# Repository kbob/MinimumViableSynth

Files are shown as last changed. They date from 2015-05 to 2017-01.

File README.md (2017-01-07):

# MinimumViableSynth

A virtual analog synthesizer with lots of knobs and buttons.

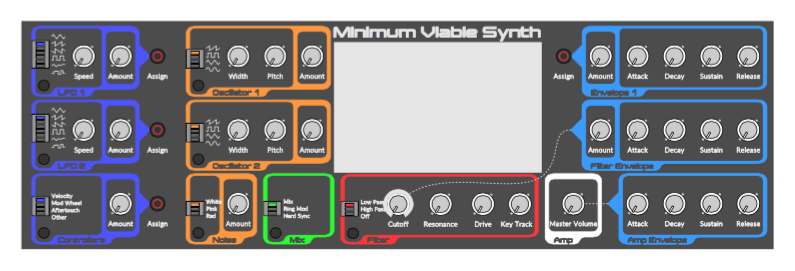
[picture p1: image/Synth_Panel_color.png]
front panel image


This is a polyphonic, monotimbral, virtual analog synth.  The audio
engine runs as an Apple Audio Unit on a Macintosh.  The control panel,
shown here, will provide dedicated controls for most of the synth's
functions.

assembly animation

The end goal is a self contained keyboard synth with knobs and buttons
with the classic connections: audio out, MIDI in/out, USB MIDI in/out.
I am getting there in three phases.

  * **Phase 1** (complete 2015-01-01): Softsynth.  The audio engine
    runs as an Audio Unit on a Mac.  It accepts MIDI messages and
    produces beautiful polyphonic analog sounds.  Or gritty,
    disturbing analog sounds.  It plugs in to DAW software (I use
    Logic Pro X).
    
  * **Phase 2** (in progress): Knobs and buttons.  I am designing and
    building a front panel (see above) with knobs, buttons, and an LCD
    touchscreen.  The goal is to make it as easy as possible to
    understand what the synth is doing at any time.

  * **Phase 3** (future): Stand-alone.  Build an enclosure that houses
    a keyboard, the knob and button panel, I/O jacks, and a processor
    (TBD) that can run the audio engine.  I'm looking at FPGAs...

## Why?

Learn stuff.  Music theory, DSP, PCB layout, CAD and machining, more.

## Status

Check out synth-notes.txt for my thoughts as I worked things out.

#### January 7, 2017:

I built 8 slave modules: the LFOs, the Controllers module, the
oscillators, the noise source, mixer, and filter.  I've since killed
the filter module, and one of the oscillators' LED has burnt out its
red component.  I have parts and tools to repair those; just haven't
done it yet.

I have working UI for the knobs and buttons.  Specifically, routing
between modulators and targets works, complete with lighting effects.

I made an enclosure from aluminum sheet and melamine end blocks, as
illustrated above.  It is flimsy, though, so that needs to be re-done.

I had the master, slaves, and LCD panel connected via a breadboard.
The breadboard wiring got flaky, so I stopped to design a PCB.  The
PCB snaps onto the back of the Discovery board, It routes video to the
LCD touch screen, SPI to the slaves, and serial MIDI to a future MIDI
I/O board.

I am currently designing the graphics for the LCD panel.

(Over a year since the last update.  Oops.)

#### December 17, 2015:

Three slave modules have been built.  (LFO1, LFO2, Controllers.)  All
the slave module PCBs are fabricated.

The master-slave communications are working over SPI.  The master
generates MIDI events.
[I can push a button on a slave and hear its effect on the audio
engine.](https://www.youtube.com/watch?v=dZsXk2Zf6Bg)

I blew up one of the LFO modules, probably with static discharge.  I
repaired it (swapped in a new Teensy LC), and it works now.  It was an
ugly repair.

Current tasks:

  + generating more MIDI events
  + experimenting with the LED animation
  + soldering up the rest of the slave modules
  + designing backing plates for the new slave modules

#### August 14, 2015:

The audio engine has been stable since January, though it does not
exactly match the front panel's feature set.

The front panel was fabricated in July.  I used a sheet of acrylic,
painted the underside black, then engraved the artwork through the
paint with a laser cutter.  Then the same laser cutter cut all the
holes for the controls.  It looks sharp, but not mass produced.
I got the work done at [InHaus Fabrication](http://inhausfabrication.com/).

There is a master microcontroller, an STM32F429, and each module has a
slave controller, a Teensy-LC.  Each slave directly drives a few
knobs, buttons, and LEDs.  The master will coordinate all the slaves
and provide the MIDI over USB interface.  I am currently writing SPI
drivers for master-slave communication.

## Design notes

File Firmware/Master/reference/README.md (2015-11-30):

This is a spreadsheet in Apple Numbers format.  (Proprietary, but I
like it.)

Each SPI bus's signals can be mapped to several pins.  Those are
recorded.

The 144 pin chip does not bring out pins PH2 and above.  Those are
shaded red.

Most of the pins are connected to a peripheral on the STM32F429IDISCOVERY
board.  The pins that are not used are shaded blue in the spreadsheet.
Some, but not all, of the used pins are labeled in the Discovery column.

The notes column shows how I plan to use the pins, especially the
SPI slave select pins.

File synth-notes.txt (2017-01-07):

2017-01-06
Bode Plots

Notes on generating Bode plots.
http://www.onmyphd.com/?p=bode.plot

----------------------------------
2017-01-05
Color spaces

http://www.poynton.com/PDFs/ColorFAQ.pdf

https://blog.noctua-software.com/procedural-colors-for-game.html

http://devmag.org.za/2012/07/29/how-to-choose-colours-procedurally-algorithms/

http://www.tigercolor.com/color-lab/color-theory/color-theory-intro.htm

http://www.brucelindbloom.com/

R'G'B' is a standardized RGB based on D50 white.
CIE X'Y'Z' is the perceptual color space.
CIE L*u*v* maps it onto a cube.
CIE L*C*h° maps it onto a cylinder.  Like perceptual HSV.

    Xn, Yn, Zn = (1, 1, 1)

    def RGB_to_XYZ(r, g, b):
        def linearize_rgb(r, g, b):
            ɣ = 2.2
            κ = 903.3
            def compand(v):
                if V <= 0.08:
                    return 100 * V / κ
                else:
                    return ((v + 0.055) / 1.055)**2.4
            r, g, b = r**ɣ, g**ɣ, b**ɣ
            r, g, b = [compand(v) for v in (r, g, b)]
            return (r, g, b)

        r, g, b = linearize_rgb(r, g, b)
        M = [[0.412453, 0.357580, 0.180423],
             [0.212671, 0.715160, 0.072169],
             [0.019334, 0.119193, 0.939555]]
        X, Y, Z = [sum(M[i][j] * R[j] for j in range(3)) for i in range(3)]
        return (X, Y, Z)

    def XYZ_to_Luv(X, Y, Z):
        def L_star(Y):
            if 0.008856 < Y / Yn:
                return 116 * (Y / Yn)**(1/3) - 16
            else:
                return 903.3 * (Y / Yn)
        def u_prime(X, Y, Z):
            return 4 * X / (X + 15 * Y + 3 * Z)
        def v_prime(X, Y, Z):
            return 9 * Y / (X + 15 * Y + 3 * Z)
        upn, vpn = u_prime(Xn, Yn, Zn), v_prime(Xn, Yn, Zn)
        up,  vp  = u_prime(X,  Y,  Z ), v_prime(X,  Y,  Z )
        L = L_star(Y)
        u = 13 * L * (up - upn)
        v = 13 * L * (vp - vpn)

    def XYZ_to_Lab(X, Y, Z):
        L, u, v = XYZ_to_Luv(X, Y, Z)
        a = 500 * ((X / Xn)**(1/3) - (Y / Yn)**(1/3))
        b = 200 * ((Y / Yn)**(1/3) - (Z / Zn)**(1/3))
        return (L, a, b)

    def Lab_to_LCh(L, a, b):
        C = sqrt(a**2 + b**2)
        h = atan(b / a)
        return (L, C, h)

----------------------------------
2016-12-16
Hand-editing KiCad PCBs

This command will remove all traces and vias.

   sed -i.bak -e '/(segment /d' -e '/(via /d' [^_]*.kicad_pcb

----------------------------------
2016-12-16
I/O Daughter Board revisions

The IODB v1.0 does not work.  Time to make v1.1.

Desired changes:

  - change solder mask clearance to keep from exposing ground plane.
  - change ground plane clearances to match 1bitsy or bmp.
    1Bitsy clearances:
      Solder mask clearance: 0.05mm
      Solder paste clearance: 0
      Zones (all):
        Clearance: 0.15mm
        Minimum width: 0.15mm
        Antipad clearance: 0.15mm
        Spoke width: 0.16mm
        Segments: 16
    BMPMv2.1b clearances:
      Solder mask clearance: ?
      Solder paste clearance: ?
      GND zone F.cu:
        Clearance: 0.2
        Minimum width: 0.2
        Antipad clearance: 0.2
        Spoke width: 0.21
      GND zone B.cu:
        Clearance: 0.2
        Minimum width: 0.2
        Antipad clearance: 0.2
        Spoke width: 0.25
  - move J1 beside J2.
  - relabel J1 and J2.
  - J1 pad has no solder paste cutout.
  - use a different connector for J2.
      Hirose FH12A-40S-0.5SH(55)
      HFK140CT-ND
  - use bigger chips for U11 and U12.
      SN74LV1T34DBVR
      296-37176-1-ND
  - increment the version number.
  - order board
  - order more parts...
      J2       HFK140CT-ND
      U3-U9    568-8285-5-ND
      U6       497-8387-1-ND
      U11 U12  296-37176-1-ND
      buttons  732-7004-1-ND
      10K 0603 311-10KGRTR-ND
  - order stencil

----------------------------------
2016-11-28
I/O Daughter Board silkscreen

72 dpi mockup:
   mockup is too big!  board is 472 px high, should be 66 mm.
   scale = 2.522.
   "Minimum Viable Synth" - Jupiter 90 pix, each line indented 5 spaces
   "V1.0", URL - Jupiter 15 pix.
   "Viable" - border, 1 pix.
   Align baseline of "V1.0" with descender of Synth
   Align left edge of "V1.0" with left edge of "Minimum"

3600 DPI actual artwork:
    90 * 50 / scale = 1783
    15 * 50 / scale = 297
    border width 16.

----------------------------------
2016-11-14
I/O Daughter Board Errata

As of commit e53f5b, I see eleven errors in the schematic.

 * LED_K is also called BKLT_K.
 * LED_A is also called BKLT_A.
 * CTOUCH_INT is not connected to the master.
 * CTOUCH_WAKE is not connected to the master.
 * SLV5A_MISO is also called SLV5A_MISO_Fred.
 * PWR_SENS is not connected to the master.
 * There are no power flags.
 * Vdd on Master port P1 should probably not be a power rail.
 * There are no bypass capacitors on the SPI crossbar chips.
 * There are no bypass capacitors on the STMPE811.
 * There are no bypass capacitors on the MIDI level converters.

----------------------------------
2016-11-13
MIDI board

Preliminary notes on the MIDI board.

The MIDI board will be all 5V.  Level converters are on the I/O Daughterboard.

MIDI in/out/through.  Nobody implements through!  Nobody spells it "through"!

(CA-033) MIDI 1.0 Electrical Specification Update [2014]

Olivier Pichenettes says "Prefer 6N137 Opto."
http://mutable-instruments.net/forum/discussion/5276/midi-input-with-optocouplers/p1

Octopart shows a zillion variations on "ferrite bead 1K@100MHz", even
from the same manufacturer.  Need to understand why.  The MMA spec
says the beads are optional, so the part selection is probably not
critical.

The MIDI spec mentions MMZ1608Y102BT for the beads.

----------------------------------
2016-11-10
I/O Daughter Board - Sections

Power
Video
Slaves
MIDI
Touch

----------------------------------
2016-11-09

Parts

  Barrel Jack
  Adafruit #373
  CUI PJ-102AH
  5 on hand

  64 pin headers
  Digi-Key SAM1212-32-ND
  Samtec SSW-132-01-T-D
  4 on hand; need 6

  LCD FPC Connector
  Digi-Key A100229CT-ND
  TE Connectivity AMP 4-1734839-0
  4 on hand

#  Slave SPI Headers
#  Digi-Key 455-1738-1-ND
#  JST B6B-PH-SM4-TB
#  need 48

  Slave SPI Headers
  Digi-Key WM1735-ND
  Molex PicoBlade 0530470610
  need 48

#  Serial Midi Header
#  Digi-Key 455-1736-1-ND
#  JST B4B-PH-SM4-TB
#  Need 6

  Serial Midi Header
  Digi-Key WM1733-ND
  Molex PicoBlade 0530470410
  Need 6

  Capacitive Touch Header
  Digi-Key OR748CT-ND
  Omron XF2L-0625-1A
  need 3

    Capacitive Touch Alt. Header 1
    BuyDesign.com CON06HT-1
    ordered 1

  3v3 Regulator
  Digi-Key 1016-1873-1-ND
  Exar SPX3819M5-L-3-3/TR

  LCD Backlight Driver
  Digi-Key FAN5333BSXCT-ND
  Fairchild FAN5333BSX
  need 3

  LCD Backlight Inductor
  Digi-Key 587-2028-1-ND
  Taiyo Yuden NR6012T100ME
  need 3

  LCD Backlight Diode
  Digi-Key MBR0540CT-ND
  Fairchild MBR0540
  need 3

  LCD Backlight Zener
  Digi-Key MM3Z24VT1GOSCT-ND
  ON Semi MM3Z24VT1G
  need 3

  Resistive Touch Controller
  Digi-Key 497-8387-1-ND
  ST STMPE811QTR
  need 3   

  SPI Buffers
  Digi-Key 568-8285-5-ND
  NXP 74HC244PW,112
  20 on hand

  MIDI level shifters
  Digi-Key 296-37177-1-ND
  TI SN74LV1T34DCKR
  need 9 (6 on this board, 3 on MIDI board)

  Filter capacitors for 24V section
  Digi-Key 1276-3010-1-ND
  Samsung CL21F105ZBFNNNE
  need 6

  Pushbuttons
  Digi-Key 732-7004-1-ND
  Würth 430182043816
  need 2

More parts

#  Slave SPI Connectors
#  JST PHR-6
#  9 on hand; need 16

  Slave SPI Connectors
  Digi-Key WM1724-ND
  Molex PicoBlade 0510210600
  need 16

  Slave Connectors, Slave End
  Digi-Key A33380-ND
  TE 5-102393-1

#  MIDI connectors
#  Digi-Key 455-1164-ND
#  JST PHR-4
#  10 on hand

  MIDI connectors
  Digi-Key WM1722-ND
  Molex PicoBlade 0510210400
  need 2

#  Slave SPI, MIDI Contacts
#  Digi-Key 455-2148-1-ND
#  JST SPH-002T-P0.5L
#  85 on hand; need 96 + 24

  Cables
  need 11 red, 11 black, 44 colored
  Red
    Digi-Key 0500588000-12-R1-ND
  Black
    Digi-Key 0500588000-12-B1-ND
  Brown
    Digi-Key 0500588000-12-N1-ND
  Blue
    Digi-Key 0500588000-12-L1-ND
  Orange
    Digi-Key 0500588000-12-A1-ND
  Yellow
    Digi-Key 0500588000-12-Y1-ND
  need 66

  Slave connectors
  Digi-Key A33380-ND
  TE 102393-1
  need 11
w idc ca

ChuckM recommends these.  952-1900-ND
             32 position: 952-2521-ND

----------------------------------
2016-11-08
Election Day

Components on the I/O Daughter Card
   barrel jack for power
   64 pin headers for master
   FPC 40 pin for LCD
   16 JST-PH connectors for slaves
   header for serial MIDI
   header for capacitive touch
     FPC ZIF 6 position, 0.5mm pitch
     Omron XF2L-0625-1A

   3v3 regulator: SPX3819M5-L-3-3
   22V Boost for backlight: FAN5333BSX

   STMPE811 for resistive touch
   6 74HC244PW octal buffers
   misc. passives

Which 3v3 regulator?
   Adafruit uses an MIC5225-3.3v on the TFT Friend.  150 mA.
   Teensy 3.2-3.6 use LP38691SDX-3.3/NOPB.  500 mA.
   Piotr uses SPX3819M5-L-3-3/TR.

Which backlight driver?
   Adafruit uses FAN5333BSX on the TFT Friend
   Piotr recommended the TPS61042.

Level Translator?
   Piotr is using 568-9224-1-ND on BMPMv2.1.

Optocoupler
   Olivier Pichenettes argues for the 6N137.
   http://mutable-instruments.net/forum/discussion/5276/midi-input-with-optocouplers/p1

----------------------------------
2016-11-07

Master Daughter card
Functional Spec

Barrel connector for +5V.
16 connectors for slaves with buffers
LCD connector
  40 pin FPC
  36 pins for LCD
  4 pins for touch
STMPE811 for resistive touch
external I2C header and 5V, 3.3V for capacitive touch
header for serial MIDI.  5V, serial in/out, ground.
header for 4 touch pins on FPC
Duplicate user and reset buttons.

----------------------------------
2016-11-07

Cross-checking STM32F429I-Discovery pinout.

Touch sensor (STMP#811) is missing.  Needs I2C bus.
    don't forget to connect the interrupt pin.
N.B., MB1075 schematic says "USB_OTF_FS" but actually uses _HS pins.
SWD pins are not in spreadsheet.
USB_OTG_HS pins are not in spreadsheet.
RCC_OSC pins are not in spreadsheet.

... and I ordered a panel with a capacitive touch sensor.  It is
completely incompatible with the resistive sensor on the Adafruit
panels.

I think I will draw room on the board for the STMP3811 chip, but will
also have an external header for connecting the capacitive sensor.

I used PG2 for the STMPE811 touch interrupt.

----------------------------------
2016-11-04

Looking for switched line buffers.

74LVC4066 - actually an analog switch.  Used in SiLabs dev board.
TS3A4751  - ditto
MC74VHC125 - quad bus buffer with 3 state control inputs
SN74AHC125 - quadruple 2-input positive-nand gates
SN74LVC1G125 - Single Bus Buffer Gate With 3-State Output
The last one is interesting.  It's a single gate on a 5-pin chip.

Update 11/7: I already bought some NXP 74HC244PW chips.  Octal buffer,
             one enable line for every four lines.  20 pin TSSOP package.
             Perfect.

----------------------------------
2016-09-17

If I'm tweaking a knob on a modulator, I want to see the modulator
parameters, but I also want to see how it affects the target module.
Do they both need to be visible side by side?

----------------------------------
2016-08-17

(Long time no update)

Let's list all the controls and think about what display we'd like to
see when each is changed.

Control: LFO1.waveform
Display: "LFO 1", "waveform", Scope of waveform.
         Graph shows blue highlights (how?) if LFO1.speed or
         LFO1.amount is being modified.

Control: LFO1.Speed
Display: "LFO 1", "Speed: 3.0 Hz", knob outline, graph of waveform.

Control: LFO1.Amount
Display: "LFO 1", "Amount: 0.5", knob outline, graph of waveform.

Control: LFO2.waveform, .speed, .amount
Display: as above.

Control: Osc1.waveform
Display: "Osc 1", "Pitch: +2 octaves, -2 semitones, +23 cents." or
         "Pitch: 2 8va  2♭  +23¢", knob outline, graph of waveform.

Control: Osc1.waveform
Display: "Osc 1", "Width: 5%", knob outline, graph of waveform.

... seems to be a pattern..

----------------------------------
2016-03-05

Here's a silly macro to wrap critical sections.

#define WITH_INTERRUPTS_MASKED                                          \
     for (bool wim_interrupts_are_masked = cm_is_masked_interrupts(),   \
               wim_first_time = (cm_disable_interrupts(), true);        \
          wim_first_time;                                               \
          wim_interrupts_are_masked ? (void)0 : cm_enable_interrupts(), \
          wim_first_time = false)

Use it like this.

    WITH_INTERRUPTS_MASKED {
        mutate_shared_state;
    }

----------------------------------
2016-02-19

FPGA Fun

    http://www.fpga4fun.com/

Algorithms

Sin and cos.

    This calculates sin (or cos) theta using two lookup tables, one
    for the high-order bits and another for the low-order bits.  That
    uses a smaller table than LERP, and has better resolution, at the
    cost of two load and two MAC operations per sample.  Probably
    works well on an FPGA.

    It uses these trig identities to decompose the angle.

        sin (a + b) = sin a cos b + cos a sin b
        cos (a + b) = cos a cos b - sin a sin b

    http://www.embedded.com/design/configurable-systems/4007682/5/What-s-your-sine-Finding-the-right-algorithm-for-digital-frequency-synthesis-on-a-DSP

    Here is the original paper.
    Sunderland, D.A., et al., CMOS/SOS Frequency Synthesizer LSI Circuit
    for Spread Spectrum Communications, IEEE Journal of Solid-State
    Circuits Vol. SC-19, No. 4, pp 497-506, August 1984.

    A similar trick would work for tanh, but would still require a
    divide.

        tanh (x + y) = (tanh x + tanh y) / (1 + tanh x tanh y)

Pink Noise Generator

    http://stenzel.waldorfmusic.de/post/pink/
    https://github.com/Stenzel/newshadeofpink

    This is a new pink noise generator.  It is fairly
    incomprehensible, but it looks well-suited to an FPGA.  The
    claimed spectrum is awesomely flat.  Paul Stoffregen uses it
    in the Teensy Audio Library.

----------------------------------
2016-02-06
Bugs

Here are the outstanding bugs, so I can stop thinking about them.

FIXED   The CTLRs module needs to be flashed.

FIXED   Animations for assignment destinations are bad.

FIXED   Knobs are too sensitive to noise.

FIXED   The display needs to follow the power-on protocol.

        USB writes hang when nothing is listening for them.

FIXED   Need to move SPI Group B Slave Select to a higher-current pin.

FIXED   gpio module doesn't support OSPEED, open collector, etc.

FIXED   slave self-test mode leaves choice LEDs on.

        libopencm3 should be a submodule.

FIXED   Remove "#if 0" dead code.

FIXED   CTLRs module needs to have missing pot wiper tied to ground.

----------------------------------
2016-01-18
The enclosure

The enclosure is supposed to be 3u rack mountable.  But I don't
actually plan to put it into a rack.  Instead, I'll put wooden end
pieces on it to prop it up at an angle.  I made an animated GIF.

Tomorrow I'm meeting a friend to fabricate two pieces of aluminum.
I'm calling them the inner and outer covers.  The inner cover is a
thin aluminum sheet, 0.019" (0.48 mm).  It wraps around the ends of
the electronics.  The front panel will rest on it at the ends.  It
will have holes on the ends and M5 nuts epoxied on so that end caps
(or rack ears) can be screwed on.

The outer cover is a very nice copper colored brushed aluminum that I
found at Home Depot.[1]  It wraps around the top and bottom of the
electronics and around the panel.

Since I like the copper color so much, I'm thinking about decorative
end caps.  I considered Plasti-Dip, tile, cut glass, stone, faux stone
finishes, bamboo, hardwood (cherry, mahogany or walnut).  I think I've
decided I want to paint MDF with a high gloss finish.  I'm looking
into candy paint now.

Ure-Kem has good information here.[2]

[1] http://www.homedepot.com/p/MD-Building-Products-12-in-x-24-in-Copper-Aluminum-Sheet-57525/205518999

[2] http://www.urekem-paints.com/candy-paint-colors

----------------------------------
2015-12-09

Going back to 2015-08-16 Color Indications, I had some big ideas about
animation.  To achieve that, I'm going to need at least one state
machine.

enum AssignmentState {
  AS_INACTIVE,
  AS_ACTIVE,
  AS_CONFIRMING,               // when the confirming animation runs.
};

Also need some other state.

size_t current_assignment_source; // module index or source index
uint32_t assignment_start_time;   // milliseconds
uint32_t assignment_confirm_time; // milliseconds

I'm also going to need some predicates.

   bool module_is_current(size_t module_index);
   bool module_is_active(size_t module_index);
   bool knob_is_working(size_t module_index, size_t knob_index);

It would be good to make these fast...

module_is_current() is easy -- always record the last modified module and
compare.

knob_is_working() is easy: kn_exported_value == ks_actual_value.

module_is_active() is hard.  Each module depends on a different set of
knobs.  Ideally, I'll have a list: Osc 1 depends on Osc1.Amount,
Filter.Cutoff, Env3.MasterVolume, Env3.Attack, Env3.Decay, and
Env3.Sustain.  (And maybe I missed a couple.)  Create an inverse map
that maps every control onto the set of modules it can affect, and
whenever that control is changed, reevaluate whether the module is
active.

----------------------------------
2015-12-09
MIDI-USB driver

I've read a little about how MIDI is encapsulated in USB, and I've
read a little of libopencm3's MIDI code.

USB-MIDI chops a MIDI data stream into 4 byte packets.  Each packet
has one byte of header and up to 3 bytes of MIDI.  The header has
a four bit Cable Number (up to 16 MIDI cables on a single USB
endpoint) and a four bit Code Index Number (CIN).  The CIN partially
duplicates the MIDI status byte.  E.g., CIN 9 means the packet
is a Note On message, which must start with a 0x9# byte.

So my plan to assemble packets in the MIDI layer and just pass them
through in the USB-MIDI layer is not so good.

EDIT: Oops, disregard.  It worked out fine.

----------------------------------
2015-12-05

There is another piece needed.

There is a module that handles HID events from the SPI-proto driver.
Call it Giraffe for now.

    Giraffe_SPI_handler(slave_status const *ss)
    {
        if choice button,
            increment choice according to rules;
            send MIDI CC message;
        if assign button,
            decide what it means;
            ...
        for each knob button,
            decide what it means;
            ...
        for each knob,
            ...
    }

This is where double clicks and more complex sequences are processed.

Either Giraffe or another module, Gazelle, handles incoming USB
requests.

    Gazelle_MIDI_SYSEX_handler(...)
    {
        if message is set_preset,
            ...;
        if message is get_preset,
            ...;
        // or something.  I don't really understand what SYSEX
        // messages are needed yet.
    
        // We probably want to handle Program Change messages too.
    }

Names for Giraffe?  Maybe it's the HID module or Gestures module?
In a traditional widget framework, it would be buried inside some
widget's implementation.  What does IOS call the thing that turns
raw touchscreen data into gestures?  (answer: Gesture Recognizers)

Gazelle is the high level MIDI responder.  MIDI foo.  MIDI manager.
MIDI executive (-:.  Or something.

When the touchscreen is implemented, I'll need a real gesture
recognizer.

----------------------------------
2015-12-04
Event-driven SPI driver

Let's think of an API.

    typedef void SPI_slave_state_handler(const slave_state *, void *user_data);

    void SPI_events_setup(void);
    void SPI_register_slave_state_handler(SPI_slave_state_handler);
    void SPI_handle_systick(void);
    void SPI_report_and_clear_stats(void);

Let's think of an implementation.

    typedef enum SPI_state {
        SS_IDLE,
        SS_START,
        SS_GROUP_DONE,
    } SPI_state;

    typedef struct SPI_stats {
        uint32_t ok_count[MOD_COUNT];
        uint32_t fail_count[MOD_COUNT];
    } SPI_stats;

    static volatile SPI_state state;
    static volatile int current_grp_idx;
    static spi_buf outgoing_packets[MOD_COUNT];
    static spi_buf incoming_packets[MOD_COUNT];
    static slave_state slave_states[MOD_COUNT];

  The systick handler would look like this.

    void SPI_handle_systick(void)
    {
        if (state == IDLE) {
            state = START;
            nvic_generate_software_interrupt(NVIC_EXTI0_IRQ);
        }
    }

  The DMA ISRs would look like this.

    void dmaX_streamY_isr(void)
    {
        state.active_bus_mask &= ~(1 << something);
        if (state.active_bus_mask == 0) {
            state = GROUP_DONE;
            nvic_generate_software_interrupt(NVIC_EXTI0_IRQ);
        }            
    }

  The soft interrupt does all the work.

    void exti0_isr(void)
    {
        switch (state) {

        case START:
            current_grp_idx = -1;
            /* FALLTHRU */

        case GROUP_DONE:
            int prev_grp_idx = current_grp_idx;
            current_grp_idx++;
            int current_grp = active_spi_groups(current_grp_idx);
            if (current_grp == NO_GROUP) {
                state = POSTPROCESSING;
                postprocess_SPI();
                state = IDLE;
            } else {
                state = ACTIVE;
                start_SPI_group(current_grp);
            }
            if (prev_grp_idx != -1) {
                int prev_grp = active_spi-groups(prev_grp_idx);
                process_SPI_group(prev_grp);
            }
            break;

        case ACTIVE:
        case IDLE:
        case POSTPROCESSING:
            assert(!"Unexpected SPI state");
            break;
        }
    }

    static void start_SPI_group(int grp)
    {
        int bus;
        for (int i = 0; (bus = active_spi_buses(grp, i)) != NO_BUS; i++) {
            size_t mod_idx = spi_to_module(grp, bus);
            const module_config *mod = &sc.sc_modules[mod_index];
            uint32_t msec = system_millis;
            size_t bytes_out =
                assemble_outgoing_packet(outgoing_packets[mod_idx],
                                         msec, mod);
            spi_start_transfer(bus,
                               outgoing_packets[mod],
                               incoming_packets[mod],
                               bytes_out);
        }
    }

    static void process_SPI_group(int grp)
    {
        int bus;
        for (int i = 0; (bus = active_spi_buses(grp, i)) != NO_BUS; i++) {
            size_t mod_idx = spi_to_module(grp, bus);
            const module_config *mod = &sc.sc_modules[mod_index];
            bool ok = parse_incoming_packet(incoming_packets[mod_index],
                                            sizeof incoming_packets[mod_index],
                                            mod_index,
                                            &slave_state[mod_index]);
 
            if (ok)
                SPI_stats.ok_count[mod_idx]++;
            else
                SPI_stats.fail_count[mod_idx]++;
        }
    }

    static void postprocess_SPI(void)
    {
        for all modules,
            (*slave_state_handler)(&slave_states[i]);
    }

----------------------------------
2015-12-04
USB-MIDI driver

Let's think of an API.

  void USB_MIDI_setup(void);

  // return 0 on success or an error code
  int USB_MIDI_enqueue(uint8_t *msg, size_t size);
  
  // This may receive more than one packet at a time.
  typedef void USB_MIDI_handler(uint8_t *pkt, size_t size, void *user_data);

  // returns the previous handler or NULL if none.
  USB_MIDI_HANDLER *USB_MIDI_register_handler(USB_MIDI_HANDLER *cb);

And then there could be some "porcelain" layers above that.  First,
drop the USB_ prefix.  At some point in the future, this could route
to USB or serial MIDI or both.

  void MIDI_setup(void);

  // return 0 on success or an error code
  int MIDI_enqueue(uint8_t *pkt, size_t size);
  
  typedef void MIDI_handler(uint8_t *pkt, size_t size, void *user_data);

  // returns the previous handler or NULL if none.
  MIDI_HANDLER *MIDI_register_handler(MIDI_HANDLER *cb);

Then specialize the send function on the various messages types.

  MIDI_send_note_off         (uint8_t channel, uint8_t note, uint8_t velocity);
  MIDI_send_note_on          (uint8_t channel, uint8_t note, uint8_t velocity);
  MIDI_send_poly_pressure    (uint8_t channel, uint8_t note, uint8_t pressure);
  MIDI_send_control_change   (uint8_t channel, uint8_t control, uint8_t value);
  MIDI_send_program_change   (uint8_t channel, uint8_t patch);
  MIDI_send_channel_pressure (uint8_t channel, uint8_t value);
  MIDI_send_pitch_bend       (uint8_t channel, uint16_t value);

  // Message must include leading 0xF0 byte
  MIDI_send_raw_SYSEX        (uint8_t const *message, size_t size);
  MIDI_send_MTC_quarter      (uint8_t type, uint8_t values);
  MIDI_send_song_position    (uint16_t beat);
  MIDI_send_song_select      (uint8_t song);
  MIDI_send_tune_request     (void);
  MIDI_send_timing_clock     (void);
  MIDI_send_start            (void);
  MIDI_send_continue         (void);
  MIDI_send_stop             (void);
  MIDI_send_active_sensing   (void);
  MIDI_send_reset            (void);
    
And similarly for receive.

  typedef void MIDI_note_off_handler         (uint8_t channel,
                                              uint8_t note,
                                              uint8_t velocity);

  typedef void MIDI_note_on_handler          (uint8_t channel,
                                              uint8_t note,
                                              uint8_t velocity);

  typedef void MIDI_poly_pressure_handler    (uint8_t channel,
                                              uint8_t note,
                                              uint8_t pressure);

  typedef void MIDI_control_change_handler   (uint8_t channel,
                                              uint8_t control,
                                              uint8_t value);

  typedef void MIDI_program_change_handler   (uint8_t channel,
                                              uint8_t patch);

  typedef void MIDI_channel_pressure_handler (uint8_t channel,
                                              uint8_t value);

  typedef void MIDI_pitch_bend_handler       (uint8_t channel,
                                              uint16_t value);

  typedef void MIDI_SYSEX_handler            (uint8_t const *message,
                                              size_t size);

  typedef void MIDI_MTC_quarter_handler      (uint8_t type, uint8_t values);

  typedef void MIDI_song_position_handler    (uint16_t beat);

  typedef void MIDI_song_select_handler      (uint8_t song);

  typedef void MIDI_tune_request_handler     (void);

  typedef void MIDI_timing_clock_handler     (void);

  typedef void MIDI_start_handler            (void);

  typedef void MIDI_continue_handler         (void);

  typedef void MIDI_stop_handler             (void);

  typedef void MIDI_active_sensing_handler   (void);

  typedef void MIDI_reset_handler            (void);

  #define REGISTER_HANDLER(type) \
    MIDI_##type##_handler MIDI_register_##type##_handler(MIDI_##type##_handler);
  REGISTER_HANDLER(note_off);
  REGISTER_HANDLER(note_on);
  REGISTER_HANDLER(poly_pressure);
  REGISTER_HANDLER(control_change);
  REGISTER_HANDLER(program_change);
  REGISTER_HANDLER(channel_pressure);
  REGISTER_HANDLER(pitch_bend);
  REGISTER_HANDLER(SYSEX);
  REGISTER_HANDLER(MTC_quarter);
  REGISTER_HANDLER(song_position);
  REGISTER_HANDLER(song_select);
  REGISTER_HANDLER(tune_request);
  REGISTER_HANDLER(timing_clock);
  REGISTER_HANDLER(start);
  REGISTER_HANDLER(continue);
  REGISTER_HANDLER(stop);
  REGISTER_HANDLER(active_sensing);
  REGISTER_HANDLER(reset);

And then specialize on all the channel control messages and RPNs and
NRPNs.  Also specialize on all the Universal SYSEX messages.  But I'm
going to stop typing here.

----------------------------------
2015-12-04
Master Firmware

The firmware on the master MCU (STM32) needs to have some tasks and
some interrupts.

There are lots of things happening.

    Based on a timer, the master polls the slaves through SPI.
    Some SPI responses cause MIDI-USB packets to be sent.
    MIDI-USB packets are received asynchronously.
    Some MIDI-USB packets causes MIDI-USB replies to be sent.
    The screen is updated often.
    The Chrom-Art accelerator has a queue of bit blts to do.

I see a bunch of interrupts and service routines, and three main
tasks.  From highest to lowest priority,

    Service USB queues
    Service SPI
    Draw screen

So the first two can be written as event handlers, and the screen I/O
will be the background tasks.  Screen I/O will be a mix of CPU drawing
and DMA2D drawing and compositing.  I don't want to work on the
graphics until the SPI and USB-MIDI are working well.

Lots of devices interrupt.  These are the ones I can think of.

    systick                NVIC_SYSTICK_IRQ
    SPI1 TX DMA complete   NVIC_DMA?_STREAM?_IRQ
    SPI3 TX DMA complete   NVIC_DMA?_STREAM?_IRQ
    SPI4 TX DMA complete   NVIC_DMA?_STREAM?_IRQ
    SPI5 TX DMA complete   NVIC_DMA?_STREAM?_IRQ
    serial                 NVIC_USART1_IRQ
    USB                    NVIC_OTG_FS_IRQ
    DMA2D                  NVIC_DMA2D_IRQ
    LCD refresh            NVIC_LCD_TFT_IRQ
                           NVIC_LCD_TFT_ERR_IRQ
    software interrupt     NVIC_EXTI0_IRQ
    software interrupt     NVIC_EXTI1_IRQ

Software interrupts are easy.  There are 23 of them, and for any one,
you just create an ISR function like this,

    void exti0_isr(void) { ... }

Initialize it like this.

        nvic_set_priority(NVIC_EXTI0_IRQ, 0xFF);
        nvic_enable_irq(NVIC_EXTI0_IRQ);

Trigger it like this.

        nvic_generate_software_interrupt(NVIC_EXTI0_IRQ);

Mutual exclusion is easy using mutices.

    typedef uint32_t mutex_t;

    void mutex_lock(mutex_t *m);
    uint32_t mutex_trylock(mutex_t *m);
    void mutex_unlock(mutex_t *m);

So, step one.  Write a USB driver that enqueues outgoing packets,
dispatches on incoming packets.  I think the queue entries can be
statically allocated.  We can have one for each possible message source?

This means we're going to start decoding MIDI.

----------------------------------
2015-08-26
Wiring

I'm going to create a daughterboard that plugs in to the back side of
the STM32F429IDISCOVERY.  It will have 12 or 16 connectors for slave
modules, and it will have a 44 pin connector for the video screen.

For the slave modules, I'm thinking about either Molex SL connectors
or RJ45.

RJ45 connectors are bigger, but Ethernet cables are cheap, plentiful,
and shielded with twisted pairs.  I only have to crimp-connect one end.

Molex SL connectors are small.  They have positive locking.  They work
very well in my printer.  Crimping 11 * 6 * 2 = 132 connectors will
make me an experienced crimper. (-:

It would be nice to use Molex SL on the slave boards, but...
  (a) They don't appear to be available in 3x2, and the boards are
      are already fabbed with 3x2 holes.
  (b) There is no room.
So I will stick with 6 pin headers there.

I should probably put some capacitance on the slave boards.

----------------------------------
2015-08-19
The Controllers Module

The idea is that any MIDI controller can be mapped to a synth knob.
There are many MIDI controllers.

  * CCs go from 0 to 119.

  * RPNs and NRPNs.

  * General MIDI has some SYSEX messages, e.g., Master Volume GM.
    I know of 8 GM SYSEX messages.

  * Where is Pitch Bend?

Maybe I should declare that no more than N controllers can be active
at once.  Then the synth state only has to process N things.  4 would
be the obvious number...

----------------------------------
2015-08-16
Color indications

Define an "active" module as one that affects the sound output.  E.g.,
an oscillator is active iff its amount is nonzero, the filter cutoff
is not subsonic (or supersonic if high-pass), and the amplitude
envelope has nonzero master volume and either attack, decay, or
sustain is nonzero.

Define a "working" knob as one whose value changes are generating MIDI
messages.  The opposite of "working" is "idle".  When a preset is
changed, all knobs whose current values don't match the preset's value
become idle.  When a knob is rotated to the preset value, it becomes
working.

Define the "current" module as the most recently touched module.
Similarly, the "current" knob is the most recently touched control,
unless a non-knob control has been touched last.  (XXX figure out what
to do when two knobs are being touched at the same time.)

A "modifier" is a module with an assign button.  A modifier has
a current destination and a set of valid destinations.  To assign
a modifier to a destination, click the assign button, then click
the new destination.

Clicking Assign activates assignment.  When assignment is active,

  - clicking Assign again leaves assignment.

  - clicking a different Assign button immediately deactivates
    assignment (bypassing animation) and activates assignment on the
    other module.

  - clicking the current destination deassigns the modifier and leaves
    assignment mode.

  - clicking a valid, noncurrent destination assigns the modifier to
    the new destination and leaves assignment mode.

  - clicking an invalid destination has no effect.

  - turning a knob has no effect.  (The knob may become idle.)

  - clicking a choice button deactivates assignment (bypassing
    animation) and selects the new choice.

  - doing nothing for 2 seconds leaves assignment mode.

When assignment mode is left, there is a brief animation.  The
unselected destinations go black immediately.  All knobs return to
their non-assignment-mode colors. The Assign button and the current
destination throb red once, then the Assign button goes black and
the current destination returns to its non-assignment-mode color.

The light for a module should be:

  - module color with throbbing if the module is active and current.

  - module color, solid (maybe dimmed) if the module is active
    but not current.

  - module color, dimmed and throbbing, if the module is current
    but not active.

  - off, if the module is neither active nor current.

The light for a knob should be:

  - blinking red with high duty cycle if a modifier assignment is
    active and the knob is the modifier's current destination

  - blinking red with low duty cycle if a modifier assignment is
    active, the knob is a valid destination, and it is not the
    modifier's current destination.

  - throbbing red once during post-assignment animation.

  - off if a modifier assignment is active and the knob is not a
    valid destination.

  - off if the module is currently inactive

  - dimmed module color if the knob is idle and not current.

  - dimmed complement of module color if the knob is working and not current.

  - throbbing module color if the knob is idle and current.

  - throbbing complement of module color if the knob is working and current.

But for now, I can just set all modules to module color and all knobs
to complement of module color.

----------------------------------
2015-08-14
MIDI CC Mappings

We will shortly have raw data from a bunch of controls.  We need to
turn that data into MIDI messages.

The config has:
    controller's SYSEX address
    several module configs.

A module_config has:
    SPI address
    MIDI SYSEX address
    color
    optional choice control
    0-5 knob controls
    optional assign control
    predicate that determines whether it's active

A choice control config has:
    a MIDI CC number
    number of options

A knob control config has:
    a MIDI CC number
    optional LSB CC number
    RGB status LED number
    flag indicating button presence
    optional button press handler
    function that maps MIDI CC values to user values

An assign control config has:
    a MIDI CC number
    a list of destinations and a MIDI CC value for each
    
That should be enough to describe the modules' static configuration.

The controller's state has:
    current preset name, number
    several modules' states

A module's state has:
    reference to a module_config
    flag indicating module is active
    current status LED color/pattern

A choice control's state has:
    reference to choice_config
    current value

A knob control's state has:
    reference to knob_config
    exported value
    actual value
    flag indicating that actual value should be exported

An assign control's state has:
    reference to assign_config
    current value

That seems like enough to start implementing. 

----------------------------------
2015-06-05
Master-Slave protocol

The master (STM32F429i-Discovery) and the slaves (Teensy-LC)
communicate over the SPI bus.  The master sends a MOSI message, and
the slave simultaneously sends a MISO message.  The messages are
exchanged at frequent intervals.  (I intended it to be once a
millisecond but the SPI buses are getting noise about 250 KHz, so it's
more like once every 3 msec.)

Each slave runs the exact same firmware image, so it does not know
what type of module it is until the master tells it.

MOSI message format

  STX : 1 byte
  config 0 : 1 byte
    bit 0:      c1 = nonzero if choice one lit
    bit 1:      c2 = nonzero if choice two lit
    bit 2:      c3 = nonzero if choice three lit
    bit 3:      c4 = nonzero if choice four lit
    bit 4:      c5 = nonzero if choice five lit
    bit 5:      c6 = nonzero if choice six lit
    bit 6:       (not used)
    bit 7:      ap = nonzero if assign LED lit
  config 1: 1 byte
    bits 0-2:   np = number of pixels
    bits 3-5:   na = number of analog inputs
    bits 6-7:   unused
  choice LED pwm: 1 byte per lit choice
  assign LED pwm: 1 byte
  pixels: 3 * np bytes
    1st: title
    2nd - np'th: knobs
    red, green, blue order
  checksum : 2 bytes
  ETX : 1 byte

MISO message format

  STX : 1 byte
  switches: 1 byte
    bit 0: c0 clicked
    bit 1: assign clicked
    bit 2: destination button 1 clicked
    bit 3: destination button 2 clicked
    bit 4: destination button 3 clicked
    bit 5: destination button 4 clicked
  analog: 1 byte
    bit 0: analog 1 changed
    bit 1: analog 2 changed
    bit 2: analog 3 changed
    bit 3: analog 4 changed
    bit 4: analog 5 changed
  analog values:  1 byte per changed value
  checksum : 2 bytes
  ETX : 1 byte

The checksums are Fletcher16 and are calculated over the 2nd through
n-4th bytes.  (i.e., starting after the initial STX, up through the
byte before the checksum.)  The checksum is MSByte first.

----------------------------------
2015-06-01

Board Prices

I designed six boards and had each fabricated by OSHPark.  OSHPark
gives you three copies for $5/square inch.  I designed the controls so
that I can use more than one of some of the boards.  That helped reduce
the fabrication cost, though it raised the system complexity.

    Board              Number           Price
                        Used
    LFO Small 1.0         3             27.55
    Filter 1.0            1             39.45
    Oscillator 1.0        2             29.00
    Duo 1.0               2             14.50
    Envelope 1.0          3             37.00
    Master Volume 1.0     1              9.65
                                      -------
    TOTAL                              159.15

The synth uses twelve boards, six designs.

The easier approach would have been to fabricate one board at 17.25 x
5.25.  OSHPark would have charged $453.  I probably could have gotten
it somewhat cheaper elsewhere, but OSHPark's 3fer pricing worked out.

The other way to look at it is that one big board is 90.5 square
inches, and the smaller boards (ignoring duplicates) total 32 square
inches.

Anyway, now I have to attach all those boards to a chassis and make a
whole lot of cables.

----------------------------------
2015-05-30
Module Dimensions

Each control is 21.5 mm wide.  (Too narrow, I know.)
The module PCB is up to 43.5 mm high.
The bottom left corner of the PCB is at the corner of the module.
The top right corner is wherever it needs to be.
The top of the paddles is at y = 38.25 mm

    Teensy:
        x = 9.08 mm   (approx)
        y = 19.05 mm  (approx)

    SPI header:
        x = 7.79 mm   (approx)
        y = 39.73 mm  (approx)

    Title WS2812 LED:
      x = 20.65 mm
      y = 5.55833125 mm

    Choice LED:
        x = 7.08 mm
        y = 25.471 mm

    Choice button:
        x = 9.035 mm
        y = 7.451040625 mm

    Potentiometer, WS2812, assign button position:
        x = (N + 1/2) * 21.5 mm
        y = 24.451 mm

    Destination switch position:
        x = (N + 1/2) * 21.5 mm
        y = 7

    Screw holes by assign button
        x = (N + 1/2) * 21.5 mm
        y = 10, 37

    Spine:
        y = 38.25 mm

    Paddles:
        left       = (N * 21.5 + 2) mm
        right      = (N * 21.5 + 2) mm
        top        = 30 mm
        bottom     = 3.5 mm
        radius     = 2.54 mm
        stem width = 6 mm

The filter module is different.  The positions of the filter controls
are not calculated yet.

----------------------------------
2015-05-30

Pin assignments on the modules' Teensy-LC boards.

Each module has a Teensy-LC microcontroller board.  I want to run the
same firmware image on each board, so the pin assignments need to be
the union of all the uses on all the modules.

The required functions are:
    4 SPI pins (SCK0, MOSI0, MISO0, CS0)
    1 WS2812 strand (5V)
    1 choice button
    6 choice LEDs (PWM, not 20mA)
    5 knob wipers (ADC)
    4 destination buttons
    1 assign button
    1 assign LED (PWM)

Here are the assignments.

    Teensy     Attributes        Use
     Pin        (subset)
      0                          choice button
      1                          destination button 3
      2                          destination button 4
      3        PWM               choice LED 1
      4        PWM               choice LED 2
      5        20mA              destination button 1
      6        PWM               choice LED 3
      7        MOSI0             destination button 2
      8        MISO0             assign button
      9        PWM               choice LED 4
     10        PWM,CS0           SPI
     11        MOSI0             SPI
     12        MISO0             SPI
     13        SCK0,LED          SPI
     14/A0     ADC,SCK0          knob wiper 1
     15/A1     ADC               knob wiper 2
     16/A2     ADC,PWM,20mA      knob wiper 3
     17/A3     ADC,PWM,5V,20mA   WS2812 strand
     18/A4     ADC               knob wiper 4
     19/A5     ADC               knob wiper 5
     20/A6     ADC,PWM           choice LED 5
     21/A7     ADC,20mA           -
     22/A8     ADC,PWM           choice LED 6
     23/A9     ADC,PWM           assign LED
     24/A10    ADC                -
     25/A11    ADC                -
     26/A12    ADC                -

----------------------------------
2015-05-28
Color scheme

Since I have four colors of LED DIPs, I'll differentiate the modules
by color.

   BLUE:  LFOs and Controllers
   AMBER: Oscillators and Noise
   GREEN: Mixer
   RED:   Filter

2015-05-01

Gauss Boys has this diametrically oriented ring magnet.
http://www.gaussboys.com/store/index.php/magnet-shapes/rings/rd0906.html

AMS has magnetic multipole rings.  Most interesting is the MR20-44.
It has 44 poles.  Combined with the AS5311, that would give 2048 x 44
points of rotational resolution.
http://ams.com/eng/Products/Position-Sensors/Magnets/AS5000-MR20-44
http://ams.com/eng/Products/Position-Sensors/Linear-Incremental-Magnetic-Position-Sensors/AS5311

Even better, the AS5510 Linear Sensor can measure a single magnet
(such as the Gauss Boys RD0906 above) with 10 bits' precision.  It has an
i2c interface.

----------------------------------
2015-04-26

At DorkBotPDX last Monday, I met Jeff Miller.  He showed me his servo
that he modified to do continuous rotation under Bluetooth control.

The project code and schematics are here.
https://github.com/portlandrobotics/btServo

The magnetic rotary encoder chip is an ams AS5050.
ams has many encoders.  http://ams.com/eng/Products/Position-Sensors

----------------------------------
2015-03-22

SPI communications

The Teensy-LC has a system clock of 48 MHz.  Its SPI 1 can run at
system clock / 4, or 12 MHz.  Its SPI 0 can run at bus clock / 4.
The bus clock is the system clock divided by 1-8.

The Beaglebone Black has 2 McSPI sections, each capable of ?? MHz.

The STM32F429 has six SPI interfaces at up to 45 Mbit/sec and an
additional four SPI-like UARTS at 5.62 Mbit/sec.

----------------------------------
2015-03-20

interprocessor communication

There will be a bunch of small uCs, probably Teensies, connected to a
central CPU, probably a BeagleBone.  Each will have a SPI connection.
The SPI connection will carry data bidirectionally.

   inbound
     button changes
     pot readings
     keyboard timing
   outbound
     knob LED colors/patterns
     module LED colors/patterns

What LED patterns should there be?

   assignable
   assigned
   active
   inactive
   locked in

----------------------------------
2015-03-20

Ordered TE Micro-MaTch and E-Switch from Mouser.

----------------------------------
2015-03-16
Shopping List

Ordered 100 WS812B RGB LEDs.
Need Micro-MaTch connectors.
Need more TL-1220 halo buttons and more Alpha pots.
Will need to order boards from OSHPark.
May need a bunch of Teensy LC boards.

 6  TE MicroMaTch 1-215079-6    0.92  Mouser
10  TE MicroMaTch 8-215083-6    0.84  Mouser

15  E-Switch TL1220R1BBBRHALO   3.26  Mouser

50  Alpha 1400F                1.20  Small Bear

----------------------------------
2015-03-13

http://tangentsoft.net/elec/movies/

Need some op amps.
Need some voltage regulators, both 3.3v and 5v.
Need capacitors.  220uF.

----------------------------------
2015-03-08

Keyboard uses TE Micro-MaTch connectors.

Female on board: 215079-16
Male on wire: 215083-16
Ribbon cable: 167019

Get 10 of each.

N.B., Piher PT-15 is a shaftless 360 degree potentiometer.

Piher MTS-360 is a shaftless magnetic rotary encoder with 14 bits
resolution.  $70 each, though.

----------------------------------
2015-03-04

Analogue Haven order number 2375-7979-9624

----------------------------------
2015-03-01

The 40 greatest synth sounds of all time… ever!
http://www.musicradar.com/us/news/tech/the-40-greatest-synth-sounds-of-all-time-ever-306114

----------------------------------
2015-02-28
Letter to Piotr

I have been looking at all kinds of options, including FPGA, Zynq,
GPU, polynomial sigmoid functions, reading the glibc math intrinsics,
and probably some other things.  Here is what I know.

The centerpiece of the synth is the Moog ladder filter.  The ladder
filter is unreasonably expensive to simulate.  It needs five (5) tanh
calculations per sample.  Monophonic is fine -- the BeagleBone could
do that, just barely.  But for polyphony, around 20 notes is the
minimum, and if I go multitimbral, there should be another factor of
several.  I've set 64 notes as my multitimbral target.  (Presently I
can run 24 notes on one core of the MacBook.  That should scale nearly
linearly to four cores, and if I rearrange the code to take advantage
of the SSE instructions, there should be another factor of less than
four available.  Intel's CPU designers and Apple's compiler team are
hard to compute^Wcompete with.

The cheapest way to calculate tanh on an FPGA is with CORDIC.  The
claim is, "CORDIC needs about as many gates as multiply."  That means
a CORDIC transcendental function is cheaper than a polynomial
approximation or Taylor series. (But most FPGAs have
multiply-accumulate blocks, which CORDIC wouldn't use.)

There is no CORDIC function for tanh directly, but it can
simultaneously calculate sinh and cosh, and tanh x = sinh x / cosh x.
Division can be implemented as a second CORDIC block.  However, CORDIC
hyperbolics only converge if the argument is less than 1.12.  I don't
know what to do about that.

A Taylor series needs about 20 terms to give 24 bit precision on tanh.

There don't appear to be any insoluble problems implementing the
ladder filter in an FPGA, though I don't know how many gates it would
need.  I think the envelope generators, mixer, ring modulator, voltage
controlled amplifiers (actually Numerically Controlled Amps, but VCA
is the acronym I know), and noise sources also appear feasible.
Loading MIDI events (or equivalent) into the FPGA is something I don't
know how to do yet, but it shouldn't be too bad.

The hard part is the oscillators.  The oscillators are band limited,
and they potentially change frequency and/or waveform every sample.  I
wrote a lot (a *lot*) of conditional code to handle all the edge
cases.  A single sample could, in worst case, be the sum of five
antialiasing polynomials, in addition to its base value.  I think I
need a completely different oscillator algorithm.  I've started
researching it, but don't have any conclusions yet.  (In software, the
oscillators are cheap, as 99% of the samples don't require any
antialiasing work.)

I'm assuming that an FPGA solution would have a very fast, very
pipelined "engine", and it would multiplex a bunch of different
voices.  E.g., if it ran at 20 MHz, and sample rate is 0.2 MHz, then
it could alternate between 100 different voices each sample period.
That way, the whole FPGA could be dedicated to one instance of the
engine.

So that's FPGAs.

I've been thinking about a hybrid where the oscillators and mixer run
on the CPU and the filter and final amplifier run on an FPGA..  (See
attached diagram.)  Each voice has four sample streams entering the
FPGA.  At 192 KHz * 3 bytes/sample, that's 2.3 MB/sec per voice.  One
of the sample streams is the actual audio from the mixer; the other
three are control voltages (magenta in the diagram).  It would be
possible to implement the LFOs and envelope generators in parallel
both on the CPU and the FPGA (they're cheap, at least in software),
and then it would only be necessary to pass a single sample stream and
the much lower bandwidth MIDI event stream.  0.6 MB/sec/voice, 38
MB/sec for 64 voices.  That's still a lot of data and a lot of
synchronization to be done, but not impossible.

Notes about the diagram and the synth architecture.  Yellow functional
units and data flows are the audio path.  Yellow units are polyphonic
-- one instance per note.  Blue units are monophonic.  Green are
polyphonic.  "Control Voltages" (continuously varying signals) are
magenta.  Each control voltage except Env 1 can be assigned to any of
about 25 inputs to other units.  The LFOs also have CV inputs.
"Wheel" is a stand-in for any of about 10 MIDI channel control
messages -- my keyboard has a mod wheel, so that's the one I
implemented first.  At present, each CV can drive a single input, but
that is only a UI limitation.

The LOGi-Bone (not sure about the capitalization) has a DMA interface
to the BBB.  A friend who has one has pushed 40 MB/sec through it.

So that's hybrids.

As best I can tell, the BeagleBone Black's FPU just isn't very fast.
But I've also been looking at whether glibc's math intrinsics are
unoptimized.  I don't have any conclusions yet.  FYI, here are my
benchmark results on the BBB.  This runs just the ladder filter and
counts how many simultaneous notes it can process.

Notes   Implementation
-----   --------------

 1      #define TANHF(x) (tanhf((x)))
 1      #define TANHF(x) (my::tanhf((x)))
 3      #define TANHF(x) (lerp::tanhf((x)))
 4      #define TANHF(x) (lerp::tanhf2((x)))
10      #define TANHF(x) (mclamp::clamp((x)))
 5      #define TANHF(x) (pade::tanh_approx((x)))
 5      #define TANHF(x) (isqrt::sigmoid((x)))
 7      #define TANHF(x) (isqrt::naive_sigmoid((x)))
 3      #define TANHF(x) (raphx::tanhf((x)))
18      #define TANHF(x) (x)

In each case, the data is 32 bit float.

  tanhf is the libm intrinsic.
  my::tanhf is (expf(2 * x) - 1) / (expf(2 * x) + 1)
  lerp::tanhf uses linear interpolation tables, with frexpf() to unpack floats
  lerp::tanhf2 is same, using union and bitfields to unpack floats.
  mclamp is max(-1, min(x, +1))
  pade is (x**3 + a) / (b x**2 + c)
  sigmoid is x / sqrt(x * x + 1) using the SGI inverse sqrt trick.*
  naive_sigmoid is same, using the sqrtf intrinsic.
  raphx is { t = x + a x**3 + b x**5; return t / sqrt(1 + t**2); }
using the fast sqrt trick*
  (x) is just skipping the tanh calculation completely.

  * https://en.wikipedia.org/wiki/Fast_inverse_square_root
  I suspect that the ARM inverse sqrt instruction implements this.

mclamp, sigmoid, and (x) are not acceptable substitutes.  tanhf,
my::tanhf, lerp, and raphx are acceptable.  I don't know about pade;
I'd need to do some spectral tests.  naive_raphx might be a little
faster, since ARM has an inverse sqrt instruction.  it doesn't matter,
though, because 1, 1, 3, 4, 5, and 3 are all far less than the minimal
20.  I can't see how that gap will be closed.

It's possible that gcc is emitting really bad code for ARM or that
libm is really bad.  I looked at gcc's assembler for some simpler
samples and verified that it's actually generating FP and NEON
instructions, but didn't look at any of the benchmark code.  A few of
the benchmarks skip libm completely, and none of them are fast.

So I dunno.  I looked a little at the UDOO and ODroid offerings today.
They are faster chips, and I found a benchmark somewhere that showed
the ODroid about 3-4x faster than the BBB.  There's probably room to
tune my code a little, once I know what target I'm tuning for.  I
should talk to Brad Stewart (do you know him?) since he's a Freescale
guy and he was recently making his own synth too.

So that's ARM.

I really don't know about Zynq or the Parallella.  In theory, 16
FP-centric CPUs should be ideal for this problem.  It will cost me
$200 to find out (and they're out of stock now anyway).

The ARM core in a Zynq is a dual-core Cortex-A9 with NEON.  The
version in the Parallella runs at 800 MHz.  A little better than the
BBB.

How are the tools for Parallella?  Does the Epiphany have a C
compiler?  Is there documentation on running the ARM core sans OS?

And I don't know much about DSPs.  As I understand it, they're general
purpose CPUs optimized for integer vector and matrix multiplication.
Not much of my code fits that criterion.

I downloaded the documentation for the Raspberry Pi's GPU.  I didn't
get a good sense of the GPU's capabilities, though.  I'm guessing that
what I'm doing is far enough from what 3D renderers do that it's
unlikely to go well.

There are only 4 billion different floating point numbers.  tanh(x) ==
x for small x, and tanh(x) == 1 for large x, and tanh(-x) == -tanh(x),
so there are less than 128M cases where tanh needs to be looked up.
How much is 512Mbytes of EPROM?

So that's "other".

The thing is, any of these is a major engineering effort.

----------------------------------
2015-01-19

Annotated example code to configure LCD output.
http://en.radzio.dxp.pl/stm32f429idiscovery/tft-lcd-controller.html

----------------------------------

Sparkfun has an interesting 7 inch, TFT display w/ touchscreen
packaged as a BeagleBone cape.  $99.
    https://www.sparkfun.com/products/12086

It is available direct from the manufacturer for $10 less.
    http://www.4dsystems.com.au/product/4DCAPE_70T

And it is based on the CircuitCo LCD7, which is ~$150.

Adafruit has:
    1932     9.95   40-pin TFT Friend - FPC Breakout with LED Backlight Driver
    1596    39.95   5.0" 40-pin TFT Display - 800x480 with Touchscreen
    2098     4.50   40-pin FPC Extension Board + 200mm Cable

----------------------------------
2015-01-08

Solder paste
Kester R276 lead-free
available at GoKimCo and at All-Spec.

----------------------------------
2015-01-06
more knobs...

http://www.okw.co.uk/en/Tuning-knobs-E-Mech-components/Tuning-knobs-with-LED-illumination.htm
http://mutable-instruments.net/forum/discussion/1107/the-good-knob-and-pots-encoders-thread/p1

----------------------------------
2015-01-05

Adafruit has TFT displays.

1596 - 40 pin TFT display 800x480 with Touchscreen
1571 - Resistive Touch Screen Controller - STMPE610
1590 - RA8875 Driver Board for 40-pin TFT Touch Displays - 800x480 Max
1932 - 40-pin TFT Friend - FPC Breakout with LED Backlight Driver

----------------------------------
2015-01-04
Control Specifics

Small knob, single turn smooth

  3 Env.attack
  3 Env.decay
  3 Env.release
  3 Env.keytrack
  1 Flt.keytrack
  1 MW.amount

Small knob, single turn smooth, pushbutton, indicator

  2 LFO.speed
  3 Env.sustain
  2 Osc.width
  1 Flt.drive

Small knob, single turn center detent, pushbutton, indicator

  2 LFO.amount
  3 Env.amount

Big knob, single turn smooth, pushbutton, indicator

  1 Flt.cutoff
  1 Flt.resonance

Switch/pushbutton

  1 MW.destination
  2 LFO.destination
  3 Env.destination
  2 LFO.waveform
  2 Osc.waveform
  1 Noise.spectrum
  1 Mix.operator
  1 Flt.type

Small ptr knob, single turn 8 clicks

  2 Osc.octave

Big ptr knob, infinite turn 12 clicks, pushbutton, indicator

  2 Osc.semi

Big knob, single turn center detent

  2 Osc.fine

Big ptr knob, lots of clicks

  2 Osc.detune

Slider

  3 Mix.level
  1 master volume

----

  Which controllers should be assignable?  I can see aftertouch,
  mod wheel, breath, and expression (if that's the pedal).

----------------------------------
2015-01-04

Shopping!

        Mouser

          STM32F4 Discovery boards
          switches, potentiometers, encoders, misc.

ORDERED Small Bear Electronics
          knobs
          rotary switches
          clear shaft pots

NOSTOCK Stencils Unlimited
          solder paste (Kester R276 lead-free)

ORDERED Zephyrtronics
          plunger
          tips

ORDERED Digilent
          DAC
          ADC

NOSTOCK TME
          SR knobs
          SR chickenhead knobs

        Adafruit
          pyralux
          toy motors

        Sparkfun
          soft potentiometers
          clear shaft rotary encoder
          clear knob

----------------------------------
2015-01-04
Solder Pastes

Discussion pages:
https://learn.adafruit.com/smt-manufacturing/solder-paste-syringes
https://forum.sparkfun.com/viewtopic.php?f=14&t=24745
https://www.sparkfun.com/tutorials/58

Recommended:
Kester 256 (Sparkfun, Sparkfun commenter)

Not recommended:
Chipquik

----------------------------------
2014-12-31

Bourns PRM16 series
motorized potentiometers

Bourns ES series
shaftless rotary encoders

I also might be able to use either a servo or a motor from a servo.

Bajillions of 12 position rotary switches are available.

Sparkfun has D-shafts and others.
https://www.sparkfun.com/categories/250

Google for "toy motor".  Adafruit has one.

Sparkfun "soft potentiomeer"
https://www.sparkfun.com/products/8678

Digilent PMODI2S - i2s stereo output breakout

Digilent PMODAD5 - 4 channel 24 bit A/D breakout

I think I need to think about the exact requirements for each knob.

----------------------------------
2014-12-30

Greg Norman says check out Parts Express for knobs and hardware.

Taper found Piher potentiometers.
http://piher.net/sensors/index.php?product_id=41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

----------------------------------
2014-12-29

Piotr pointed me at these rotary encoders.

http://www.megatron.de/en/products/hall-effect-singleturn-rotary-encoder/hall-effect-absolute-encoder-series-mab12ah.html

He also recommended looking into brushless gimbal motors from the R/C
world.

And piezoelectric haptic actuators.

----------------------------------
2014-12-25

On Christmas morning, instead of opening presents, I am unpacking
the Oxygen's memory dump format.

We get 100 SysEx messages in the dump.  Certain patterns can be
observed.

                   /---- checksummed: sum % 128 == 0 ----\
f0  0  1  5 10 7f  2  1  13  0  0  0  0  0  0  0  ... 0 6a f7
 ^  ^  ^  ^  ^  ^  ^  ^                                  ^  ^
 |  |  |  |  |  |  |  |                                  |  |
 |  |  |  |  |  |  |  |     checksum             --------+  |
 |  |  |  |  |  |  |  |     f7: end SysEx        -----------+
 |  |  |  |  |  |  |  +---  program number, 1-10
 |  |  |  |  |  |  +------  counts from 2-b (10 messages per pgm)
 |  |  |  |  |  +---------  device ID
 |  |  |  |  +------------  always 10.  Oxygen?
 |  +--+--+--+------------  always 0 1 5.  allegedly M-Audio's Mfr ID.
 +------------------------  f0: begin SysEx

Msg 7 byte 10: 0a for ctl 154, 09 for ctl 155
Msg 8 byte  9: C18 CC number
Msg 8 byte  3: ???

P01 C1    14
    C2    15
    C3    16
    C4    17
    ---
    C5    18
    C6    19
    C7    20
    C8    21
    ---
    C9    22

    C10   23   55  (23 drawbar)
    C11   24   56  (24 drawbar)
    C12   25   57
    C13   26   58
    ---
    C14   27   59
    C15   28   60
    C16   29   61
    C17   30   62

    C18  102        0-12
    C19  103        0-5
    C20  104        0-12
    C21  105  111   0-5, 0-4
    ---
    C22  106  112   0-14, 0-12
    C23  107        0-2
    C24  108        0-3
    C25  109        0-3
    ---
    C26  110        0-2

----------------------------------
2014-12-24

Knobs, buttons, and sliders again.

The synth engine has 26 analog parameters and 12 multiple-choice
parameters.  The keyboard has 9 sliders, 8 dials, and 9 buttons.

Here's my proposed mapping, split across keyboard progrms 1 and 2.

                 PGM 1                PGM 2

   Slider C1     LFO 1 Amount         same
   Slider C2     LFO 2 Amount         "
   Slider C3     Env 2 Amount         "
   Slider C4     Filter Fc            "
   ---
   Slider C5     Filter Q             "
   Slider C6     Filter Drive         "
   Slider C7     Mix Osc 1            "
   Slider C8     Mix Osc 2            "
   ---
   Slider C9     Mix Noise            "

   Knob C10      Osc 1 Width          LFO 1 Speed
   Knob C11      Osc 2 Width          LFO 2 Speed
   Knob C12      Osc 2 Coarse         Env 2 Keytrack
   Knob C13      Osc 2 Fine           Filter Keytrack    x
   ---
   Knob C14      Env 1 A              Env 2 A
   Knob C15      Env 1 D              Env 2 D
   Knob C16      Env 1 S              Env 2 S
   Knob C17      Env 1 R              Env 2 R

   Button C18    Mod Wheel Assign     "
   Button C19    LFO 1 Waveform       "
   Button C20    LFO 1 Dest           "
   Button C21    LFO 2 Waveform       Filter Type
   ---
   Button C22    LFO 2 Dest           Env 2 Dest
   Button C23    Mix Operator         "
   Button C24    Osc 1 Waveform       "
   Button C25    Osc 2 Waveform       "
   ---
   Button C26    Noise Spectrum       "

Here are the default MIDI controller numbers.

                 PGM 1                PGM 2
   Slider  C1    74 Cutoff Freq       73 Attack Time
   Slider  C2    71 Resonance         75 -
   Slider  C3    91 Reverb Depth      72 Release Time
   Slider  C4    93 Chorus Depth      74 Cutoff Freq
   Slider  C5    73 Attack Time       79 -
   Slider  C6    72 Release Time      84 Porta Ctrl
   Slider  C7     5 Porta Time        91 Reverb Depth
   Slider  C8    84 Porta Ctrl        93 Chorus Depth
   Slider  C9     7 Channel Vol        7 Channel Vol

   Knob   C10    75 -                 16 GP 1
   Knob   C11    76 -                 17 GP 2
   Knob   C12    92 Tremolo Depth     18 GP 3
   Knob   C13    95 Phaser Depth      10 Pan
   Knob   C14    10 Pan               19 GP 4
   Knob   C15    77 -                 80 GP 5
   Knob   C16    78 -                 81 GP 6
   Knob   C17    79 -                 20 -

   Button C18    0/32/0 Pgm Change    24/127 -
   Button C19    0/32/1 Pgm Change    25/127 -
   Button C20    0/32/2 Pgm Change    26/127 -
   Button C21    0/32/3 Pgm Change    27/0   -
   Button C22    0/32/4 Pgm Change    44/0   -
   Button C23    0/32/5 Pgm Change    45/0   -
   Button C24    0/32/6 Pgm Change    46/0   -
   Button C25    0/32/7 Pgm Change    47/0   -
   Button C26    0/32/8 Pgm Change   (dead)

----------------------------------
2014-12-24

MVSNote::Render()
{
    const MVSParamSet *params = mParams;

    // Copy the monophonic modbox.
    MVSModBox     modbox      = **mModBoxPtrPtr;
    size_t        nsamp       = modbox.sampleCount();
    typedef float buf[nsamp];

    // Initialize the polyphonic modbox by adding a buffer for env2.
    buf           env2_values;
    modbox.set_values(Mod::Env2, env2_values);

    // Get the (oversampled) output buffer.
    float        *render_out  = *mOversampleBufPtr;

    float         sample_rate = SampleRate();
    float         frequency   = Frequency();
    float         norm_freq   = Frequency() / SampleRate();

    // - - - - - - -        Envelope 2               - - - - - - - - - -

    {
        buf attack, decay, sustain, release, amount;

        modbox.modulate(params->env2_attack,  Mod::Env2Attack,  attack);
        modbox.modulate(params->env2_decay,   Mod::Env2Decay,   decay);
        modbox.modulate(params->env2_sustain, Mod::Env2Sustain, sustain);
        modbox.modulate(params->env2_release, Mod::Env2Release, release);
        modbox.modulate(params->env2_amount,  Mod::Env2Amount,  amount);
        mEnv2.generate(attack, decay, sustain, release, amount, env2_values);
    }

    // - - - - - - -        Oscillator 2             - - - - - - - - - -

    buf osc2_out;
    buf osc_sync;
    {
        buf freq, width;
        float coarse_detune = params->osc2_coarse_detune;
        float fine_detune   = params->osc2_fine_detune;
        float detune        = coarse_detune + fine_detune / 100;
        float base_freq     = norm_freq * powf(2.0, detune);
        float base_width    = params->osc2_width / 100;

        modbox.modulate(base_freq, Mod::Osc2Freq, freq);
        modbox.modulate(base_width, Mod::Osc2Width, freq);
        if (params->mix_operator == Mix::HardSync) {
            buf sync_in;
            sync_in[0] = nsamp + 1; // no sync events
            mOsc2.generate_with_sync(params->osc2_waveform,
                                     freq,
                                     width,
                                     osc2_out,
                                     sync_in,
                                     osc_sync,
                                     nsamp);
        } else {
            mOsc2.generate_modulated(params->osc2_waveform,
                                     freq,
                                     width,
                                     osc2_out,
                                     nsamp);
        }
    }

    // - - - - - - -        Oscillator 1             - - - - - - - - - -

    buf osc1_out;
    {
        buf freq, width;
        float base_freq = norm_freq;
        float base_width = params->osc1_width / 100;

        modbox.modulate(base_freq, Mod::Osc1Freq, freq);
        modbox.modulate(base_width, Mod::Osc1Width, freq);
        if (params->mix_operator == Mix::HardSync) {
            buf sync_out_unused;
            mOsc1.generate_with_sync(params->osc1_waveform,
                                     freq,
                                     width,
                                     osc1_out,
                                     osc_sync,
                                     sync_out_unused,
                                     nsamp);
        } else {
            mOsc1.generate_modulated(params->osc1_waveform,
                                     freq,
                                     width,
                                     osc1_out,
                                     nsamp);
        }
    }

    // - - - - - - -        Noise Source             - - - - - - - - - -

    buf noise_out;
    mNoise.generate(params->noise_spectrum, noise_out, nsamp);

    // - - - - - - -        Mixer                    - - - - - - - - - -

    buf mixer_out;
    {
        float osc1_level  = scale_dB40(params->mix_osc1_level);
        float osc2_level  = scale_dB40(params->mix_osc2_level);
        float noise_level = scale_dB40(params->mix_noise_level);

        mMixer.generate(params->mix_operator,
                        osc1_out,
                        osc1_level,
                        osc2_out,
                        osc2_level,
                        noise_out,
                        noise_level,
                        mixer_out,
                        nsamp);
    }

    // - - - - - - -        Filter                   - - - - - - - - - -

    buf filter_out;
    {
        buf cutoff, resonance, drive;

        modbox.modulate(params->flt_cutoff,    Mod:FltCutoff, cutoff);
        modbox.modulate(params->flt_resonance, Mod:Resonance, cutoff);
        modbox.modulate(params->flt_drive,     Mod:Drive,     cutoff);
        mFilter.generate(params->flt_type,
                         cutoff,
                         resonance,
                         drive,
                         filter_out,
                         nsamp);
    }

    // - - - - - - -        Envelope 1               - - - - - - - - - -

    buf env1_values;
    {
        buf attack, decay, sustain, release, amount;

        modbox.modulate(params->amp_attack,  Mod::AmpAttack,  attack);
        modbox.modulate(params->amp_decay,   Mod::AmpDecay,   decay);
        modbox.modulate(params->amp_sustain, Mod::AmpSustain, sustain);
        modbox.modulate(params->amp_release, Mod::AmpRelease, release);
        modbox.modulate(params->amp_level,   Mod::AmpLevel,   amount);
        mEnv1.generate(attack, decay, sustain, release, amount, env1_values);
    }

    // - - - - - - -        Amplifier                - - - - - - - - - -

    mAmplifier.generate_sum(filter_out, env1_values, render_out);

    return noErr;
}

----------------------------------
2014-12-22

Categories for synth.

    Synth Engine

        signal
           time-series data stream

        monophonic signal
        polyphonic signal
           poly signals have one instance per active note.

        operator
           combines signals to create new signal

        modulator
           signal that affects another signal

        monophonic modulator
        polyphonic modulator

        graph
           network of signals and operators

    External

        parameter
           user-visible setting

        signal parameter
           parameter whose value is a signal

        routing parameter(?)
           parameter

        event
           external stimulus that affects engine state.

        controller
           event source
           (i.e., MIDI message type)

    I have no idea where I'm going with this...

----------------------------------
2014-12-21

Connecting to an STM32F4.

    I see nine peripherals.  Did I miss any?
        Audio Out
        Keyboard in
        Knobs in
        Buttons in
        Velocity in
        Aftertouch in
        MIDI in/out
        USB in/out
        LEDs out

    How do aftertouch and velocity work?
    I think the aftertouch is just another potentiometer.
    I think the velocity is derived from timing of the key switches.
    They appears to have separate make/break contacts.

    Assume several AD7193s for the knobs in.  I don't know what does the
    buttons.

    Interfaces
        Audio Out: i2s
        Keyboard in: GPIOs?
        Knobs In:  SPI
        Buttons in: ????
        Velocity in: ????
        Aftertouch in: SPI (via AD7193)
        MIDI in/out: USART
        USB in/out: HS USB OTA
        LEDs out: GPIO

    Several of these could/should use DMA:
        Audio out
        Knobs in (including aftertouch)
        MIDI in/out (optional)
        USB in/out
        LEDS out
    But the STM32F4 only has 3 DMA channels, plus a dedicated channel
    for USB.

    The key switches need 24 pins.  8 outputs and 16 inputs.  Maybe
    I need a Teensy for the keyboard. (-:

----------------------------------
2014-12-21

Today's fun fact: Monophony and Polyphony are examples of musical "Textures".

    enum Texture {
        Monophony,
        Polyphony,
        Biphony,
        Homophony,
        Heterophony,
        // etc.
    };

----------------------------------
2014-12.20

How about this?

    class Modulator {
    public:
        modulate_freq(freq_buf, nsamp);
        modulate_linear(scale, buf, nsamp);
        modulate_dB(scale, buf, nsamp);
    };

    class LFO : public modulator {
        // ...
    };

A modulator can either be a vector of values or it can be a
vector of values with a vector of scale factors.

No, we just need to know whether we need a bipolar or unipolar output.

Let's have the modulation source map.

srcmap[NDEST][NMOD];
mapcount[NDEST];
memset(srcmap, 0, sizeof srcmap);
memset(mapcount, 0, sizeof mapcount);
for (i = 0; i < Mod::Destination::Count; i++)
    srcmap[mod_dest][mapcount[mod_dest]++] = mod;

How to add a frequency?
    freq[i] *= powf(2.0, mod[i]);

The caller wants to say something like

    fill_param(params->osc1freq, modifiers[Mod::Osc1Freq], buf, nsamp);

(probably with one more parameter to establish whether param is
linear, exponential, etc.)

Then MVSNote::Render has this structure.

{
    float env2_values[nsamp];
    if (env2_mods_itself)
       fill(0,env2_values, nsamp);
    else {
        // Do env2;

        float attack[nsamp];
        float decay[nsamp];
        float sustain[nsamp];
        float release[nsamp];
        float amount[nsamp];
        fill_param(params->env2_attack, Mod::env2_attack, attack, nsamp);
        fill_param(params->env2_decay, Mod::env2_decay, decay, nsamp);
        fill_param(params->env2_sustain, Mod::env2_sustain, sustain, nsamp);
        fill_param(params->env2_release, Mod::env2_release, release, nsamp);
        mEnv2.generate(... ??? ...);
    }

    if (params->mix_operator != Mix::HardSync) {
        float osc1_values[nsamp];
        {
            float freq[nsamp], width[nsamp];
            fill_param(params->osc1_freq, Mod::Osc1Freq, freq, nsamp);
            if (waveform_has_width(params->osc1_waveform)) {
               fill_param(params->osc1_width, Mod::Osc1Width, width, nsamp);
            mOsc1.generate(...);
        }

        float osc2_values[nsamp];
        {
            float freq[nsamp];
            float width[nsamp];
            fill_param(params->osc2_freq, Mod::Osc2Freq, freq, nsamp);
            if (waveform_has_width(params->osc2_waveform)) {
               fill_param(params->osc2_width, Mod::Osc2Width, width, nsamp);
            mOsc2.generate(...);
        }
        float o1level[nsamp], o2level[nsamp];
        fill_param(params->mix_osc1_level, Mod::Osc1Level, o1level, nsamp);
        fill_param(params->mix_osc2_level, Mod::Osc2Level, o2level, nsamp);
        if (params->operator == Mix::RingModulate)
            for (size_t i = 0; i < nsamp; i++)
                mix_values[i] = (o1level[i] * o2level[i] *
                                 osc1_values[i] * osc2_values[i]);
        else
            for (size_t i = 0; i < nsamp; i++)
                mix_values[i] = (o1level[i] * osc1_values[i] +
                                 o2level[i] * osc2_values[i]);
    } else {
        // get parameters...
        mOsc2.gen_with_sync(...);
        mOsc1.gen_with_sync(...);

    }

    // Generate the noise source.
    float noise_values[nsamp];
    mNoise.generate(params->noise_spectrum, noise_values, nsamp);

    // add in the noise source.
    float nlevel[nsamp];
    fill_param(params->mix_noise_level, Mod::Noiselevel, nlevel, nsamp);
    for (size_t i = 0; i < nsamp; i++)
        mix_values[i] += nlevel[i] * noise_values[i];

    // XXX filter goes here

    // XXX need envelope generator with continuous modulation.
    // XXX for now, fudge it.

void ModBox::fill_param(const FloatParam& scalar, Mod::Destination mods, float
*values_out, size_t count)
{
    fill(scalar, values_out, count);
    if (mw_dest == dest) {
       add(param->wheel_amount, wheel_values, values_out, count);
    }
    if (lfo1_dest == dest)
       add(1, LFO1_values, values_out, count);
    if (lfo2_dest == dest)
       add(1, LFO2_values, values_out, count);
    if (env2_dest == dest)
       add(1, env2_values, values_out, count);

struct ModBox {
    const float *matrix[Mod::DestinationCount][MOD_COUNT + 1];
};

Now the matrix needs to have a longer lifetime and be updated only
when the assignments change.  Where to put it?

class ModMatrix {

public:

    void set_mod(mod, dest)
    {
        old_dest = dest_vec[mod];
        if (old_dest)
            remove_mod(mod, dest);
        if (dest_vec[mod])
           for (i = 0; i < MOD_COUNT && src{matrix[dest][i]; i++)
               continue;
           src_matrix[dest][i] = mod;
    }

    void remove_mod(mod, dest)
    {
        for (i = 0; i < MOD_COUNT && src_matrix[dest][i]; i++)
            if (src_matrix[dest][i] == mod) {
                break;
            }
    }

private:
    // map dest -> [modulator]
    size_t src_matrix[Mod::DestinationCOunt][MOD_COUNT + 1];
    // map modulator -> dest;
    Mod::Destination dest_vec[MOD_COUNT];

};

----------------------------------
2014-12-19

How are we going to connect all this stuff up?

MVS::Render allocates and fills the LFO buffers.
Checks whether LFO2 modifies LFO1.

There are dependencies.

There are 2 oscillators, 1 noise source, 1 mixer, 1 filter, 1 amp, 1
mod wheel, 2 LFOs, and 2 envelope generators.  11 modules in all.
(The hard-sync mixer kind of breaks that model, but ignore that for now.)

They form a graph.  Each node has 0 or more inputs and 1 output.
Each output is another node's input.

There are 25 modulable inputs.  Some are summed with fixed inputs.

----------------------------------
2014-12-19

LFO

    The Nord Lead manual says that some LFO waveforms are bipolar
    and some are unipolar.

        The modulation of the LFOs are unipolar, with a few
        exceptions. Pitch (OSC1, OSC2) and PW modulations with
        triangle, S&H and Random waveforms are bipolar. Pan modulation
        with all waveforms are bipolar.

    I could adopt a similar thing.

    I don't think LFOs need to be antialiased.

    Nord Lead 4's LFO destinations:
       Filter
       OSC MOD
       OSC MIX
       OSC 1
       OSC 2
       OSC 1 + 2
       Amplitude
       Pulse Width
       Pan
       Effects

    StudioLogic Sledge's LFO destinations:
        Osc 1
        Osc 1 + 2
        Osc 1 + 2 + 3
        Osc 2 + 3
        Osc 3
        PWM  (doesn't say which oscillator(s))
        Volume
        Cutoff

    I have:
       Osc 1 freq
       Osc 1 width
       Osc 2 freq
       Osc 2 width
       Noise level
       Filter cutoff
       Filter resonance
       Filter Drive
       Env 2 amount

    I should add:
      Osc 1+2 freq
      Osc 1+2 width
      LFO 1 speed   (from LFO2 only)
      LFO 1 amount  (  "    "   "  )

----------------------------------
2014-12-19

Parameters.
We have two types: floats and enums.

Render needs to be able to fetch a float or an enum instantly.
We have inline functions operator float() and operator E().
Renderer always knows the parameter's actual type.

The host has a different idea of the param's value.
Host never knows a parameter's actual type.

A float param is simple: there is just one value.
An enum param has both the renderer's value, e.g., Saw,
and the host's value, e.g., 0.

operator E returns the render's value.
get_value() returns the host's value.

The enum param also needs a way to back map from render values to
host.

So let's deprecate IntParam (but leave it in for now) and define
EnumParam<T> and EnumParamBase.  The mValue field moves from Param
to FloatParam.

mType and enum Type can go away too.

----------------------------------
2014-12-18

A/D modules
Digilent PmodAD5 - 8 channels, 24 bits, 4.8 KHz.
Analog Devices AD7193 - the chip: 10 channels.

----------------------------------
2014-12-17

Sometimes easy things seem hard.

Parameters...

   * goal: describe each parameter once.
   * goal: access each parameter quickly from MVSNote::Render().

Currently, MVSNote::Render() calls GetGlobalParameter(index).
The call tree looks like this.

    MVSNote::Render
        SynthNote::GetGlobalParameter -- not inline
            AUElement::GetAudioUnit   -- inline
            AUBase::Globals           -- inline
                AUScope::GetElement   -- not inline
            AUElement::GetParameter   -- not inline

So Render needs some kind of constant-time reference thing.
Maybe paramset has fixed fields.

    struct ParamSet {
        struct {
            Param waveform;
            Param width;
        } osc1;
        struct {
            Param coarse_detune;
            Param fine_detune;
            Param waveform;
            Param width;
        } osc2;
        // ...
    };

Then each note can have a ParamSet reference.

Or maybe I go back to the big enum.  There are so many ways to solve
this in Python...

Oh, wait.  Objects are initialized in decl order.  All I have to do is
have them register themselves as they initialize.

Param::Param()
{
    the_registry.add_param(this);
    ...
}

Then ParamSet is a singleton, and the MVS and the MVSNote both refer
to it.

I think there's something there that would work...

----------------------------------
2014-12-16

Parameter definitions:

    MVS::MVS()
    {
        Clump *osc1 = mParams.add_clump("Oscillator 1", "Osc1");

        osc1->add_param("Waveform")
            .value_strings(AR_osc_waveform_strings)
            .default_value(SAW);

        osc1->add_param("Width")
            .min_max(0, 1)
            .default_value(0)
            .display(PERCENT);

        Clump *osc2 = mParams.add_clump("Oscillator 2", "Osc2");

        osc2->add_param("Coarse Detune")
            .min_max(-64, +64)
            .default_value(0)
            .display(MIDI_NOTE);

        osc2->add_param("Fine Detune")
            .min_max(-100, +100)
            .default_value(0)
            .display(CENTS);

        osc2->add_param("Waveform")
            .value_strings(AR_osc_waveform_strings)
            .default_value(SQUARE);

        osc2->add_param("Width")
            .min_max(0, 1)
            .default_value(0)
            .display(PERCENT);

        Clump *noise = mParams.add_clump("Noise Source", "Noi");

        noise->add_param("Spectrum")
            .value_strings(noise_spectrum_strings)
            .default_value(WHITE);

        Clump *mixer = mParams.add_clump("Mixer", "Mix");

        mixer->add_param("Combiner")
            .value_strings(mix_combiner_strings)
            .default_value(MIX);

        mixer->add_param("Oscillator 1 Level")
            .min_max(-40, 0)
            .default_value(0)
            .display(DECIBELS);

        mixer->add_param("Oscillator 2 Level")
            .min_max(-40, 0)
            .default_value(-40)
            .display(DECIBELS);

        mixer->add_param("Noise Level")
            .min_max(-40, 0)
            .default_value(-40)
            .display(DECIBELS);

        // filter...
        // amp...
        // LFO 1...
        // LFO 2...
    }

----------------------------------
2014-12-15

Using the Oxygen 49's controls.

9 Sliders:
         LFO 1 amount
         LFO 2 amount
         env 2 amount
         filter Fc
         filter resonance
         filter drive
         mix osc1
         mix osc2
         mix noise

9 Buttons:
        LFO 1 waveform
        LFO 1 assign
          LFO 2 waveform    P01 only
          LFO 2 assign      P01 only
            env 2 assign    P02 only
        osc 1 waveform
        osc 2 waveform
        noise spectrum
        mix operator
            filter type    P02 only
        mod wheel assign

8 Knobs:
            LFO 1 speed          P02
            LFO 2 speed          P02
            env 2 A              P02
            env 2 D              P02
            env 2 S              P02
            env 2 R              P02

            env 2 keytrack       P02
        osc 1 width          P01
        osc 2 width          P01
        osc 2 coarse detune  P01
        osc 2 fine detune    P01
            filter keytrack      P02
        amp A                P01
        amp D                P01
        amp S                P01
        amp R                P01

I think the sliders should have those fixed functions, and the
keyboard's Programs should switch the functions of the buttons
and knobs.  Maybe P1 should have LFOs 1 and 2, and P2 should
have LFO 1 and env 2.

----------------------------------
2014-12-15

The param data structure.

    AR_osc_waveform_map = {
                        { SAW,    "Saw" },
                        { SQUARE, "Square/Pulse" },
                        NULL
                        };

    Clump osc1("Oscillator 1");
    IndexedParam(osc1, "Waveform", AR_osc_waveform_map)
        .default_value(SAW);
    Param(osc1, "Width")
        .min(0)
        .max(1)
        .display(PERCENT);

Does this go in the constructor?  Are Clump and Param factories?
Have a parent "root" object that the clumps attach to?

Param and IndexedParam are functions that put children into the clump.
Clump is likewise.  The whole thing comes out as a root object.

ParamSet has Clumps.
Clump has Params.

    ParamSet mParams;
    Clump *osc1 = mParams.add_clump("Oscillator 1", "Osc1");
    osc1->add_param("Waveform")
        .value_strings(AR_osc_waveform_strings)
        .default_value(SAW);
    osc1->add_param("Width")
        .min_max(0, 1)
        .default_value(0)
        .display(PERCENT);

    Param& AddParam(Clump&, const char *name);

This can also pick up some of the MIDI mapping / LFO assignment stuff.

----------------------------------
2014-12-15

Status:
    oscillators can change waveform on the fly.
    oscillators are ready for hard sync.
    I feel the need for a global LFO pool.

Next Steps:

  * Create a parameter data structure.  Migrate the current params
    into it.

      - Collect all info about a param in one place.
      - Make it obvious how params are grouped.
      - Make it easier for MVSNote::Render to get the current settings.
      - Implement centralized de-zippering.

  * Create two global LFOs.  Render them in MVS::Render() and make
    linkage so MVSNote::Render can find them.  Give each LFO an assign
    parameter.  (At first, the only assignment destinations will be
    OSC1 freq and OSC2 freq.)

  * Make the mod wheel assignable.

  * Create the Mixer.  Have it drive the oscillators.

      - Work hard to keep the logic in MVS::Render() tidy.

  * Investigate high-, band-, notch-pass ladder filters.

----------------------------------
2014-12-14

Naming the synth.
Minimum Viable Synth has worked pretty well.
I'm thinking Model A.
Update 12/23:
   ... or Tin Lizzie or Thin Lizzie.
Update 2015-05-31:
   ... Model A being a pun on Analog Modeling.
       Wikipedia says Tin Lizzie was the Ford Model T, not the Model
       A.  The Model A is also known as the A-Bone. (?)

----------------------------------
2014-12-14

My waveforms don't line up.

There is audible clicking when switching between sine and triangle
because the absolute amplitude change is big.  I think I need to
adjust the phase of all waveforms so that they click less on
transitions.  Either that or I need to briefly mute the oscillator on
transitions.

----------------------------------
2014-12-12

Clear knobs
http://smallbear-electronics.mybigcommerce.com/fluted-miniature-colored-pointer/
https://www.sparkfun.com/products/10597
http://www.tme.eu/en/details/gtp6m-13x16-s/shaft-resistors-knobs/sr-passives/#
Albs DK16-190V3

Clear chickenhead knobs
http://www.tme.eu/en/details/gw6m-20x14-p/shaft-resistors-knobs/sr-passives/#

Clear shaft potentiometers
http://smallbear-electronics.mybigcommerce.com/alpha-clear-shaft-pots-w-bushing/

Clear shaft rotary encoder
https://www.sparkfun.com/products/10982

Pushbuttons
NKK HB series: 9mm round or square, single-color LED (but LED is separate)
HKK HB2 series: bicolor LED
E-Switch TL 1220 7-10mm, tactile, ring illuminated, bicolor
E-Switch TL 1265 4.5-8mm, tactile

Pushbutton with bitmap display!
NKK ISC15ANP4
(obsolete: NKK IS01DBFRGB)

----------------------------------
2014-12-10

Analogue Haven sells raw Fatar keyboards.
www.analoguehaven.com

----------------------------------
2014-12-10

Modulation architecture

Instead of having a dedicated modulator (LFO and/or envelope
generator) for every parameter that might need one, most synths have a
small number of LFOs and some kind of routing capability.

Studiologic Sledge has three LFOs.  Each can be routed to one of eight
destinations:
        OSC 1
        OSC 1+2
        OSC 1+2+3
        OSC 2+3
        OSC 3
        PWM/WAVE FM
        VOLUME
        CUTOFF
It has two envelope generators hardwired to the amplifier and the
filter cutoff.

Nord Lead 4 has two LFOs.  They can be routed to one destination at a time.
        filter    - filter frequency
        OSC MOD   - modulates the oscillator modulation amount
                    (when osc 1 frequency modulates osc 2)
        OSC MIX   - oscillator mixer
        OSC 1     - pitch of oscillator 1
        OSC 2     - pitch of oscillator 2
        OSC 1 & 2 - pitch of both oscillators
        AM        - amplitude
        Pan       - left/right
        PW        - oscillator pulse width
        FX        0 effect amount

N.B., Nord Lead 4 LFOs are positive-only in most cases.
N.B., Nord Lead 4 LFOs don't do sine waves.

Nord Lead 4 has one modulation envelope gnerator.  It has seven
destinations:
        OSCMIX
        OSCMOD
        OSC1
        OSC2
        OSC1 + OSC2
        FX
        LFO2

----------------------------------
2014-12-03

Issues

Q: Noise source has no bass.  Designed for 44.1 KHz, running at 176.4 KHz.
A: Fixed.

Q: How can I have noise release slower than the tones?
A: Don't need to.

Q: Need better resolution on osc. 2 detune.  How about two parameters:
   detune notes and detune cents?
A: Fixed.

Q: Need better sync/unsync of LFOs.
A: N.B., Nord Lead 4's LFOs are monophonic.

----------------------------------
2014-11-30
Strategy for Ring-Mod

Ring mod generates sum and difference frequencies.  For every
frequency A and B present in the two sources, ringmod(A, B) produces A
+ B and A - B.  So, if the highest frequencies present are Fs/2, then
ringmod produces Fs.

I need to filter the oscillators down to Fs/4, then the ring mod can't
produce higher frequency than Fs/2.  A good way to do that would be to
use a higher-order polyBLEP with a lower cutoff.  Instead of sinc(x),
approximate sinc(x/2).  I don't know how high the polygon order needs
to be.

When mixing oscillators, the current BLEP/BLAM is good.  When ring
modulating, use the bigger filter.

----------------------------------
2014-11-29
What's next?

We have an oscillator with four waveforms and modifications on two.
We have an LFO.
We've fixed up the ADSR envelope generator.
We've got 500 voice polyphony (maybe).
So what's next?

Noise source.
Second oscillator.
Ladder filter.
Ring mod.
Hard sync.
Sample & Hold
Monophony.
Arpeggiator
Alternate tunings.

----------------------------------
2014-11-29
LFO

Call the LFO for oscillator 1 vibrato.
Parameters:
  osc 1 vibrato depth
  osc 1 vibrato speed
  osc 1 vibrato waveform

depth: 0 - +/- 600 cents.  Default: 0
speed: 0.1 Hz - 30 Hz.  Default: 3 Hz?
waveforms: saw, square/pulse, triangle, sine.  Default: sine
Leave out pulse width/triangle skew for now.

----------------------------------
2014-11-23
Plumbing for oversampling

Override AUInstrumentBase::Render.
  Find/allocate/clear new buffer 4X bigger.
  Call super::Render()
  Decimate/copy into output buffers.

In MyNote::Render,
  Ignore buffer(s) passed in.
  Ignore SampleRate().
  Get pointer to 4X buffer.  (How?)

----------------------------------
2014-11-17

OSStatus MVS::Note::Render(UInt64            inAbsoluteSampleFrame,
                           UInt32            inNumFrames,
                           AudioBufferList **inBufferList,
                           UInt32            inOutBusCount)
{
    // get 1st bus

}

----------------------------------

class Oscillator {

public:
    enum OscillatorType {
        OT_Sine,
        OT_Saw,
        OT_Triangle,
        OT_Pulse,
    };

    Oscillator(OscillatorType type, Float64 basefreq);

    void generate(float *sampBuf, UInt32 count);
    void generate_modulated(float *sampBuf, Float64 *freqs, UInt32 count);

private:
    const OscillatorType mType;
    const Float64        mBaseFreq;

};

----------------------------------
2014-11-16

class Envelope {

public:
    enum EnvelopeType {
        ET_Linear,
        ET_Exponential
    };
    Envelope(float        attackTime,
             float        delayTime,
             float        sustainLevel,
             float        releaseTime,
             EnvelopeType type = ET_Exponential);
    void release();

    void generate(float *sampBuf, UInt32 count);

private:
    enum EnvelopeSegment {
        ES_Attack,
        ES_Decay,
        ES_Sustain,
        ES_Release
    };
    bool         mIsReleased;
    EnvelopeType mType;
    float        mLevel;
    float        mAttackTime;
    float        mDelayTime;
    float        mSustainLevel;
    float        mReleaseTime;
};

----------------------------------
2014-11-12

VCA parameters.
    Amp Attack Time (msec: 0 - 5000)
    Amp Decay Time (msec: 0 - 5000)
    Amp Sustain Level (dB: -inf -- 0)
    Amp Release Time (msec: 0 - 5000)
    Amp LF form
    Amp LF speed
    Amp LF depth
    Amp Volume

----------------------------------
2014-11-12

It's time to enumerate the parameters.

MVS: Minimum Viable Synth.

No parameters.
VCO just does sawtooth.
VCA just does boxcar envelopes.  Jaggy ones.

----------------------------------
2014-11-07

Simplified Audio Unit Class Hierarchy

AUBase
  AUEffectBase
  AUMidiBase
    AUInstrumentBase
      AUMonotimbralInstrumentBase
      AUMultitimbralInstrumentBase
    AUMIDIEffectBase

Project templates:

Audio Unit
  Generic Audio Unit
  Audio Effect           ('aufx')
  Monotimbral Instrument ('aumu')
  MIDI Effect            ('aumf')

Audio Unit Constants
    'auou' Output           (kAudioUnitType_Output)
    'aumu' Music Device
    'aumf' Music Effect
    'aufc' Format Converter
    'aufx' Effect
    'aumx' Mixer
    'aupn' Panner
    'auol' Offline Effect
    'augn' Generator

TemplateInfo keys in Bundle.xctemplate:
    Ancestors
    Concrete
    Definitions
    Identifier
    Kind
    Nodes
    Options
    SortOrder
    Targets

----------------------------------
2014-10-25
Synth architecture - general idea

Four module types:
  VCO
  Noise Source
  VCF
  VCA

Connections:

  VCO --(+)-- VCF -- VCA -> out
  VCO -- |
  VCO -- |
  noise -'

There is a modifier block controlling each module.

      VCO modifiers
  switch: sin/pulse/saw
  hardwired: MIDI note number, MIDI pitch bend
  pulse width (pulse wave)
  ADSR envelope (exponential)
  LFO, max gain */- 600 cents
  gain
  microtuning controls?

Noise modifiers
  switch: pink/white
  gain  (0 .. 1)

VCF modifiers
  hardwired: none?
  ADSR envelope (exponential)
  LFO
  gain (-1 .. +1)

VCA modifiers
  hardwired: note on, note off, note velocity
  ADSR envelope (exponential)
  LFO
  gain (0 .. 1)

LFO controls
  switch: sine/saw/triangle/pulse (default sine)
  rate (0.1 Hz .. 20 Hz)
  depth (default 0)

So how does a VCO work?
  Each sample adds Fo/Fs to the phase (where 0 <= phase <= 1)
  From the phase, can calculate amplitude.
  saw: amplitude = phase * 2 - 1
  pulse: amplitude = phase < pulsewidth ? low : high
         (calc low and high so there is no DC offset.
         I think that means high = (1-pw), low = -pw.)
  sin: amplitude = sin(2 * pi * phase)
  Now, run the wave through a bandwidth limiter.
     a = 2 * Fs * (a - a[n-1])

How does an envelope generator work?
  It has five parameters: P, A, D, S, R.
     Peak level, Attack time, Decay time, Sustain level, Release time.
  Use Bresenham to generate straight lines, then convert the lines
  to exponential.

How does a VCF work?
  See D'Angelo amd Valimaki.
  (Sheesh!)

What's the minimum needed?
  VCO tied to MIDI note
    no envelope, no LFO, no pitch bend, just straight even-tempered pitches.
  VCA
    envelope generator fixed at A=0, D=0, S=1, R=0.  P = f(MIDI velocity).
  The null VCF is a passthrough.
  The null LFO is a zero.

Where to start?
  class MyNote : public SynthNote;
  have a processing graph?
  class VCO { Render(...);
  define scopes
    vco1 = 1025

----------------------------------
Open Source Software

  Aeolus - pipe organ emulator

  Ardour - Audio and MIDI recording and editing

  Audacity - recorder/editor

  Fluidsynth - wavetable synthesizer
    - QSynth is a front end

  HammerSound - free instrument samples

  horgand - organ synth

  JACK

  Jacker - sequences/tracker
    by paniq

  LADSPA - Linux Audio Developer's Simple Plugin API

  WildMIDI - wavetable synth
    part of GStreamer

Commercial Software

  DLS (Downloadable Sounds) - file format for sound banks

  SoundFont - file format for samples
    v1, v2, and v2.04
    from E-mu and Creative Labs

Keyboard Controllers

  Akai Synthstation

  M-Audio Axiom A.I.R.
    premium controllers

  M-Audio Oxygen
    budget controllers

  M-Audio KeyStation
    semi-weighted controllers

  M-Audio Axiom Pro
   older premium controllers

  M-Audio Axiom
    older semi-weighted controllers

  Novation SL-11 Mk2
    premium controllers

  Novation LaunchKey
    midrange controllers

  Novation Impulse
    budget controllers

Commercial Synths

  Access Virus TI2
  Nord Lead 2X, 3, 4
  StudioLogic Sledge

Projects

  Beyond Good and Evil by paniq
  http://music.paniq.cc/album/beyond-good-and-evil
  http://www.the-album.cc/pages/archive/index.html

Further Reading

  DPW bandlimited sawtooth algorithm
    Välimäki, V.
    "Discrete-time synthesis of the sawtooth waveform with reduced aliasing"
     IEEE Signal Processing Letters 12(3): 214– 217, 2005

  http://www.acoustics.hut.fi/publications/papers/dafx2004-moog/

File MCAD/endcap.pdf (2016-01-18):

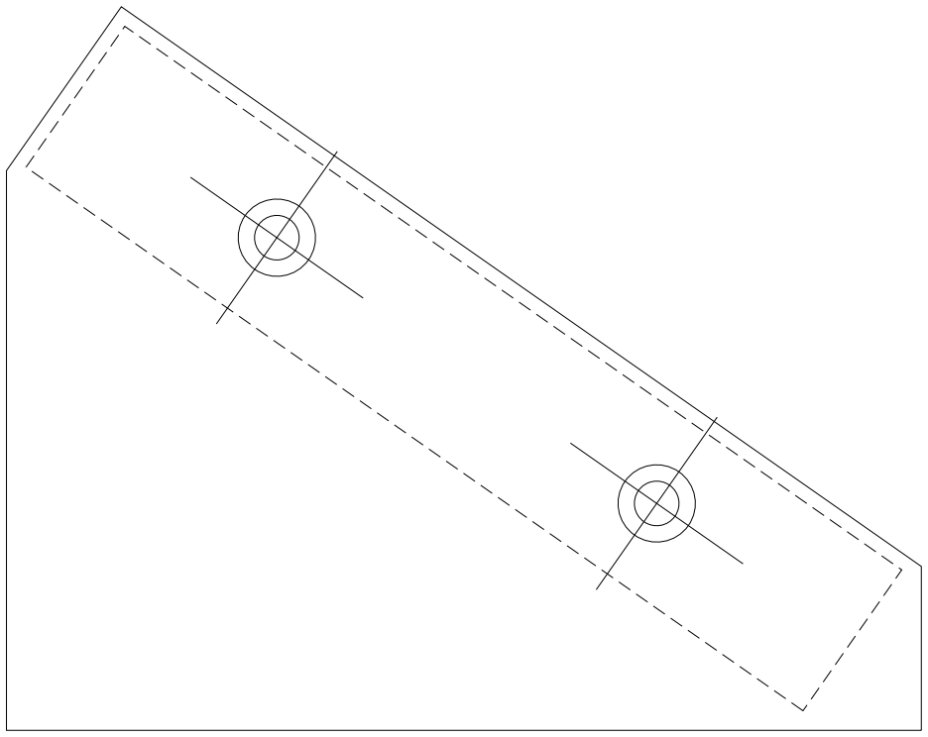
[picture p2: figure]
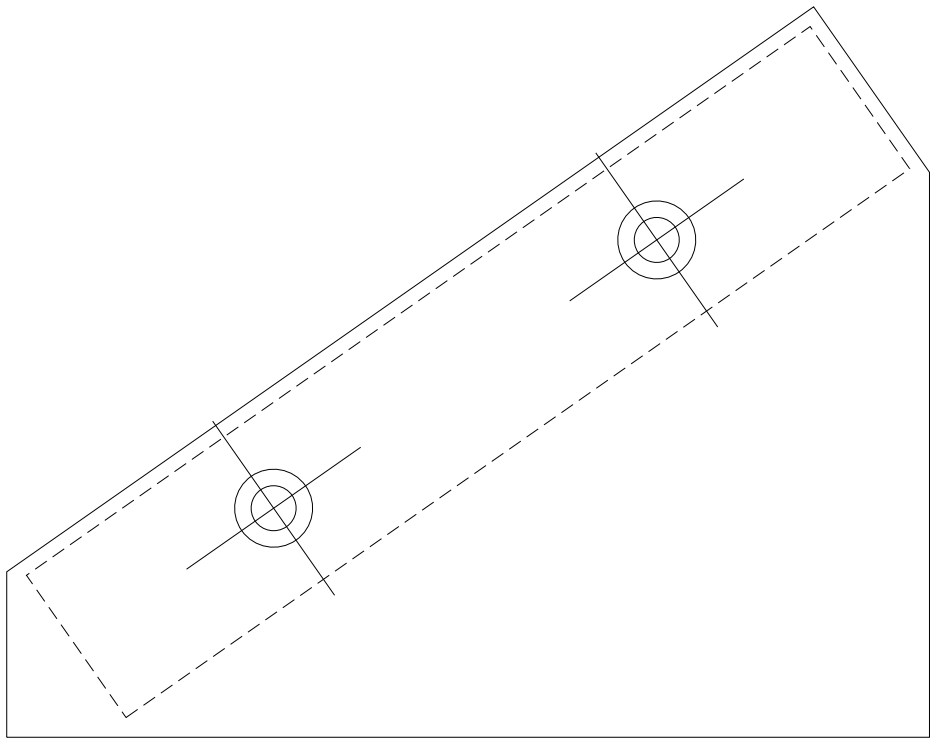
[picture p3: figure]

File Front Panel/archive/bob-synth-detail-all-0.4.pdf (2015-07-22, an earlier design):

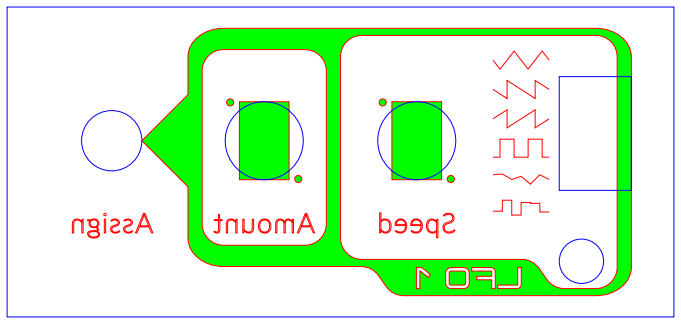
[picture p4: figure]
LFO 1; Assign Amount Speed

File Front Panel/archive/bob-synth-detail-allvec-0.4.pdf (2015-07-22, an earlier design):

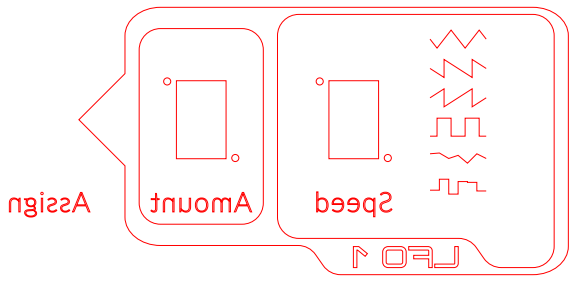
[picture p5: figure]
LFO 1; Assign Amount Speed

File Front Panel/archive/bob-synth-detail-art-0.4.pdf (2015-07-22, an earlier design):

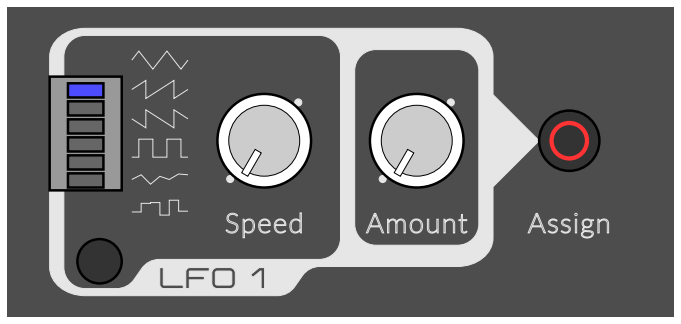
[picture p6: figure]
LFO 1; Speed; Amount; Assign

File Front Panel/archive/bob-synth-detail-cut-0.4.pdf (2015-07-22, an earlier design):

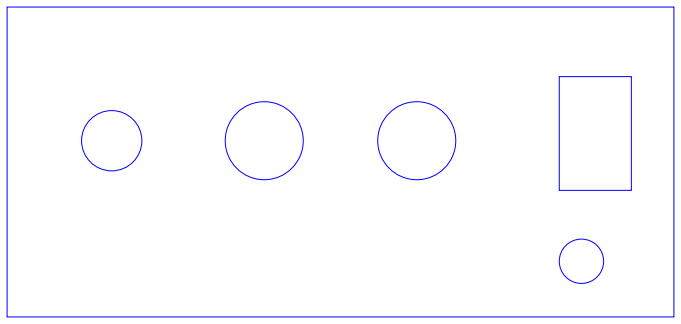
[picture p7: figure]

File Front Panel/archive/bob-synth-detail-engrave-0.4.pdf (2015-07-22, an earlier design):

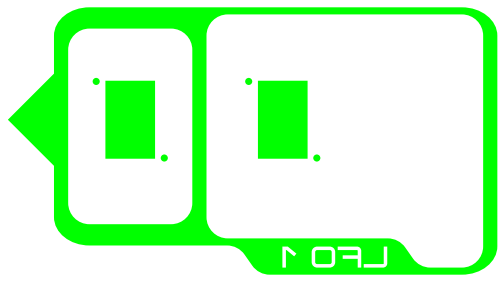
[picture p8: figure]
LFO 1; Assign Amount Speed

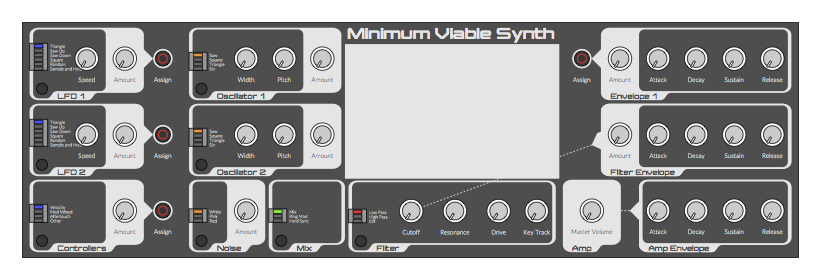
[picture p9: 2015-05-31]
image/Synth_Panel.png

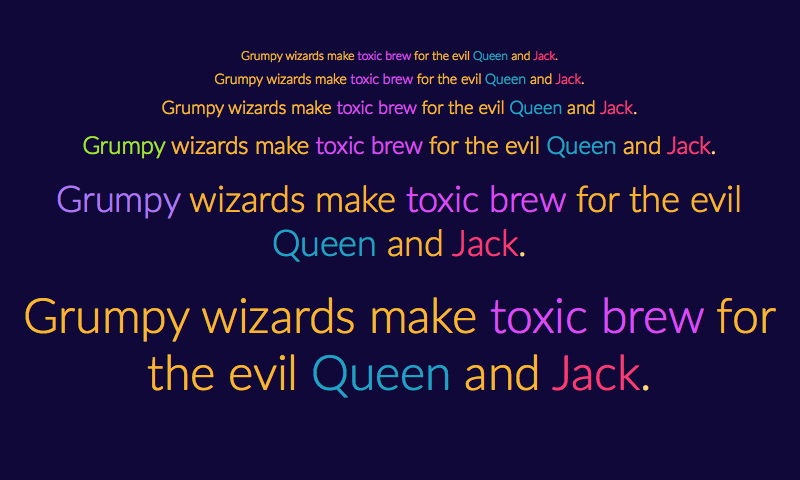
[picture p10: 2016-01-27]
Firmware/Master/Graphics/Color Text Sample.png

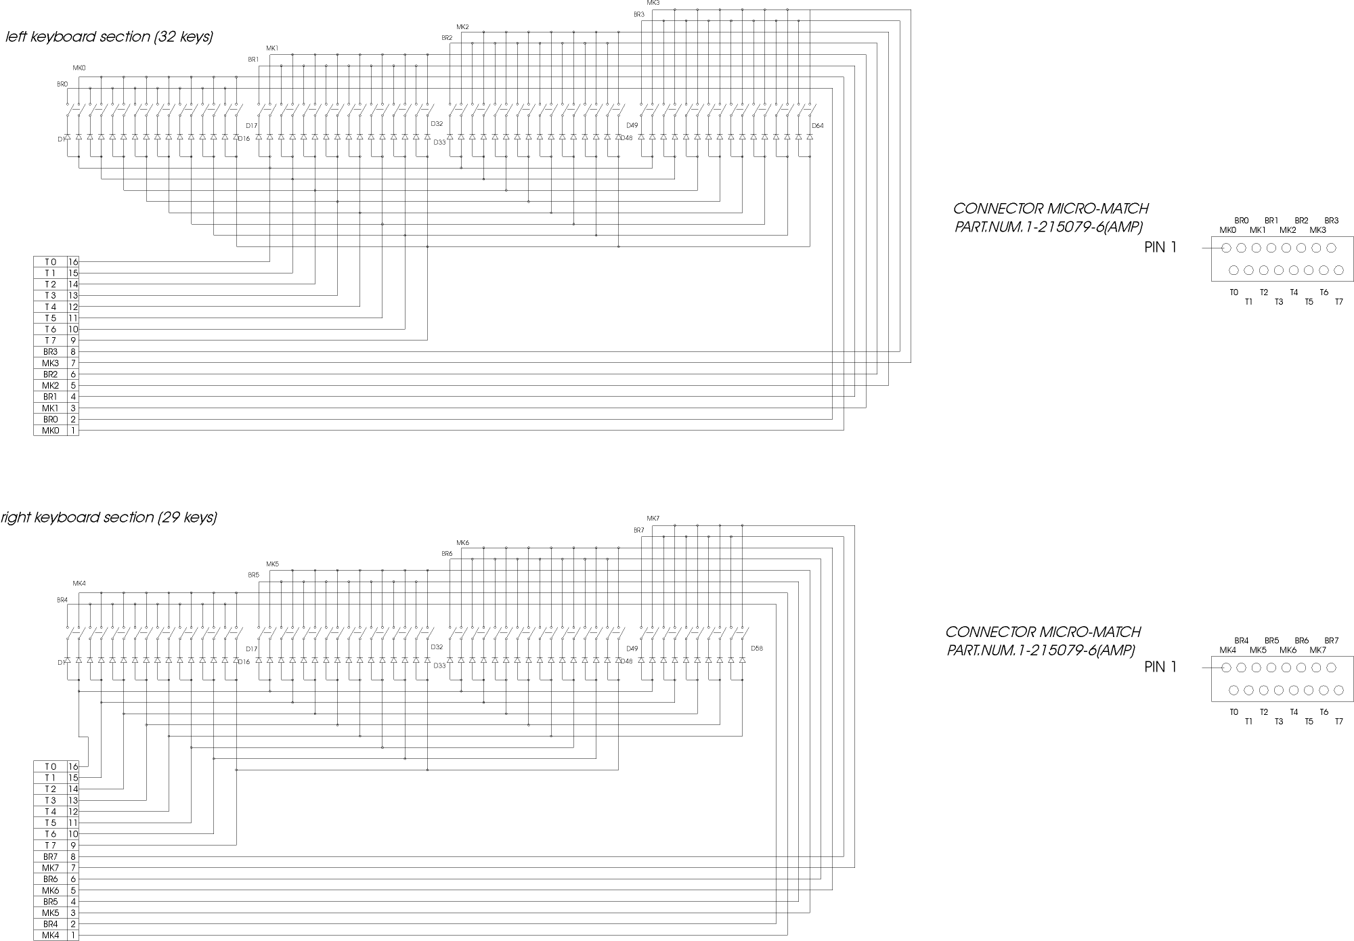
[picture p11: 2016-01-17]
datasheets/Matrix_61.gif

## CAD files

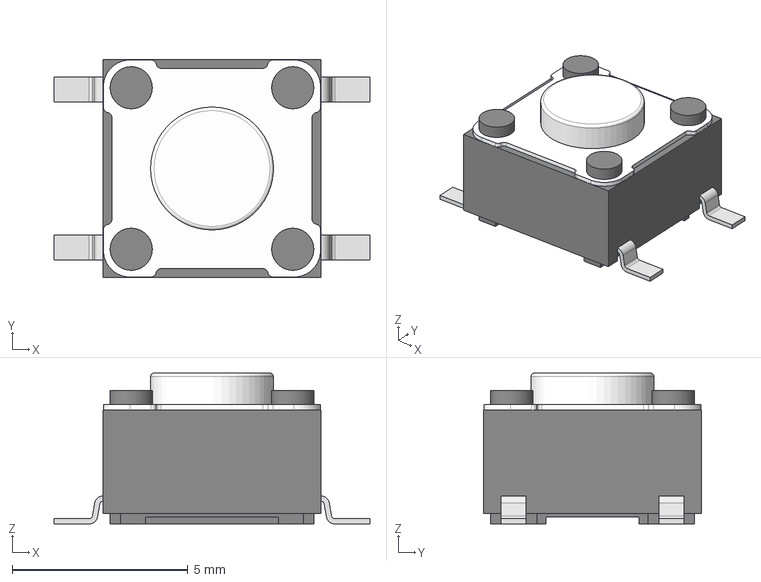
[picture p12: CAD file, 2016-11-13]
ECAD/io_daughterboard/datasheets/Tactile Buttons/STEP-430182043816-rev1.stp
9.00 x 6.20 x 4.30 mm

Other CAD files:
ECAD/io_daughterboard/datasheets/Tactile Buttons/IGS-430182043816-rev1.igs
MCAD/assembly.scad
MCAD/endplug.scad
MCAD/Filter substrate thick.scad
MCAD/Filter substrate.scad
MCAD/LFO substrate thick.scad
MCAD/LFO substrate.scad
MCAD/Noise substrate thick.scad
MCAD/Noise substrate.scad
MCAD/Osc substrate thick.scad
MCAD/Osc substrate.scad

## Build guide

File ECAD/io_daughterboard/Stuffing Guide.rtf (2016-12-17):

J1 FPC-40
J2 FPC-6
L1 10uH
User button
System
U6 STMPE811
U3 U4 U5 74HC244
U7 U8 U9
U2 SPX3819
U1 FAN533
U10 U11 74LV1T34
D1 -|<- MBR0540
D2 -|<- 24V Zener

C10 C11 1µF 0805
C13 10nF
C14 1µF
C15 C16 1nF
C1 C2 C3 C4 C5 100nF
C6 C7 C8 C9 C12

R13 4.3
R14 R28 1M
R15 R16 R19 R22 4.7K
R25 R31 100
R32 R33 R34 R35 100K
R1 R2 R3 R4 R5 10K
R6 R7 R8 R9 R10
R11 R17 R18 R20 R21
R23 R24 R26 R27 R29
R30

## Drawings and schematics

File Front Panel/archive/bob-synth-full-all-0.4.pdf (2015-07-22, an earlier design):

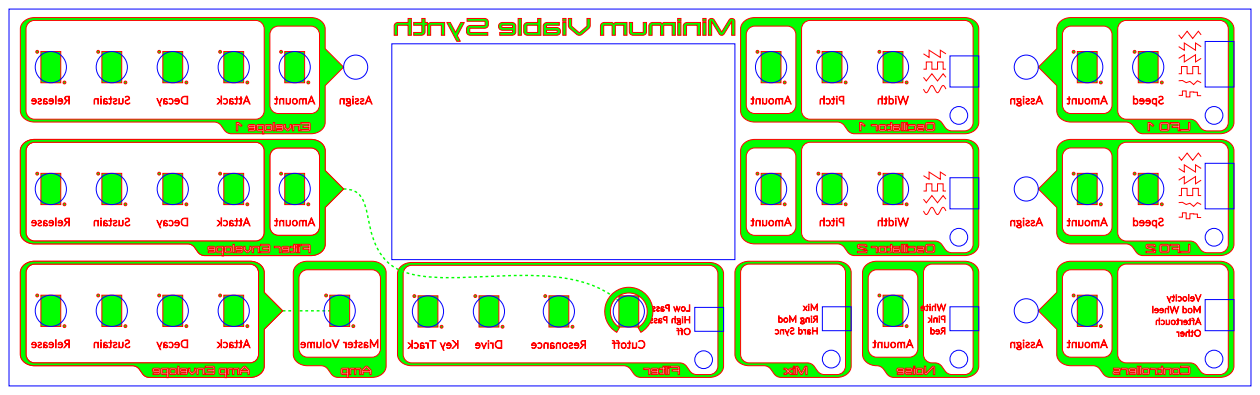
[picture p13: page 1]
Filter; Filter Envelope; Amp Envelope; LFO 1; LFO 2; Controllers; Velocity Mod Wheel Aftertouch Other; Assign Amount; Oscillator 1; Oscillator 2; Noise; White Pink Red; Amount; Mix; Mix Ring Mod Hard Sync; Low Pass High Pass Off; Envelope 1; Amp

Minimum Viable Synth

Release Sustain Decay Attack Amount Assign

Amount Pitch Width

Assign Amount Speed

Release Sustain Decay Attack Amount

Release Sustain Decay Attack Master Volume

Key Track Drive Resonance Cutoff

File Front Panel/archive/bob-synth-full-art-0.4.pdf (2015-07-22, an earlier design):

# Minimum Viable Synth

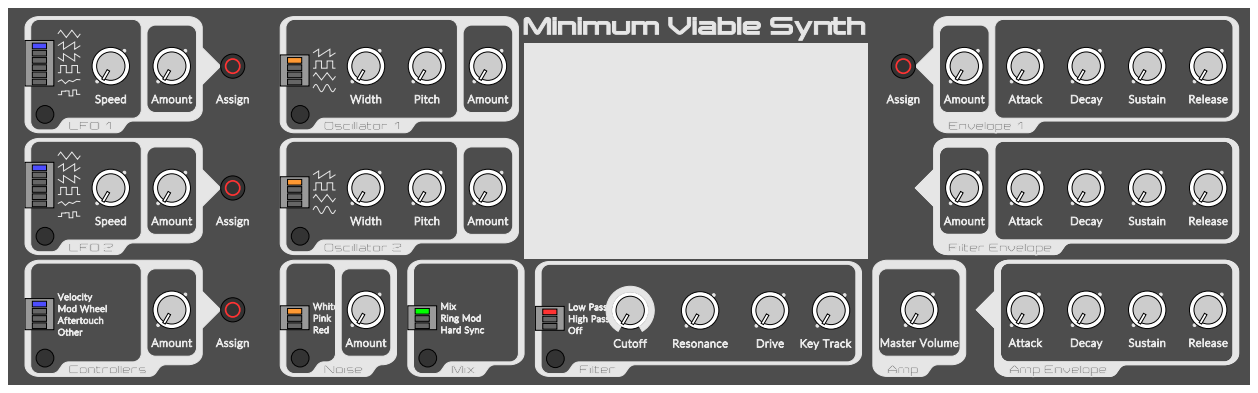
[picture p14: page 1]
Filter; Filter Envelope; Amp Envelope; LFO 1; Speed; Amount; Assign; LFO 2; Controllers; Velocity Mod Wheel Aftertouch Other; Oscillator 1; Width; Pitch; Oscillator 2; Noise; White Pink Red; Mix; Mix Ring Mod Hard Sync; Low Pass High Pass Off; Cutoff; Resonance; Drive; Key Track; Envelope 1; Attack; Decay; Sustain; Release; Amp; Master Volume

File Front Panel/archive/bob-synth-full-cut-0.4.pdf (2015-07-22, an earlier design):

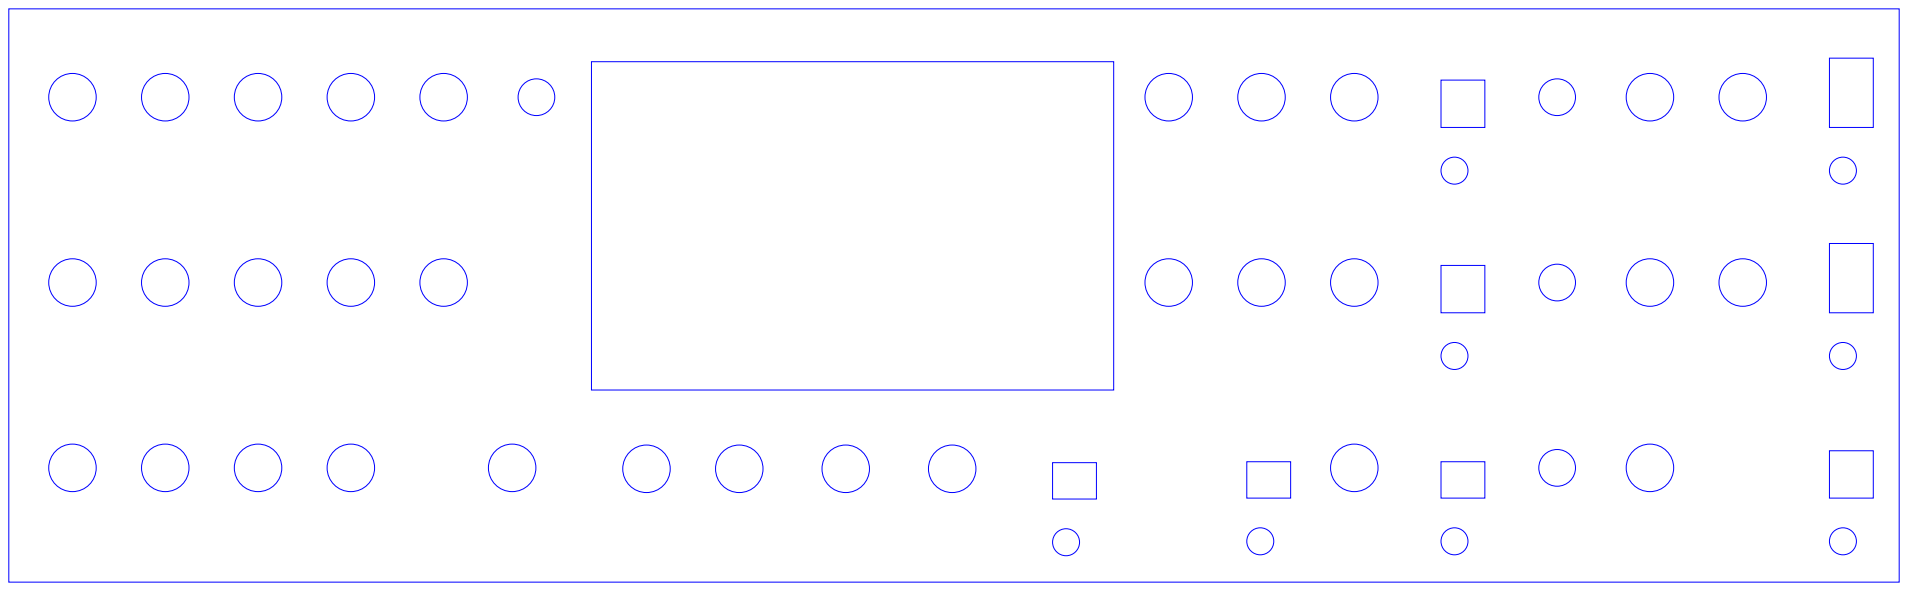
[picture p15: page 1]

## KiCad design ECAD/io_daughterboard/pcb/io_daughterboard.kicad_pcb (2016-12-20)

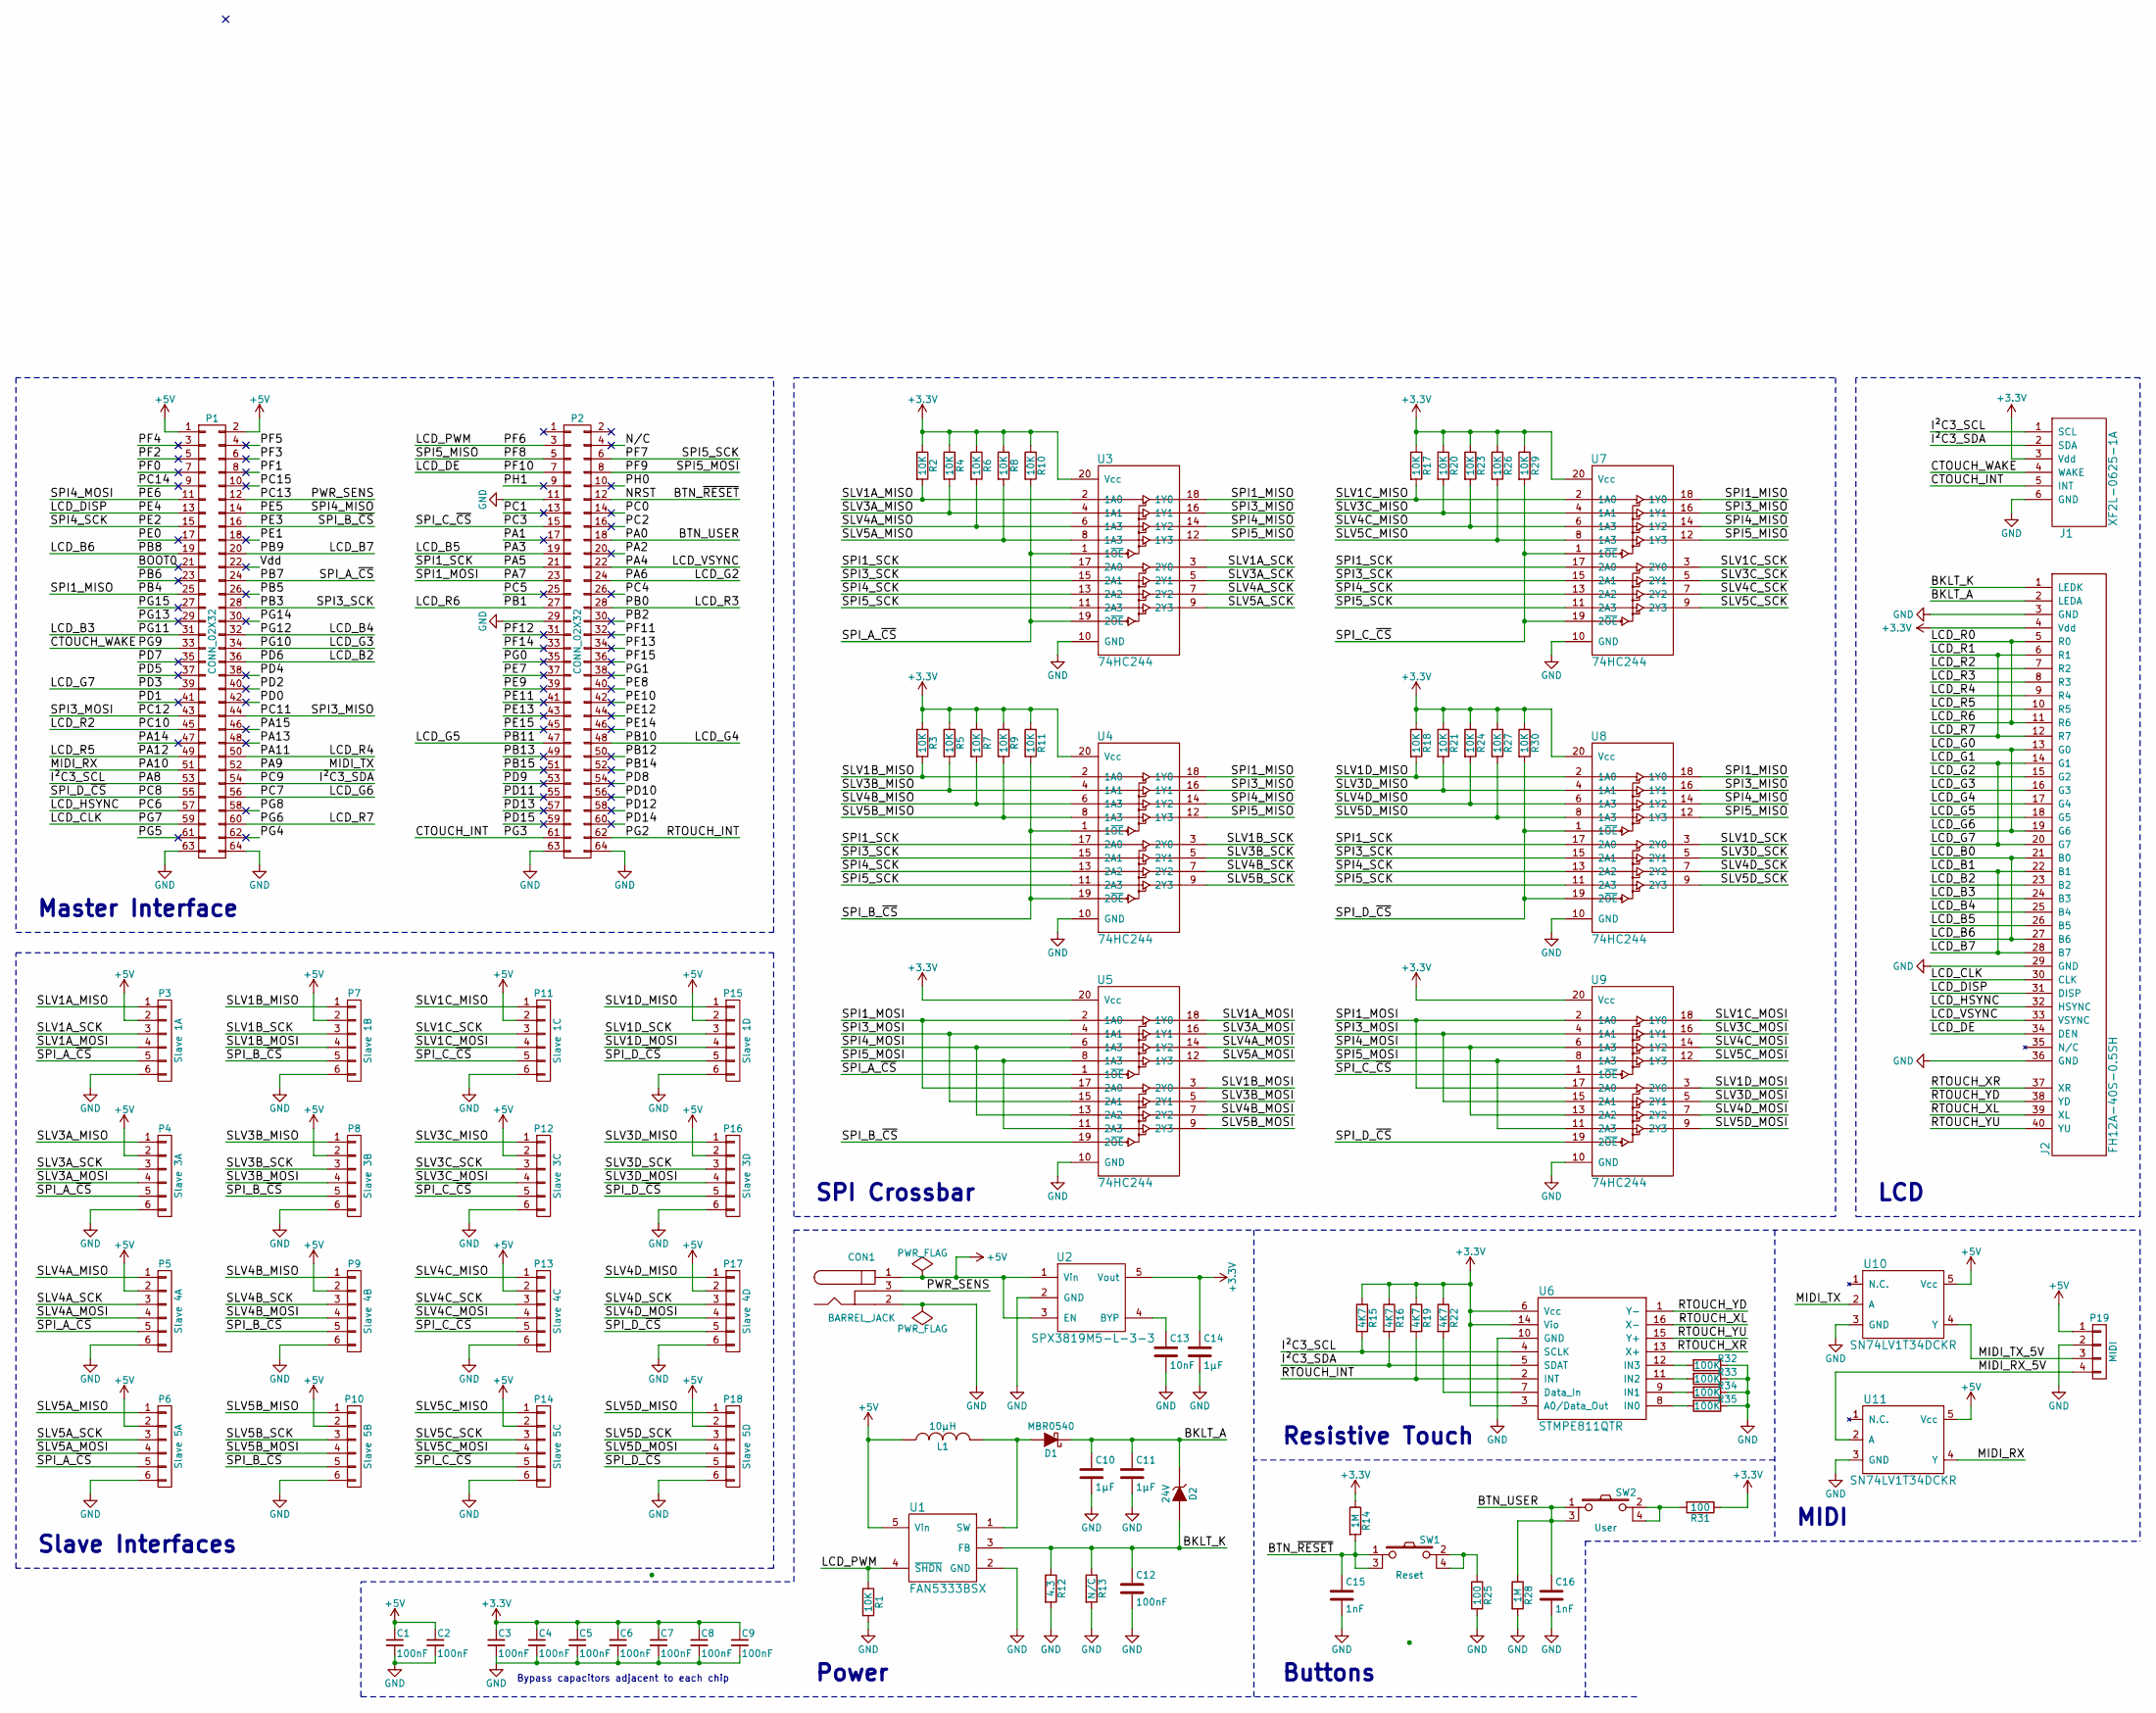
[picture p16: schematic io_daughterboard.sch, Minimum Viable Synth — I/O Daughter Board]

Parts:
C1, C2, C3, C4, C5, C6, C7, C8, C9, C12: 100nF; C_0603
C10, C11: 1µF; C_0805
C13: 10nF; C_0603
C14: 1µF; C_0603
C15, C16: 1nF; C_0603
CON1: BARREL_JACK
D1: MBR0540; SOD-123
D2: 24V; SOD-323
J1: XF2L-0625-1A; XF2L-0625
J2: FH12A-40S-0.5SH; FH12A-40S
L1: 10µH; Inductor_Taiyo-Yuden_NR-60xx
P1, P2: CONN_02X32; Socket_Strip_Reversed_2x32
P3: Slave 1A; Molex_PicoBlade_53047-0610_06x1.25mm_Straight
P4: Slave 3A; Molex_PicoBlade_53047-0610_06x1.25mm_Straight
P5: Slave 4A; Molex_PicoBlade_53047-0610_06x1.25mm_Straight
P6: Slave 5A; Molex_PicoBlade_53047-0610_06x1.25mm_Straight
P7: Slave 1B; Molex_PicoBlade_53047-0610_06x1.25mm_Straight
P8: Slave 3B; Molex_PicoBlade_53047-0610_06x1.25mm_Straight
P9: Slave 4B; Molex_PicoBlade_53047-0610_06x1.25mm_Straight
P10: Slave 5B; Molex_PicoBlade_53047-0610_06x1.25mm_Straight
P11: Slave 1C; Molex_PicoBlade_53047-0610_06x1.25mm_Straight
P12: Slave 3C; Molex_PicoBlade_53047-0610_06x1.25mm_Straight
P13: Slave 4C; Molex_PicoBlade_53047-0610_06x1.25mm_Straight
P14: Slave 5C; Molex_PicoBlade_53047-0610_06x1.25mm_Straight
P15: Slave 1D; Molex_PicoBlade_53047-0610_06x1.25mm_Straight
P16: Slave 3D; Molex_PicoBlade_53047-0610_06x1.25mm_Straight
P17: Slave 4D; Molex_PicoBlade_53047-0610_06x1.25mm_Straight
P18: Slave 5D; Molex_PicoBlade_53047-0610_06x1.25mm_Straight
P19: MIDI; Molex_PicoBlade_53047-0410_04x1.25mm_Straight
R1, R2, R3, R4, R5, R6, R7, R8, R9, R10, R11, R17, R18, R20, R21, R23, R24, R26, R27, R29, R30: 10K; R_0603
R12: 4.3; R_0603_HandSoldering
R13: N/C; R_0603_HandSoldering_no_paste
R14, R28: 1M; R_0603
R15, R16, R19, R22: 4K7; R_0603
R25, R31: 100; R_0603
R32, R33, R34, R35: 100K; R_0603
SW1: Reset; WS-TASV
SW2: User; WS-TASV
U1: FAN5333BSX; SOT-23-5
U2: SPX3819M5-L-3-3; SOT-23-5
U3, U4, U5, U7, U8, U9: 74HC244; TSSOP-20_4.4x6.5mm_Pitch0.65mm
U6: STMPE811QTR; QFN-16-1EP_3x3mm_Pitch0.5mm
U10, U11: SN74LV1T34DCKR; SOT-23-5

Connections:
+3V3: C3.1, C4.1, C5.1, C6.1, C7.1, C8.1, C9.1, C14.1, J1.3 (Vdd), J2.4 (Vdd), R2.1, R3.1, R4.1, R5.1, R6.1, R7.1, R8.1, R9.1, R10.1, R11.1, R14.1, R15.1, R16.1, R17.1, R18.1, R19.1, R20.1, R21.1, R22.1, R23.1, R24.1, R26.1, R27.1, R29.1, R30.1, R31.1, U2.5 (Vout), U3.20 (Vcc), U4.20 (Vcc), U5.20 (Vcc), U6.3 (A0/Data_Out), U6.6 (Vcc), U6.14 (Vio), U7.20 (Vcc), U8.20 (Vcc), U9.20 (Vcc)
+5V: C1.1, C2.1, CON1.1, L1.1, P1.1, P1.2, P3.2, P4.2, P5.2, P6.2, P7.2, P8.2, P9.2, P10.2, P11.2, P12.2, P13.2, P14.2, P15.2, P16.2, P17.2, P18.2, P19.1, U1.5 (Vin), U2.1 (Vin), U2.3 (EN), U10.5 (Vcc), U11.5 (Vcc)
/BKLT_A: C10.1, C11.1, D1.1 (K), D2.1 (K), J2.2 (LEDA)
/BKLT_K: C12.1, D2.2 (A), J2.1 (LEDK), R12.1, R13.1, U1.3 (FB)
/BOOT0: P1.21
/BTN_USER: C16.1, P2.18, R28.1, SW2.1, SW2.3
/BTN_~RESET: C15.1, P2.12, R14.2, SW1.1, SW1.3
/CTOUCH_INT: J1.5 (INT), P2.61
/CTOUCH_WAKE: J1.4 (WAKE), P1.33
/I²C3_SCL: J1.1 (SCL), P1.53, R15.2, U6.4 (SCLK)
/I²C3_SDA: J1.2 (SDA), P1.54, R16.2, U6.5 (SDAT)
/LCD_B0: J2.21 (B0), J2.27 (B6), P1.19
/LCD_B1: J2.22 (B1), J2.28 (B7), P1.20
/LCD_B2: J2.23 (B2), P1.36
/LCD_B3: J2.24 (B3), P1.31
/LCD_B4: J2.25 (B4), P1.32
/LCD_B5: J2.26 (B5), P2.19
/LCD_CLK: J2.30 (CLK), P1.59
/LCD_DE: J2.34 (DEN), P2.7
/LCD_DISP: J2.31 (DISP), P1.13
/LCD_G0: J2.13 (G0), J2.19 (G6), P1.56
/LCD_G1: J2.14 (G1), J2.20 (G7), P1.39
/LCD_G2: J2.15 (G2), P2.24
/LCD_G3: J2.16 (G3), P1.34
/LCD_G4: J2.17 (G4), P2.48
/LCD_G5: J2.18 (G5), P2.47
/LCD_HSYNC: J2.32 (HSYNC), P1.57
/LCD_PWM: P2.3, R1.1, U1.4 (~SHDN)
/LCD_R0: J2.5 (R0), J2.11 (R6), P2.27
/LCD_R1: J2.6 (R1), J2.12 (R7), P1.60
/LCD_R2: J2.7 (R2), P1.45
/LCD_R3: J2.8 (R3), P2.28
/LCD_R4: J2.9 (R4), P1.50
/LCD_R5: J2.10 (R5), P1.49
/LCD_VSYNC: J2.33 (VSYNC), P2.22
/MIDI_RX: P1.51, U11.4 (Y)
/MIDI_RX_5V: P19.4, U11.2 (A)
/MIDI_TX: P1.52, U10.2 (A)
/MIDI_TX_5V: P19.3, U10.4 (Y)
/N/C: P2.4
/PA1: P2.17
/PA2: P2.20
/PA5: P2.21, U3.17 (2A0), U4.17 (2A0), U7.17 (2A0), U8.17 (2A0)
/PA7: P2.23, U5.2 (1A0), U5.17 (2A0), U9.2 (1A0), U9.17 (2A0)
/PA13: P1.48
/PA14: P1.47
/PA15: P1.46
/PB2: P2.30
/PB3: P1.28, U3.15 (2A1), U4.15 (2A1), U7.15 (2A1), U8.15 (2A1)
/PB4: P1.25, U3.18 (1Y0), U4.18 (1Y0), U7.18 (1Y0), U8.18 (1Y0)
/PB5: P1.26
/PB6: P1.23
/PB7: P1.24, P3.5, P4.5, P5.5, P6.5, R10.2, U3.1 (1~OE), U3.19 (2~OE), U5.1 (1~OE)
/PB12: P2.50
/PB13: P2.49
/PB14: P2.52
/PB15: P2.51
/PC0: P2.14
/PC1: P2.13
/PC2: P2.16
/PC3: P2.15, P11.5, P12.5, P13.5, P14.5, R29.2, U7.1 (1~OE), U7.19 (2~OE), U9.1 (1~OE)
/PC4: P2.26
/PC5: P2.25
/PC8: P1.55, P15.5, P16.5, P17.5, P18.5, R30.2, U8.1 (1~OE), U8.19 (2~OE), U9.19 (2~OE)
/PC11: P1.44, U3.16 (1Y1), U4.16 (1Y1), U7.16 (1Y1), U8.16 (1Y1)
/PC12: P1.43, U5.4 (1A1), U5.15 (2A1), U9.4 (1A1), U9.15 (2A1)
/PC13: CON1.3, P1.12
/PC14: P1.9
/PC15: P1.10
/PD0: P1.42
/PD1: P1.41
/PD2: P1.40
/PD4: P1.38
/PD5: P1.37
/PD7: P1.35
/PD8: P2.54
/PD9: P2.53
/PD10: P2.56
/PD11: P2.55
/PD12: P2.58
/PD13: P2.57
/PD14: P2.60
/PD15: P2.59
/PE0: P1.17
/PE1: P1.18
/PE2: P1.15, U3.13 (2A2), U4.13 (2A2), U7.13 (2A2), U8.13 (2A2)
/PE3: P1.16, P7.5, P8.5, P9.5, P10.5, R11.2, U4.1 (1~OE), U4.19 (2~OE), U5.19 (2~OE)
/PE5: P1.14, U3.14 (1Y2), U4.14 (1Y2), U7.14 (1Y2), U8.14 (1Y2)
/PE6: P1.11, U5.6 (1A3), U5.13 (2A2), U9.6 (1A3), U9.13 (2A2)
/PE7: P2.37
/PE8: P2.40
/PE9: P2.39
/PE10: P2.42
/PE11: P2.41
/PE12: P2.44
/PE13: P2.43
/PE14: P2.46
/PE15: P2.45
/PF0: P1.7
/PF1: P1.8
/PF2: P1.5
/PF3: P1.6
/PF4: P1.3
/PF5: P1.4
/PF7: P2.6, U3.11 (2A3), U4.11 (2A3), U7.11 (2A3), U8.11 (2A3)
/PF8: P2.5, U3.12 (1Y3), U4.12 (1Y3), U7.12 (1Y3), U8.12 (1Y3)
/PF9: P2.8, U5.8 (1A3), U5.11 (2A3), U9.8 (1A3), U9.11 (2A3)
/PF11: P2.32
/PF12: P2.31
/PF13: P2.34
/PF14: P2.33
/PF15: P2.36
/PG0: P2.35
/PG1: P2.38
/PG2: P2.62, R19.2, U6.2 (INT)
/PG4: P1.62
/PG5: P1.61
/PG8: P1.58
/PG13: P1.29
/PG14: P1.30
/PG15: P1.27
/PH0: P2.10
/PH1: P2.9
/RTOUCH_XL: J2.39 (XL), U6.16 (X-)
/RTOUCH_XR: J2.37 (XR), U6.13 (X+)
/RTOUCH_YD: J2.38 (YD), U6.1 (Y-)
/RTOUCH_YU: J2.40 (YU), U6.15 (Y+)
/SLV1A_MISO: P3.1, R2.2, U3.2 (1A0)
/SLV1A_MOSI: P3.4, U5.18 (1Y0)
/SLV1A_SCK: P3.3, U3.3 (2Y0)
/SLV1B_MISO: P7.1, R3.2, U4.2 (1A0)
/SLV1B_MOSI: P7.4, U5.3 (2Y0)
/SLV1B_SCK: P7.3, U4.3 (2Y0)
/SLV1C_MISO: P11.1, R17.2, U7.2 (1A0)
/SLV1C_MOSI: P11.4, U9.18 (1Y0)
/SLV1C_SCK: P11.3, U7.3 (2Y0)
/SLV1D_MISO: P15.1, R18.2, U8.2 (1A0)
/SLV1D_MOSI: P15.4, U9.3 (2Y0)
/SLV1D_SCK: P15.3, U8.3 (2Y0)
/SLV3A_MISO: P4.1, R4.2, U3.4 (1A1)
/SLV3A_MOSI: P4.4, U5.16 (1Y1)
/SLV3A_SCK: P4.3, U3.5 (2Y1)
/SLV3B_MISO: P8.1, R5.2, U4.4 (1A1)
/SLV3B_MOSI: P8.4, U5.5 (2Y1)
/SLV3B_SCK: P8.3, U4.5 (2Y1)
/SLV3C_MISO: P12.1, R20.2, U7.4 (1A1)
/SLV3C_MOSI: P12.4, U9.16 (1Y1)
/SLV3C_SCK: P12.3, U7.5 (2Y1)
/SLV3D_MISO: P16.1, R21.2, U8.4 (1A1)
/SLV3D_MOSI: P16.4, U9.5 (2Y1)
/SLV3D_SCK: P16.3, U8.5 (2Y1)
/SLV4A_MISO: P5.1, R6.2, U3.6 (1A3)
/SLV4A_MOSI: P5.4, U5.14 (1Y2)
/SLV4A_SCK: P5.3, U3.7 (2Y2)
/SLV4B_MISO: P9.1, R7.2, U4.6 (1A3)
/SLV4B_MOSI: P9.4, U5.7 (2Y2)
/SLV4B_SCK: P9.3, U4.7 (2Y2)
/SLV4C_MISO: P13.1, R23.2, U7.6 (1A3)
/SLV4C_MOSI: P13.4, U9.14 (1Y2)
/SLV4C_SCK: P13.3, U7.7 (2Y2)
/SLV4D_MISO: P17.1, R24.2, U8.6 (1A3)
/SLV4D_MOSI: P17.4, U9.7 (2Y2)
/SLV4D_SCK: P17.3, U8.7 (2Y2)
/SLV5A_MISO: P6.1, R8.2, U3.8 (1A3)
/SLV5A_MOSI: P6.4, U5.12 (1Y3)
/SLV5A_SCK: P6.3, U3.9 (2Y3)
/SLV5B_MISO: P10.1, R9.2, U4.8 (1A3)
/SLV5B_MOSI: P10.4, U5.9 (2Y3)
/SLV5B_SCK: P10.3, U4.9 (2Y3)
/SLV5C_MISO: P14.1, R26.2, U7.8 (1A3)
/SLV5C_MOSI: P14.4, U9.12 (1Y3)
/SLV5C_SCK: P14.3, U7.9 (2Y3)
/SLV5D_MISO: P18.1, R27.2, U8.8 (1A3)
/SLV5D_MOSI: P18.4, U9.9 (2Y3)
/SLV5D_SCK: P18.3, U8.9 (2Y3)
/Vdd: P1.22
GND: C1.2, C2.2, C3.2, C4.2, C5.2, C6.2, C7.2, C8.2, C9.2, C10.2, C11.2, C12.2, C13.2, C14.2, C15.2, C16.2, CON1.2, J1.6 (GND), J2.3 (GND), J2.29 (GND), J2.36 (GND), P1.63, P1.64, P2.11, P2.29, P2.63, P2.64, P3.6, P4.6, P5.6, P6.6, P7.6, P8.6, P9.6, P10.6, P11.6, P12.6, P13.6, P14.6, P15.6, P16.6, P17.6, P18.6, P19.2, R1.2, R12.2, R13.2, R25.2, R28.2, R32.1, R33.1, R34.1, R35.1, U1.2 (GND), U2.2 (GND), U3.10 (GND), U4.10 (GND), U5.10 (GND), U6.10 (GND), U7.10 (GND), U8.10 (GND), U9.10 (GND), U10.3 (GND), U11.3 (GND)
unnamed: C13.1, U2.4 (BYP)
unnamed: D1.2 (A), L1.2, U1.1 (SW)
unnamed: R22.2, U6.7 (Data_In)
unnamed: R25.1, SW1.2, SW1.4
unnamed: R31.2, SW2.2, SW2.4
unnamed: R32.2, U6.12 (IN3)
unnamed: R33.2, U6.11 (IN2)
unnamed: R34.2, U6.9 (IN1)
unnamed: R35.2, U6.8 (IN0)

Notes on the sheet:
Master Interface
Power
SPI Crossbar
Resistive Touch
MIDI
Slave Interfaces
Buttons
LCD
Bypass capacitors adjacent to each chip

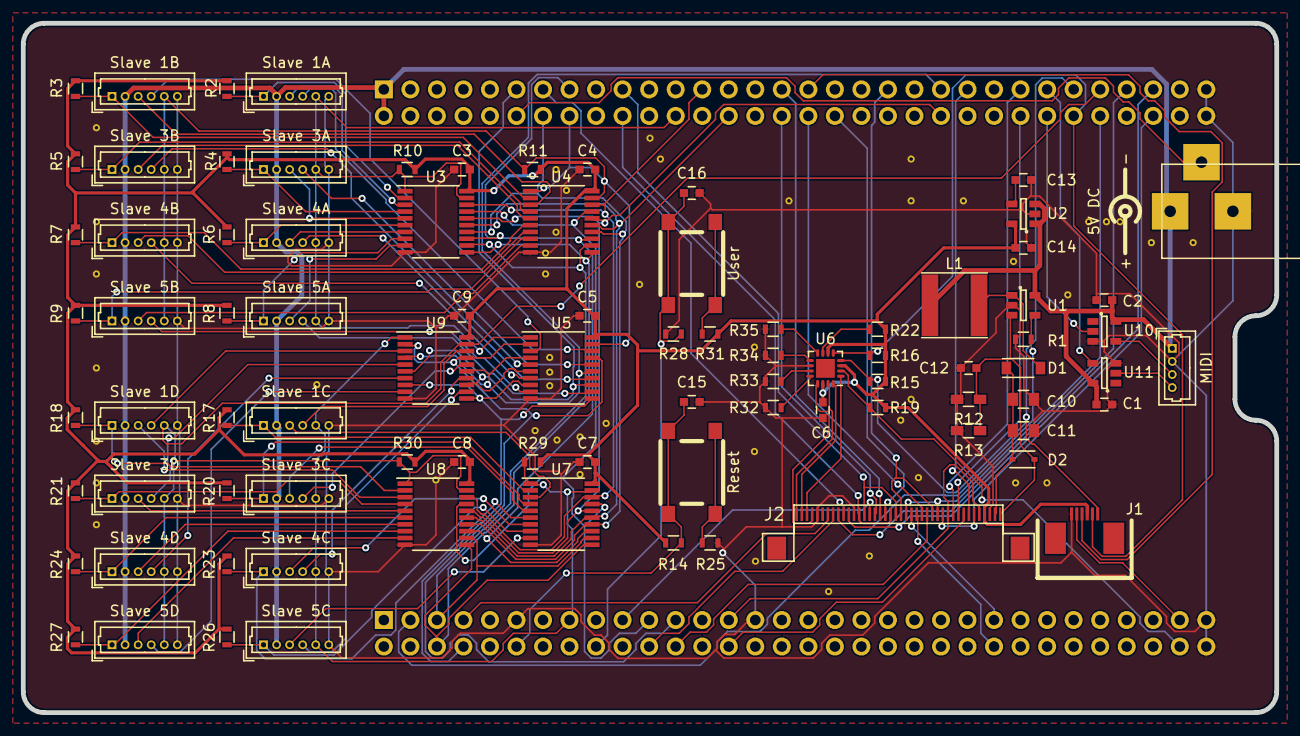
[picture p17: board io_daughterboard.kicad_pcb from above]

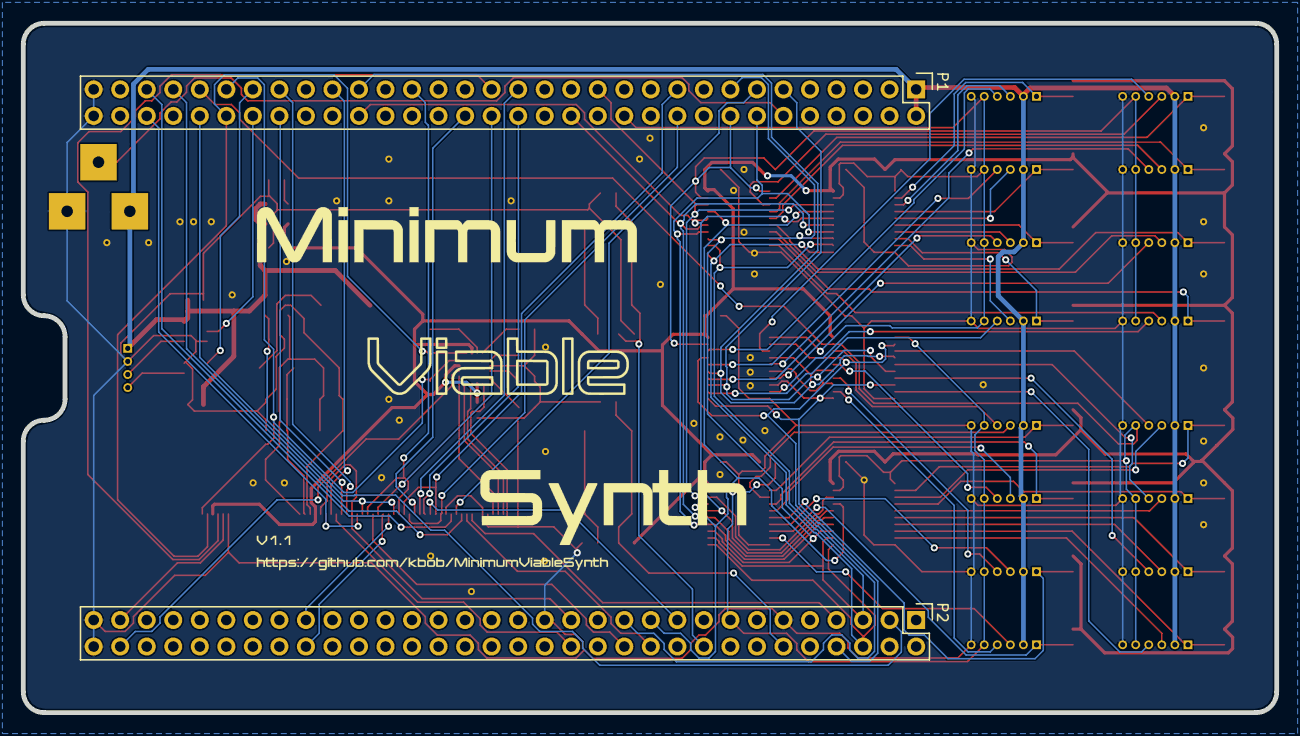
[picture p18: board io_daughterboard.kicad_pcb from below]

Board: 2 copper layers, 120.0 x 66.0 mm, 89 parts (2 on the bottom side), 118 nets.

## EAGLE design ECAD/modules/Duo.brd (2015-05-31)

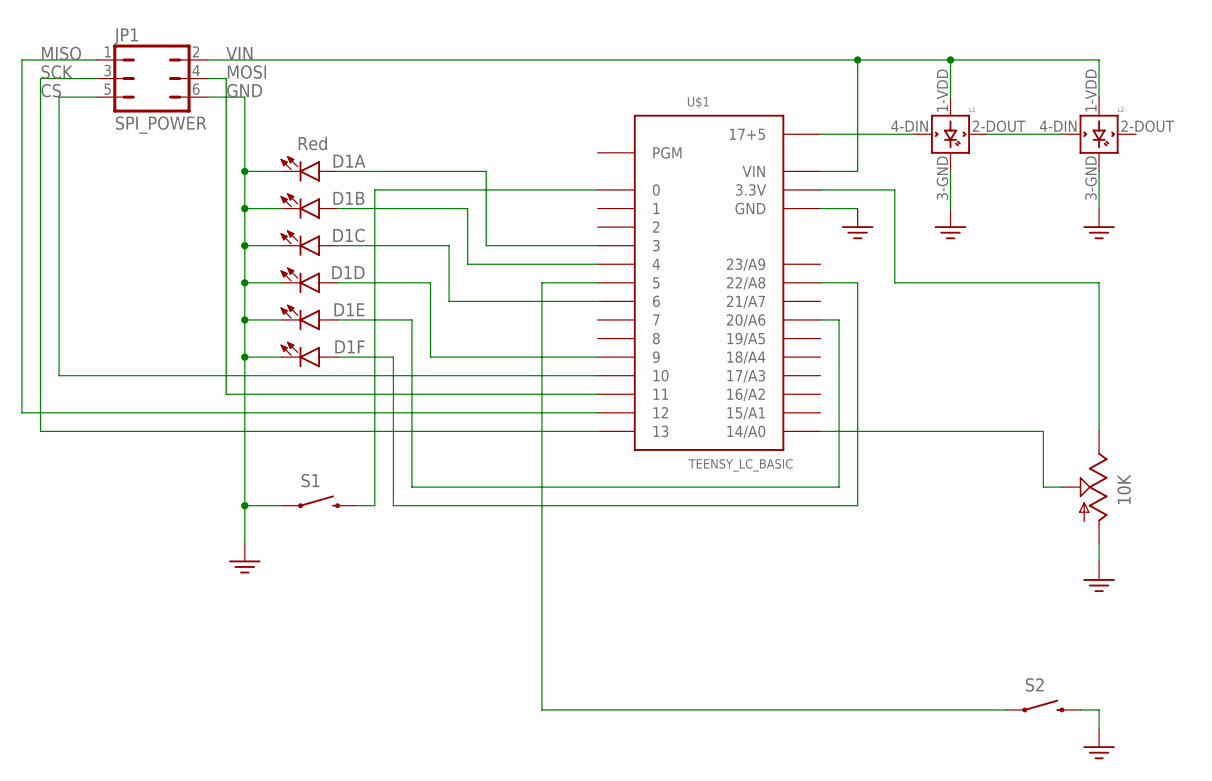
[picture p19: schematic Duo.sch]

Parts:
D1: Red; LED_BARGRAPH_6
JP1: SPI_POWER; JP3Q
L1, L2: WS2812B
S1: SWITCH-MOMENTARY-212MM; TACTILE-PTH-12MM
S2: SWITCH-MOMENTARY-2SMD; TACTILE-SWITCH-SMD
U$1: TEENSY_LC_BASIC
U$2: 10K; 14MMPOT

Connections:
3.3V: U$1.3.3V1 (3.3V), U$2.P$4 (E)
GND: D1.7 (C), D1.8 (C), D1.9 (C), D1.10 (C), D1.11 (C), D1.12 (C), JP1.6, L1.3-GND (GND), L2.3-GND (GND), S1.1, S2.3 (2), U$1.GND, U$1.GND1 (GND), U$1.GND2 (GND), U$2.P$5 (A)
unnamed: L1.4-DIN (DIN), U$1.17+5
unnamed: L1.2-DOUT (DOUT), L2.4-DIN (DIN)
unnamed: U$1.14/A0, U$2.P$3 (S)
unnamed: S2.1, U$1.5
unnamed: D1.1 (A), U$1.3
unnamed: D1.2 (A), U$1.4
unnamed: D1.3 (A), U$1.6
unnamed: D1.4 (A), U$1.9
unnamed: D1.5 (A), U$1.20/A6
unnamed: D1.6 (A), U$1.22/A8
unnamed: JP1.1, U$1.12
unnamed: S1.3 (2), U$1.0
unnamed: JP1.3, U$1.13
unnamed: JP1.5, U$1.10
unnamed: JP1.4, U$1.11
VIN: JP1.2, L1.1-VDD (VDD), L2.1-VDD (VDD), U$1.VIN

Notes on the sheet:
MISO
SCK
VIN
MOSI
GND

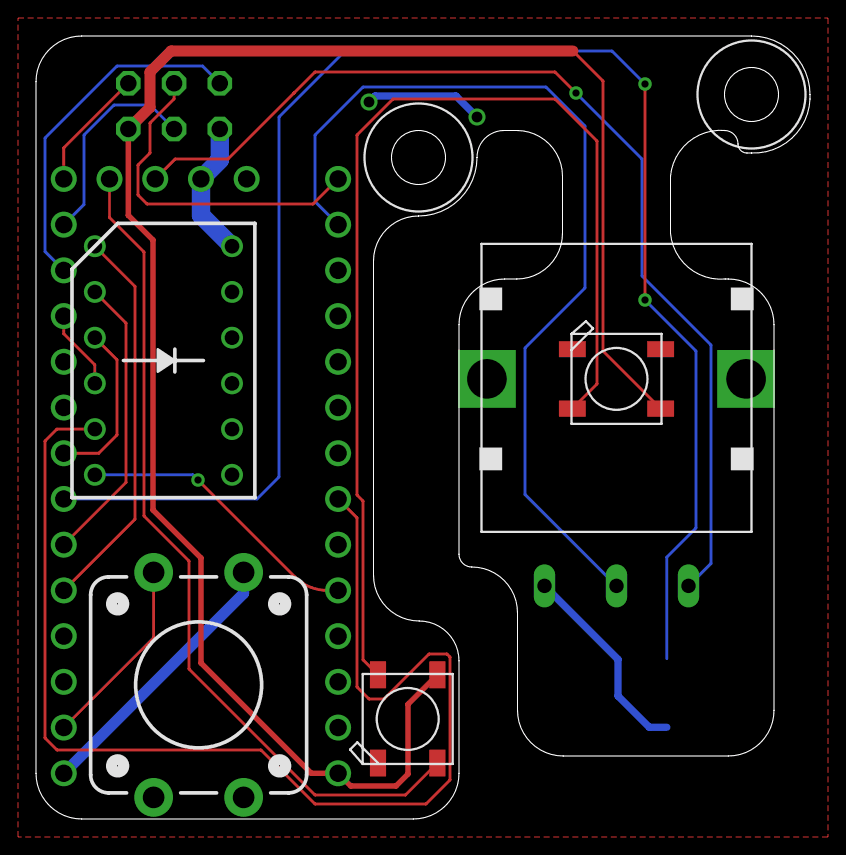
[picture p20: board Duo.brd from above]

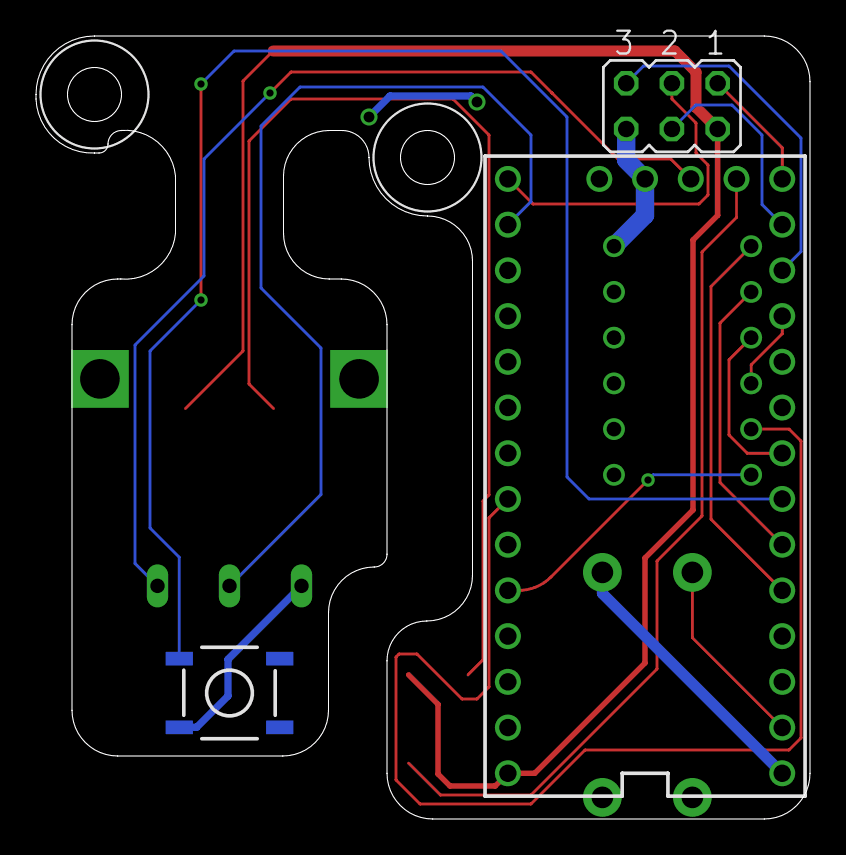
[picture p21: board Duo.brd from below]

Board: 2 copper layers, 43.0 x 43.5 mm, 10 parts (3 on the bottom side), 18 nets.

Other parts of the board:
U$6, U$10: STANDOFF-M3

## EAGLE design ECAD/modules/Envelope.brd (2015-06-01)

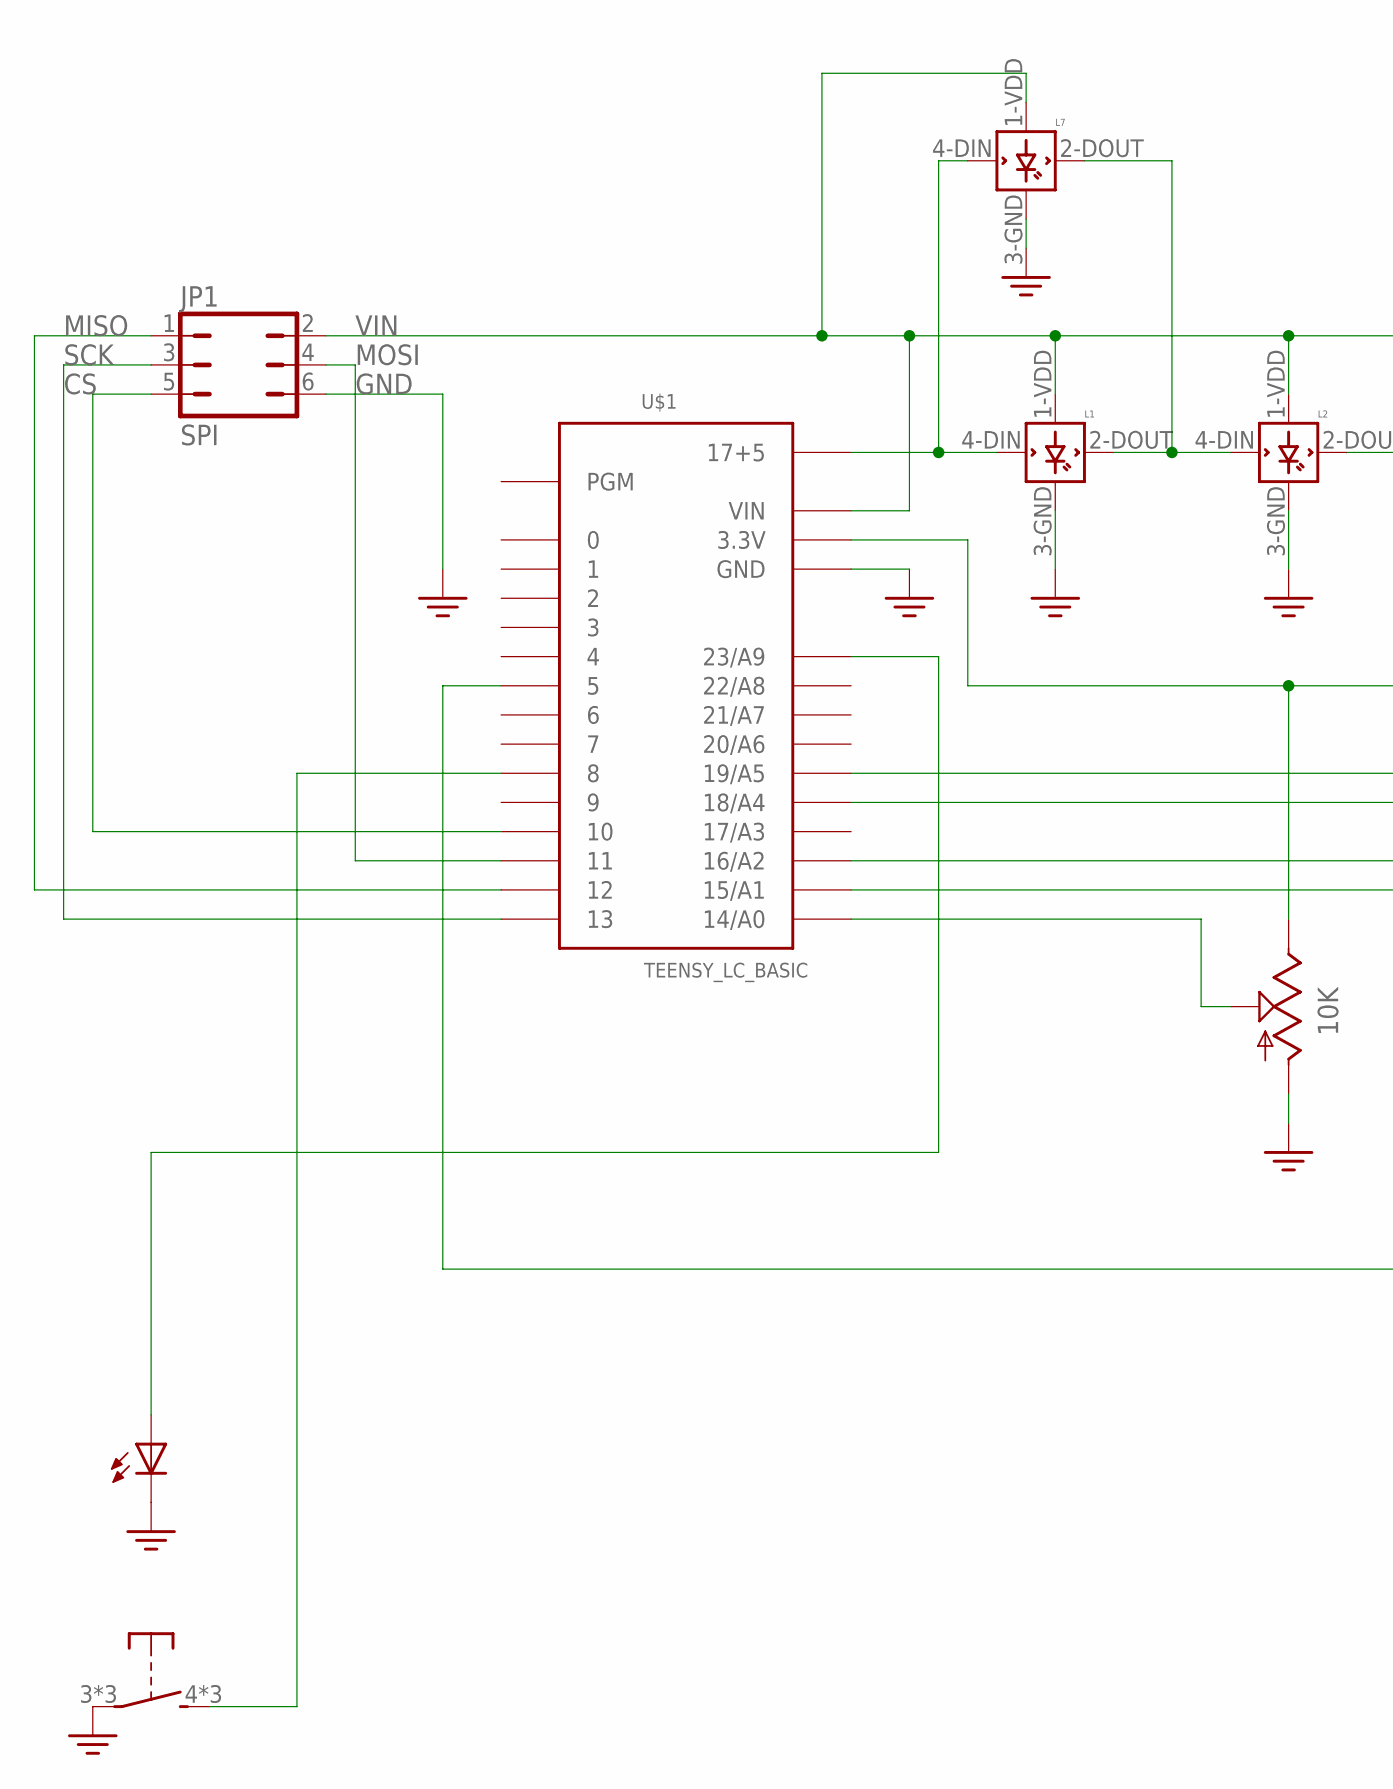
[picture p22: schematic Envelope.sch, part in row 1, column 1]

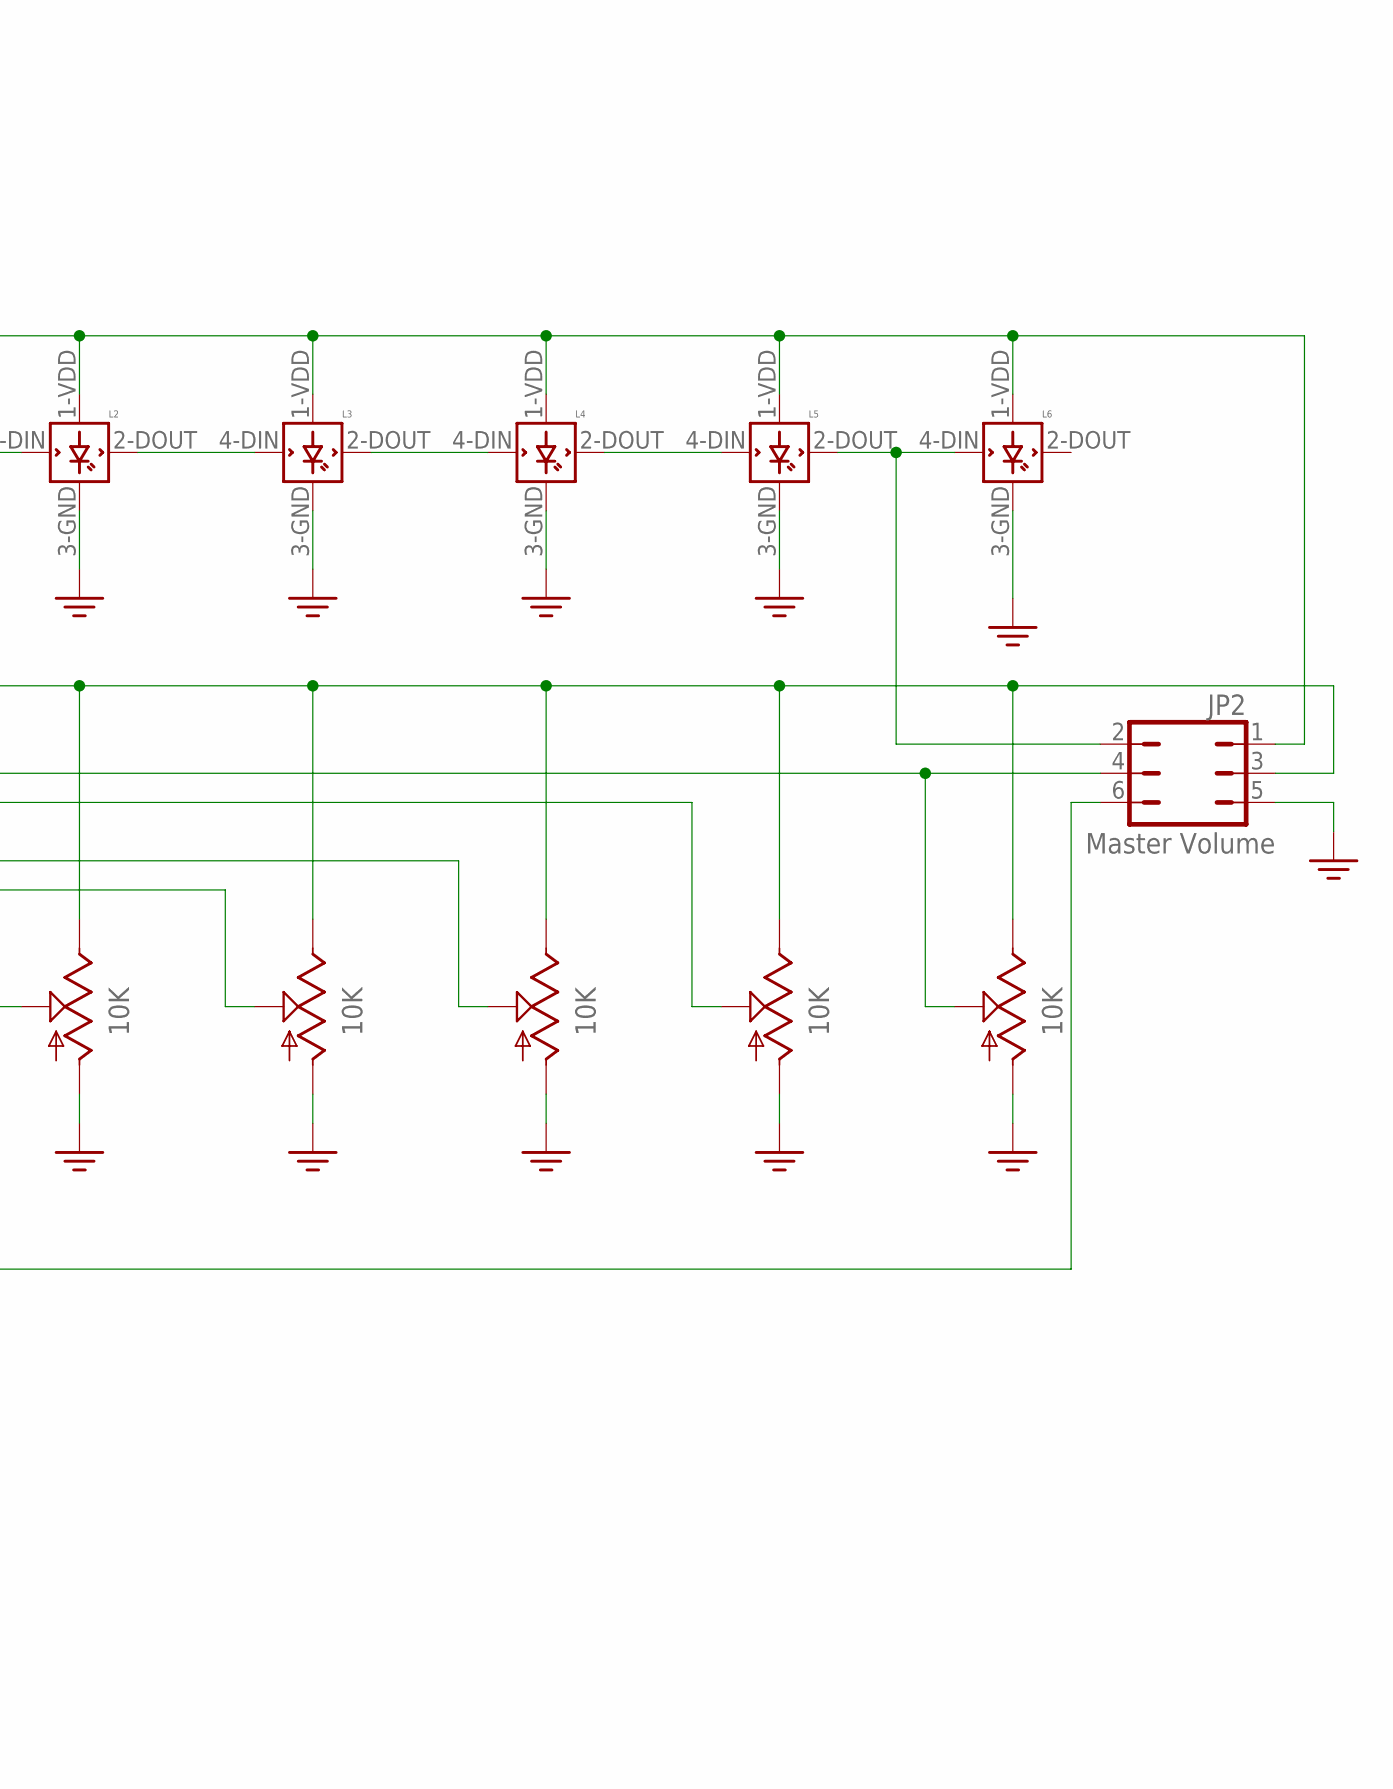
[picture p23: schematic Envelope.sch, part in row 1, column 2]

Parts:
JP1: SPI; JP3Q
JP2: Master Volume; JP3Q
L1, L2, L3, L4, L5, L6, L7: WS2812B
U$1: TEENSY_LC_BASIC
U$2, U$3, U$4, U$5, U$6: 10K; 14MMPOT
U$7: TL1220MEZZ; MEZZ

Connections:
3.3V: JP2.3, U$1.3.3V1 (3.3V), U$2.P$4 (E), U$3.P$4 (E), U$4.P$4 (E), U$5.P$4 (E), U$6.P$4 (E)
GND: JP1.6, JP2.5, L1.3-GND (GND), L2.3-GND (GND), L3.3-GND (GND), L4.3-GND (GND), L5.3-GND (GND), L6.3-GND (GND), L7.3-GND (GND), U$1.GND, U$1.GND1 (GND), U$1.GND2 (GND), U$2.P$5 (A), U$3.P$5 (A), U$4.P$5 (A), U$5.P$5 (A), U$6.P$5 (A), U$7.2 (C), U$7.3, U$7.P$1, U$7.P$2, U$7.P$6 (C)
unnamed: L1.4-DIN (DIN), L7.4-DIN (DIN), U$1.17+5
unnamed: L1.2-DOUT (DOUT), L2.4-DIN (DIN), L7.2-DOUT (DOUT)
unnamed: L2.2-DOUT (DOUT), L3.4-DIN (DIN)
unnamed: L3.2-DOUT (DOUT), L4.4-DIN (DIN)
unnamed: L4.2-DOUT (DOUT), L5.4-DIN (DIN)
unnamed: U$1.23/A9, U$7.1 (A), U$7.P$5 (A)
unnamed: U$1.14/A0, U$2.P$3 (S)
unnamed: U$1.15/A1, U$3.P$3 (S)
unnamed: U$1.16/A2, U$4.P$3 (S)
unnamed: U$1.18/A4, U$5.P$3 (S)
unnamed: U$1.8, U$7.4 (S), U$7.P$3 (S), U$7.P$4 (S)
unnamed: JP2.6, U$1.5
unnamed: JP1.1, U$1.12
unnamed: JP1.3, U$1.13
unnamed: JP1.5, U$1.10
unnamed: JP2.2, L5.2-DOUT (DOUT), L6.4-DIN (DIN)
unnamed: JP2.4, U$1.19/A5, U$6.P$3 (S)
unnamed: JP1.4, U$1.11
VIN: JP1.2, JP2.1, L1.1-VDD (VDD), L2.1-VDD (VDD), L3.1-VDD (VDD), L4.1-VDD (VDD), L5.1-VDD (VDD), L6.1-VDD (VDD), L7.1-VDD (VDD), U$1.VIN

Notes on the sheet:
MISO
SCK
VIN
MOSI
GND

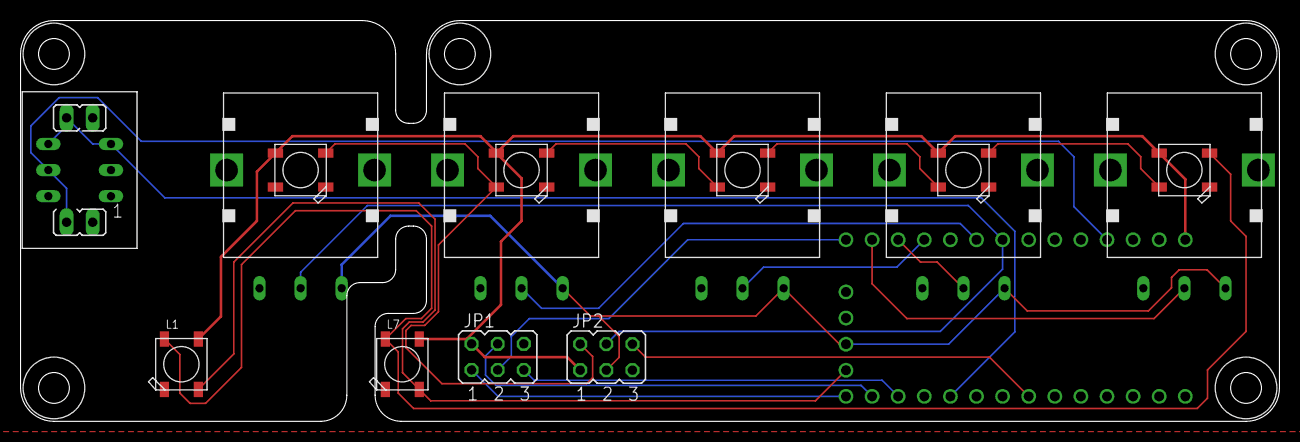
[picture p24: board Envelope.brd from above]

Board: 2 copper layers, 122.5 x 39.0 mm, 21 parts (1 on the bottom side), 21 nets.

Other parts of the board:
U$8, U$9, U$10, U$11, U$12: STANDOFF-M3

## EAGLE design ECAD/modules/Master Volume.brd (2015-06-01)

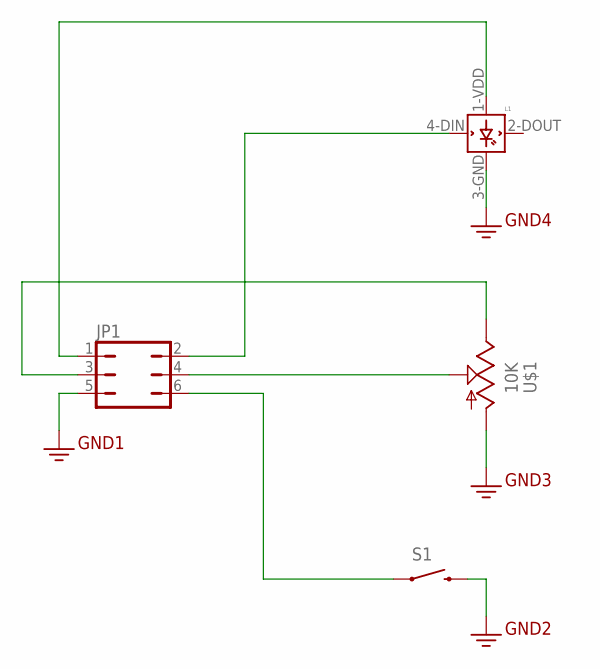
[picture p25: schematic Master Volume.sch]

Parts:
JP1: Master Volume; JP3Q
L1: WS2812B
S1: SWITCH-MOMENTARY-2SMD; TACTILE-SWITCH-SMD
U$1: 10K; 14MMPOT

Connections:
GND: JP1.5, L1.3-GND (GND), S1.3 (2), U$1.P$5 (A)
unnamed: JP1.1, L1.1-VDD (VDD)
unnamed: JP1.3, U$1.P$4 (E)
unnamed: JP1.2, L1.4-DIN (DIN)
unnamed: JP1.4, U$1.P$3 (S)
unnamed: JP1.6, S1.1

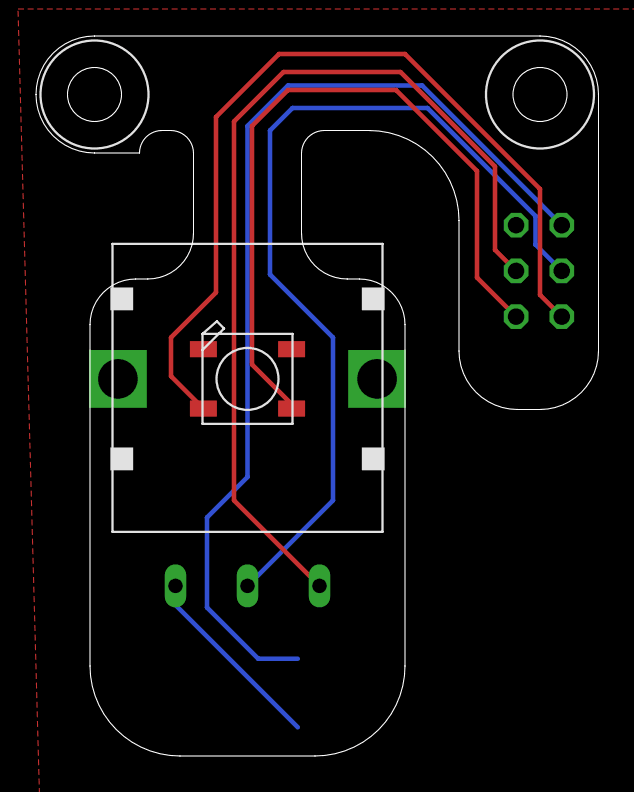
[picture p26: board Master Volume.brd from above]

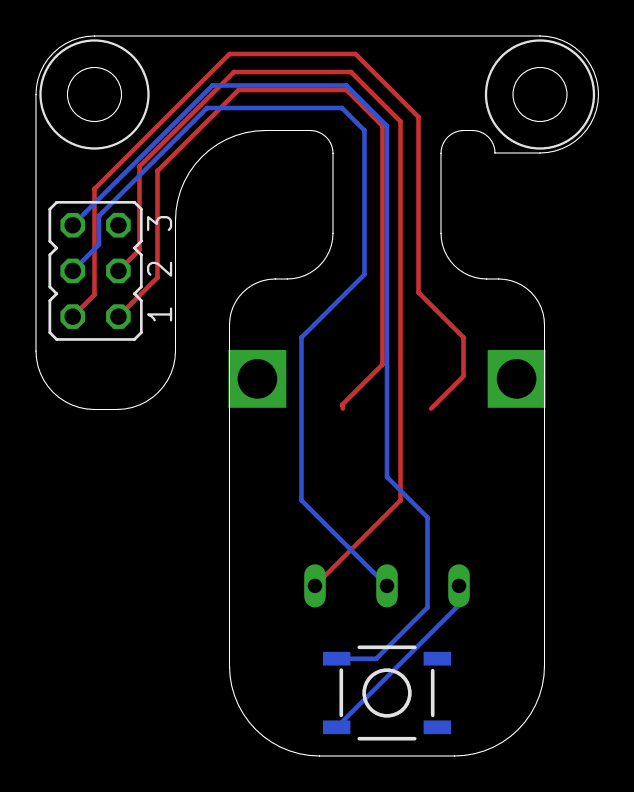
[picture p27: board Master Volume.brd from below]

Board: 2 copper layers, 31.2 x 40.0 mm, 6 parts (2 on the bottom side), 6 nets.

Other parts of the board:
U$2, U$3: STANDOFF-M3

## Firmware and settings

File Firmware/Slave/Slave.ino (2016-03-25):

#include <math.h>

#include <Bounce.h>
#include <DMAChannel.h>
#include <SPI.h>
#include <UniWS.h>

#define USE_SERIAL 1
#define PRINT_STATS 0

// See synth-notes.txt for full information.
    // Teensy     Attributes        Use
    //  Pin        (subset)
    //   0                          choice button
    //   1                          destination button 3
    //   2                          destination button 4
    //   3        PWM               choice LED 1
    //   4        PWM               choice LED 2
    //   5        20mA              destination button 1
    //   6        PWM               choice LED 3
    //   7        MOSI0             destination button 2
    //   8        MISO0             assign button
    //   9        PWM               choice LED 4
    //  10        PWM,CS0           SPI
    //  11        MOSI0             SPI
    //  12        MISO0             SPI
    //  13        SCK0,LED          SPI
    //  14/A0     ADC,SCK0          knob wiper 1
    //  15/A1     ADC               knob wiper 2
    //  16/A2     ADC,PWM,20mA      knob wiper 3
    //  17/A3     ADC,PWM,5V,20mA   WS2812 strand
    //  18/A4     ADC               knob wiper 4
    //  19/A5     ADC               knob wiper 5
    //  20/A6     ADC,PWM           choice LED 5
    //  21/A7     ADC,20mA           -
    //  22/A8     ADC,PWM           choice LED 6
    //  23/A9     ADC,PWM           assign LED
    //  24/A10    ADC                -
    //  25/A11    ADC                -
    //  26/A12    ADC                -

const int CHOICE_BUTTON_pin =  0;
const int CHOICE_LED_1_pin  =  3;
const int CHOICE_LED_2_pin  =  4;
const int CHOICE_LED_3_pin  =  6;
const int CHOICE_LED_4_pin  =  9;
const int CHOICE_LED_5_pin  = 20;
const int CHOICE_LED_6_pin  = 22;
const int ANALOG_1_pin      = 14;
const int ANALOG_2_pin      = 15;
const int ANALOG_3_pin      = 16;
const int ANALOG_4_pin      = 18;
const int ANALOG_5_pin      = 19;
const int DEST_BUTTON_1_pin =  5;
const int DEST_BUTTON_2_pin =  7;
const int DEST_BUTTON_3_pin =  1;
const int DEST_BUTTON_4_pin =  2;
const int ASSIGN_BUTTON_pin =  8;
const int ASSIGN_LED_pin    = 23;
const int SPI_CS_pin        = 10;

const uint8_t  STX = '\02';
const uint8_t  ETX = '\03';
const uint8_t  SYN = '\26';

const size_t   MSG_MAX = 32;
const size_t   MAX_PIXELS = 6;
const size_t   MAX_ANALOGS = 5;
const int      DEBOUNCE_MSEC = 5;
const uint32_t SPI_TIMEOUT_MSEC = 1500;

const int analog_pins[] = {
    ANALOG_1_pin,
    ANALOG_2_pin,
    ANALOG_3_pin,
    ANALOG_4_pin,
    ANALOG_5_pin,
};
static const size_t analog_count = (&analog_pins)[1] - analog_pins;

static const uint8_t dest_button_pins[] = {
    DEST_BUTTON_1_pin,
    DEST_BUTTON_2_pin,
    DEST_BUTTON_3_pin,
    DEST_BUTTON_4_pin,
};
static const size_t dest_button_count =
    (&dest_button_pins)[1] - dest_button_pins;

typedef uint8_t message_buf[MSG_MAX];

typedef struct LED_state {
    uint8_t pin;
    uint8_t value;
} LED_state;

Bounce c_button(CHOICE_BUTTON_pin, DEBOUNCE_MSEC);
Bounce k1_button(DEST_BUTTON_1_pin, DEBOUNCE_MSEC);
Bounce k2_button(DEST_BUTTON_2_pin, DEBOUNCE_MSEC);
Bounce k3_button(DEST_BUTTON_3_pin, DEBOUNCE_MSEC);
Bounce k4_button(DEST_BUTTON_4_pin, DEBOUNCE_MSEC);
Bounce a_button(ASSIGN_BUTTON_pin, DEBOUNCE_MSEC);

LED_state a_led  = { ASSIGN_LED_pin,   0 };
static LED_state choice_LEDs[] = {
    { CHOICE_LED_1_pin, 0},
    { CHOICE_LED_2_pin, 0},
    { CHOICE_LED_3_pin, 0},
    { CHOICE_LED_4_pin, 0},
    { CHOICE_LED_5_pin, 0},
    { CHOICE_LED_6_pin, 0},
};
static const size_t choice_LED_count = (&choice_LEDs)[1] - choice_LEDs;
UniWS LED_strand(MAX_PIXELS);
uint16_t analog_values[MAX_ANALOGS];
DMAChannel SPI_rx_dma;
DMAChannel SPI_tx_dma;

Bounce *const buttons[] = {
    &c_button,
    &a_button,
    &k1_button,
    &k2_button,
    &k3_button,
    &k4_button,
};
const size_t button_count = sizeof buttons / sizeof buttons[0];

message_buf recv_buf, send_buf;

#if PRINT_STATS

typedef struct analog_stats {
    uint32_t x;
    uint64_t x2;
    uint32_t n;
    uint16_t min;
    uint16_t max;
} analog_stats;

typedef struct stat {
    uint32_t start_time;
    uint32_t stop_time;
    analog_stats astats[MAX_ANALOGS];
} stat;

stat stats;

#endif /* PRINT_STATS */

#if USE_SERIAL

static bool serial_is_up;

static void begin_serial()
{
    int i;
    const int limit = 5000000;

    Serial.begin(9600);
    for (i = 0; i < limit && !Serial; i++)
        continue;
    if (i < limit) {
        serial_is_up = true;
        Serial.printf("Hello from Slave: %d\n", i);
    }
}

#define SERIAL_PRINTF(...) \
    (serial_is_up && Serial.printf(__VA_ARGS__))

#else

static void begin_serial() {}

#define SERIAL_PRINTF(fmt, ...) (0)

#endif

static void begin_slave()
{
    // Route clock.
    SIM_SCGC4 |= SIM_SCGC4_SPI0;

    // Enable pins.
    CORE_PIN10_CONFIG =                PORT_PCR_MUX(2); // CS0   = 10 (PTC4)
    CORE_PIN11_CONFIG = PORT_PCR_DSE | PORT_PCR_MUX(2); // MOSI0 = 11 (PTC6)
    CORE_PIN12_CONFIG =                PORT_PCR_MUX(2); // MISO0 = 12 (PTC7)
    CORE_PIN13_CONFIG = PORT_PCR_DSE | PORT_PCR_MUX(2); // SCK0  = 13 (PTC5)
}

static size_t do_transfer(uint8_t       *receive_buffer, size_t receive_count,
                          uint8_t const *send_buffer,    size_t send_count,
                          uint32_t       timeout_msec)
{
    uint32_t timeout_abs_msec = millis() + timeout_msec;

    // Disable SPI to reset to idle state.
    SPI0_C1 = 0;

    // Initialize SPI
    SPI0_C1 = SPI_C1_CPHA;
    SPI0_C2 = SPI_C2_RXDMAE | SPI_C2_TXDMAE;
    SPI0_ML = ETX;

    SPI_rx_dma.clearComplete();
    SPI_rx_dma.disableOnCompletion();
    SPI_rx_dma.source(SPI0_DL);
    SPI_rx_dma.destinationBuffer(receive_buffer, receive_count);
    SPI_rx_dma.triggerAtHardwareEvent(DMAMUX_SOURCE_SPI0_RX);
    SPI_rx_dma.enable();

    SPI_tx_dma.clearComplete();
    SPI_tx_dma.disableOnCompletion();
    SPI_tx_dma.sourceBuffer(send_buffer, send_count);
    SPI_tx_dma.destination(SPI0_DL);
    SPI_tx_dma.triggerAtHardwareEvent(DMAMUX_SOURCE_SPI0_TX);
    SPI_tx_dma.enable();

    // Wait for falling edge on SPI CS pin.
    while (digitalRead(SPI_CS_pin) != HIGH)
        if ((int32_t)(timeout_abs_msec - millis()) < 0)
            return 0;
    while (digitalRead(SPI_CS_pin) == HIGH)
        if ((int32_t)(timeout_abs_msec - millis()) < 0)
            return 0;

    // Enable SPI.
    SPI0_C1 |= SPI_C1_SPE;

    // Wait for rising edge on SPI CS pin.
    while (digitalRead(SPI_CS_pin) != HIGH)
        if ((int32_t)(timeout_abs_msec - millis()) < 0)
            return 0;

    // Disable SPI.
    SPI0_C1 = 0;

    // Disable DMA.
    SPI_rx_dma.disable();
    SPI_tx_dma.disable();
    size_t ri = (uint8_t *)SPI_rx_dma.destinationAddress() - receive_buffer;
    return ri;
}

static uint16_t fletcher16(const uint8_t *buf, size_t count)
{
    uint16_t sum0 = 0, sum1 = 0;
    for (size_t i = 0; i < count; i++) {
        sum0 += buf[i];
        if (sum0 >= 255)
            sum0 -= 255;
        sum1 += sum0;
        if (sum1 >= 255)
            sum1 -= 255;
    }
    return sum1 << 8 | sum0;
}

namespace {                     // declare these functions in an
                                // unnamed namespace to thwart the
                                // stupid Arduino source mangler.

    static bool message_valid(const message_buf buf, size_t count)
    {
        if (count < 6) {
            SERIAL_PRINTF("count too short: %u < 6\n", count);
            return false;
        }

        if (buf[0] != STX) {
            SERIAL_PRINTF("first byte is %#o, not STX\n", buf[0]);
            return false;
        }

        uint8_t cfg0 = buf[1];
        uint8_t cfg1 = buf[2];
        uint8_t pixel_count = cfg1 & 0x07;
        uint8_t analog_count = (cfg1 >> 3) & 0x07;
        if (pixel_count > MAX_PIXELS || analog_count > MAX_ANALOGS) {
            SERIAL_PRINTF("pixel_count = %d, analog_count = %d\n",
                          pixel_count, analog_count);
            return false;
        }
        size_t len = 6;    // minimal message: STX cfg cfg chk chk ETX
        for (uint8_t bit = 1; bit; bit <<= 1)
            if (cfg0 & bit)
                len++;           // one byte per PWM LED
        len += 3 * (cfg1 & 0x7); // three bytes per pixel
        if (len > MSG_MAX) {
            SERIAL_PRINTF("len = %d\n", len);
            return false;
        }

        if (count < len) {
            SERIAL_PRINTF("short message: %u < %u\n", count, len);
            return false;
        }

        if (buf[len - 1] != ETX) {
            SERIAL_PRINTF("buf[%d - 1] = \\%03o != ETX\n", len, buf[len - 1]);
            return false;
        }
        uint16_t rx_chk = (uint16_t)buf[len - 3] << 8 | buf[len - 2];
        uint16_t cc_chk = fletcher16(buf + 1, len - 4);
        if (rx_chk != cc_chk) {
            SERIAL_PRINTF("chk: got %#x, wanted %#x\n", rx_chk, cc_chk);
            SERIAL_PRINTF("    len = %u\n", len);
            for (size_t i = 0; i < len; i++)
                SERIAL_PRINTF("    %3d: %d\n", i, buf[i]);
            return false;
        }

        return true;
    }

    static void update_LED(LED_state *lp, uint8_t new_value)
    {
        if (lp->value != new_value) {
            analogWrite(lp->pin, new_value);
            lp->value = new_value;
        }
    }
};

uint8_t condition(uint16_t raw, uint8_t expected)
{
    const int buffer = 3;

    uint8_t c = raw * (128 + buffer) >> 16;
    if (c >= expected && c <= expected + buffer)
        return expected;
    if (c < expected)
        return c;
    else {
        if (c < buffer)
            return 0;
        return c - buffer;
    }
}

static uint8_t update_analog(uint8_t index, uint8_t **pptr)
{
    int raw_value = analogRead(analog_pins[index]);
    int old_value = analog_values[index];
    
#if PRINT_STATS
    uint32_t now = millis();
    if (now >= stats.start_time && now < stats.stop_time) {
        analog_stats *astats = &stats.astats[index];
        if (astats->min > raw_value)
            astats->min = raw_value;
        if (astats->max < raw_value)
            astats->max = raw_value;
        astats->x += raw_value;
        astats->x2 += (uint32_t)raw_value * (uint32_t)raw_value;
        astats->n++;
    }
#endif /* PRINT_STATS */

    uint8_t new_value = condition(raw_value, old_value);
    if (new_value != old_value) {
        analog_values[index] = new_value;
        *(*pptr)++ = new_value;
        return 1 << index;
    }
    return 0;
}

static void print_buf(const char *label, const uint8_t *buf, size_t count)
{
    SERIAL_PRINTF("%s", label);
    for (size_t i = 0; i < count; i++) {
        uint8_t c = buf[i];
        if (c == STX)
            SERIAL_PRINTF(" STX");
        else if (c == ETX)
            SERIAL_PRINTF(" ETX");
        else if (c == SYN)
            SERIAL_PRINTF(" SYN");
        // else if (c >= ' ' && c < '\177')
        //     SERIAL_PRINTF(" %c", c);
        else
            SERIAL_PRINTF(" \\%03o", c);
    }
    SERIAL_PRINTF("\n");
}

static uint8_t biramp(uint32_t i, uint32_t n)
{
    if (i >= n/2)
        i = n - i - 1;
    if (i >= n/2)
        return 0;
    return i * 255 / (n/2 - 1);
}

static void self_test_loop()
{
    static uint32_t t;
    uint32_t now = millis();

    if ((int32_t)(t - now) > 0)
        return;
    t += 10;                    // 100 Hz loop

    // Choice buttons step 2 Hz.
    uint8_t choice = now / 500 % choice_LED_count;
    uint8_t choice_level = biramp(now % 500, 500);
    bool cb_down = digitalRead(CHOICE_BUTTON_pin) == LOW;
    for (size_t i = 0; i < choice_LED_count; i++)
        if (cb_down)
            update_LED(&choice_LEDs[i], 10);
        else
            update_LED(&choice_LEDs[i], (choice == i) * choice_level);

    // Assign button blink 10 Hz.
    uint8_t assign_level = biramp(now % 100, 100);
    bool ab_down = digitalRead(ASSIGN_BUTTON_pin) == LOW;
    if (ab_down)
        update_LED(&a_led, 10);
    else
        update_LED(&a_led, assign_level);

    // Strand cycles through R, G, B, 1/6 Hz.
    uint32_t npix = LED_strand.numPixels();
    uint32_t pt = now % 6000;
    uint8_t  component = pt / 2000;
    uint32_t  pixel = pt % 2000 / (2000 / npix);
    uint8_t  level = biramp(pt % (2000 / npix), 2000 / npix);

    for (uint32_t i = 0; i < npix; i++) {
        bool db_down = ((i - 1) < dest_button_count &&
                        digitalRead(dest_button_pins[i - 1]) == LOW);
        uint16_t analog = ((i - 1) < analog_count
                           ? analogRead(analog_pins[i - 1])
                           : 0);
        uint8_t pix_level = 0;
        if (db_down)
            pix_level = 63;
        else if (pixel == i)
            pix_level = level;
        uint8_t primary_level = pix_level * (65535 - (uint32_t)analog) / 65535;
        uint8_t secondary_level = pix_level * (uint32_t)analog / 65535;
        uint8_t r = (component == 0) ? primary_level : secondary_level;
        uint8_t g = (component == 1) ? primary_level : secondary_level;
        uint8_t b = (component == 2) ? primary_level : secondary_level;
        LED_strand.setPixel(i, r, g, b);
    }
    LED_strand.show();
}

void setup()
{
    begin_serial();

    pinMode(CHOICE_BUTTON_pin, INPUT_PULLUP);
    pinMode(DEST_BUTTON_1_pin, INPUT_PULLUP);
    pinMode(DEST_BUTTON_2_pin, INPUT_PULLUP);
    pinMode(DEST_BUTTON_3_pin, INPUT_PULLUP);
    pinMode(DEST_BUTTON_4_pin, INPUT_PULLUP);
    pinMode(ASSIGN_BUTTON_pin, INPUT_PULLUP);
    
    analogReadResolution(16);

    LED_strand.begin();

    begin_slave();

    // Initialize to empty message.
    memset(send_buf, SYN, sizeof send_buf);
}

void loop()
{
    static uint32_t alive_time;
    uint32_t timeout_msec = SPI_TIMEOUT_MSEC;
    if ((int32_t)(millis() - alive_time) > (int32_t)timeout_msec)
        timeout_msec = 10;

    size_t receive_count = do_transfer(recv_buf, MSG_MAX,
                                       send_buf, MSG_MAX,
                                       timeout_msec);
    // print_buf("received: ", recv_buf, MSG_MAX);
    if (receive_count == 0) {
        memset(send_buf, SYN, sizeof send_buf);
        if ((int32_t)(millis() - alive_time) >= SPI_TIMEOUT_MSEC)
            self_test_loop();
        return;
    }
    if (!message_valid(recv_buf, receive_count)) {
        SERIAL_PRINTF("invalid message received\n");
        print_buf("received: ", recv_buf, MSG_MAX);
        memset(send_buf, SYN, sizeof send_buf);
        return;
    }
    alive_time = millis();

    uint8_t cfg0 = recv_buf[1];
    uint8_t cfg1 = recv_buf[2];
    const uint8_t *rx_ptr = recv_buf + 3;

    // Update the PWM LEDs
    for (uint8_t i = 0; i < choice_LED_count; i++)
        update_LED(&choice_LEDs[i], cfg0 & (1 << i) ? *rx_ptr++ : 0);
    update_LED(&a_led,  cfg0 & (1 << 7) ? *rx_ptr++ : 0);

    // Update the pixels.
    int pixel_count = cfg1 & 0x07;
    if (pixel_count) {
        LED_strand.clear();
        for (int i = 0; i < pixel_count; i++) {
            uint8_t r = *rx_ptr++;
            uint8_t g = *rx_ptr++;
            uint8_t b = *rx_ptr++;
            // SERIAL_PRINTF("  LED %d = %x %x %x\n", i, r, g, b);
            LED_strand.setPixel(i, r, g, b);
        }
        LED_strand.show();
    }

    uint8_t *tx_ptr = send_buf + 3;

    // Read analog inputs.
    uint8_t analog_mask = 0;
    int analog_count = (cfg1 >> 3) & 0x07;
    for (int i = 0; i < analog_count; i++)
        analog_mask |= update_analog(i, &tx_ptr);

    // Read buttons.
    uint8_t switch_mask = 0;
    for (size_t i = 0; i < button_count; i++) {
        Bounce *b = buttons[i];
        if (b->update() && b->fallingEdge())
            switch_mask |= 1 << i;
    }

    // compose outgoing message.
    send_buf[0] = STX;
    send_buf[1] = switch_mask;
    send_buf[2] = analog_mask;
    uint16_t chk = fletcher16(send_buf + 1, tx_ptr - send_buf - 1);
    *tx_ptr++ = chk >> 8;
    *tx_ptr++ = chk & 0xFF;
    *tx_ptr++ = ETX;
    while (tx_ptr < send_buf + MSG_MAX)
        *tx_ptr++ = SYN;

#if PRINT_STATS
    if (alive_time >= stats.stop_time) {
        for (size_t i = 0; i < MAX_ANALOGS; i++) {
            analog_stats *astats = &stats.astats[i];
            if (!astats->n)
                continue;

            uint64_t x = astats->x;
            uint64_t x2 = astats->x2;
            uint64_t n = astats->n;
            uint32_t mean = x / n;
            float stddev = sqrt(n * x2 - x * x) / n;
            uint32_t idev = stddev * 100;

            SERIAL_PRINTF("%u: n=%u min=%d max=%d mean=%d dev=%d.%02d\n",
                          i,
                          astats->n, astats->min, astats->max,
                          mean, idev / 100, idev % 100);
            astats->x = astats->x2 = astats->n = astats->max = 0;
            astats->min = UINT16_MAX;
        }
        SERIAL_PRINTF("\n");
        stats.start_time = millis() + 100;
        stats.stop_time = stats.start_time + 10000;
    }
#endif /* PRINT_STATS */
}

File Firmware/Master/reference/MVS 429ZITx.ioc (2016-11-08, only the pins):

Mcu.UserName=STM32F429ZITx
PA0/WKUP.GPIO_Label=Button 1
PA0/WKUP.Signal=GPIO_Input
PA10.Signal=USART1_RX
PA11.Signal=LTDC_R4
PA12.Signal=LTDC_R5
PA13.Signal=SYS_JTMS-SWDIO
PA14.Signal=SYS_JTCK-SWCLK
PA3.Signal=LTDC_B5
PA4.Signal=LTDC_VSYNC
PA5.Signal=SPI1_SCK
PA6.Signal=LTDC_G2
PA7.Signal=SPI1_MOSI
PA8.Signal=I2C3_SCL
PA9.Signal=USART1_TX
PB0.Signal=LTDC_R3
PB1.Signal=LTDC_R6
PB10.Signal=LTDC_G4
PB11.Signal=LTDC_G5
PB12.Signal=USB_OTG_HS_ID
PB13.Signal=USB_OTG_HS_VBUS
PB14.Signal=USB_OTG_HS_DM
PB15.Signal=USB_OTG_HS_DP
PB3.Signal=SPI3_SCK
PB4.Signal=SPI1_MISO
PB5.Signal=FMC_SDCKE1
PB6.Signal=FMC_SDNE1
PB7.GPIO_Label=SPI group A CS
PB7.Signal=GPIO_Output
PB8.Signal=LTDC_B6
PB9.Signal=LTDC_B7
PC0.Signal=FMC_SDNWE
PC1.GPIO_Label=HIGH disable L3G20
PC1.Signal=GPIO_Output
PC10.Signal=LTDC_R2
PC11.Signal=SPI3_MISO
PC12.Signal=SPI3_MOSI
PC2.GPIO_Label=HIGH disable int LCD
PC2.Signal=GPIO_Output
PC3.GPIO_Label=SPI group C CS
PC3.Signal=GPIO_Output
PC4.GPIO_Label=USB_OTG_HS_PSO
PC4.Signal=GPIO_Output
PC5.GPIO_Label=USB_OTG_HS_OC
PC5.Signal=GPIO_Input
PC6.Signal=LTDC_HSYNC
PC7.Signal=LTDC_G6
PC8.GPIO_Label=SPI group D CS
PC8.Signal=GPIO_Output
PC9.Signal=I2C3_SDA
PD0.Signal=FMC_D2_DA2
PD1.Signal=FMC_D3_DA3
PD10.Signal=FMC_D15_DA15
PD14.Signal=FMC_D0_DA0
PD15.Signal=FMC_D1_DA1
PD3.Signal=LTDC_G7
PD6.Signal=LTDC_B2
PD8.Signal=FMC_D13_DA13
PD9.Signal=FMC_D14_DA14
PE0.Signal=FMC_NBL0
PE1.Signal=FMC_NBL1
PE10.Signal=FMC_D7_DA7
PE11.Signal=FMC_D8_DA8
PE12.Signal=FMC_D9_DA9
PE13.Signal=FMC_D10_DA10
PE14.Signal=FMC_D11_DA11
PE15.Signal=FMC_D12_DA12
PE2.Signal=SPI4_SCK
PE3.GPIO_Label=SPI group B CS
PE3.Signal=GPIO_Output
PE4.GPIO_Label=LCD On/Off
PE4.Signal=GPIO_Output
PE5.Signal=SPI4_MISO
PE6.Signal=SPI4_MOSI
PE7.Signal=FMC_D4_DA4
PE8.Signal=FMC_D5_DA5
PE9.Signal=FMC_D6_DA6
PF0.Signal=FMC_A0
PF1.Signal=FMC_A1
PF10.Signal=LTDC_DE
PF11.Signal=FMC_SDNRAS
PF12.Signal=FMC_A6
PF13.Signal=FMC_A7
PF14.Signal=FMC_A8
PF15.Signal=FMC_A9
PF2.Signal=FMC_A2
PF3.Signal=FMC_A3
PF4.Signal=FMC_A4
PF5.Signal=FMC_A5
PF6.GPIO_Label=LCD PWM
PF6.Signal=S_TIM10_CH1
PF7.Signal=SPI5_SCK
PF8.Signal=SPI5_MISO
PF9.Signal=SPI5_MOSI
PG0.Signal=FMC_A10
PG1.Signal=FMC_A11
PG10.Signal=LTDC_G3
PG11.Signal=LTDC_B3
PG12.Signal=LTDC_B4
PG13.GPIO_Label=LED Green
PG13.Signal=GPIO_Output
PG14.GPIO_Label=LED red
PG14.Signal=GPIO_Output
PG15.Signal=FMC_SDNCAS
PG4.Signal=FMC_A14_BA0
PG5.Signal=FMC_A15_BA1
PG6.Signal=LTDC_R7
PG7.Signal=LTDC_CLK
PG8.Signal=FMC_SDCLK
PH0/OSC_IN.Signal=RCC_OSC_IN
PH1/OSC_OUT.Signal=RCC_OSC_OUT

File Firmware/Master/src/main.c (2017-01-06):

#include <stdio.h>
#include <string.h>

#include <libopencm3/stm32/rcc.h>

#include "button.h"
#include "console.h"
#include "delay.h"
#include "lcd-dma.h"
#include "lcd-pwm.h"
#include "midi.h"
#include "sdram.h"
#include "spi.h"
#include "spi-proto.h"
#include "spi-responder.h"
#include "state.h"
#include "systick.h"
#include "usb-midi.h"

#define REPORT_INTERVAL_MSEC 10000

#define CPU_FREQ 168000000
// #define CPU_FREQ 120000000
// #define CPU_FREQ 48000000

static void clock_setup(void)
{
    if (CPU_FREQ == 168000000) {
        // CPU = 168 MHz, min SPI =~ 328 KHz
        rcc_clock_setup_hse_3v3(&rcc_hse_8mhz_3v3[RCC_CLOCK_3V3_168MHZ]);
    } else if (CPU_FREQ == 120000000) {
        // CPU = 120 MHz, min SPI =~ 234 KHz
        rcc_clock_setup_hse_3v3(&rcc_hse_8mhz_3v3[RCC_CLOCK_3V3_120MHZ]);
    } else if (CPU_FREQ == 48000000) {
        // CPU = 48 MHz, min SPI =~ 94 KHz
        rcc_clock_setup_hse_3v3(&rcc_hse_8mhz_3v3[RCC_CLOCK_3V3_48MHZ]);
    }
}

static void adjust_LCD_brightness(uint32_t now)
{
    static bool done;
    if (done)
        return;
    static uint32_t t0;
    if (!t0) {
        t0 = now + 1;
        return;
    }
    uint32_t b0 = (now - t0);
    uint32_t b1 = b0 * (b0 + 1) >> 5;
    if (b1 > 65535) {
        b1 = 65535;
        done = true;
    }
    lcd_pwm_set_brightness(b1);
}

int main()
{
    clock_setup();
    systick_setup(CPU_FREQ);
    lcd_pwm_setup(); // Do this early to keep the uninitialized screen dark.
    console_setup();
    console_stdio_setup();
    MIDI_setup();
    usb_midi_setup();
    button_setup();
    spi_setup();
    SPI_proto_setup();
    SPI_responder_setup();
    sdram_setup();
    lcd_dma_setup();
    init_delay(CPU_FREQ);

    printf("\n");
    printf("Minimum Viable Firmware\n");

#ifndef NDEBUG
    verify_config();
    printf("OK\n");
#endif

    uint32_t next_time = REPORT_INTERVAL_MSEC;

    while (1) {
        adjust_LCD_brightness(system_millis);
        usb_midi_poll();
        button_poll();

        if ((int32_t)(next_time - system_millis) > 0)
            continue;
        next_time += REPORT_INTERVAL_MSEC;

        SPI_proto_report_and_clear_stats();
        // USB_midi_report_and_clear_stats();
    }
    return 0;
}

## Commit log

2014-11-19 Minimum Viable Synth. Mostly works. Some parameters' scales are wrong.
    [main.cpp]
2014-11-19 Implement velocity, fixup parameters.
    [main.cpp]
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2014-11-29 New oscillator uses 3rd order polyBLEP and 1st order polyBLAM for antialiasing, implements FM. Saw and Triangle are separate waveforms now. The synth does not yet implement FM or Triangle.
    [main.cpp]
2014-12-04 Added noise and noise envelope. White, pink, and red.
    [main.cpp]
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2014-12-31 Tweaked parameter limits to play better with AU Lab's MIDI interface. I think AU Lab is wrong, but I'll conform anyway.
    [main.cpp]
2015-01-02 The infamous Ladder Filter is in. Low pass works, high pass is implemented according to Vadim Zavalishin's design, but doesn't sound very convincing. The other two modes are not implemented.
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2015-05-29 Imported Eagle CAD files. They probably don't build in this environment.
    [DRILEGEND.CFG, LFO Small 1.0.brd, LFO Small 1.0.sch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]
2015-05-29 Removed external Eagle library dependencies.
    [LFO Small.brd, LFO Small.sch]
2015-05-29 Checked in the LFO substrate mechanical CAD drawing.
    [LFO substrate.scad]
2015-05-31 Moved 'LFO Small 1.0' files (the ones actually fabricated) to archive/.
    [LFO Small 1.0.brd, LFO Small 1.0.sch]
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2015-05-31 Everything.sch - a template module schematic with the union of all circuits
    [Everything.sch]
2015-05-31 Schematic for the filter board. Compressed to fit within freeware Eagle's dimensions.
    [Filter.brd, Filter.sch]
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2015-05-31 Fixed a skewed wire.
    [Everything.sch, Filter.sch]
2015-05-31 Two more PCBs: Oscillator and Duo (the two-control board).
    [Duo.brd, Duo.sch, Oscillator.brd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]
2015-05-31 Renamed "LFO Small" to "LFO". There is no longer an "LFO Large".
    [LFO.brd, LFO.sch]
2015-05-31 ... still renaming "LFO Small" to "LFO".
    [LFO Small.brd]
2015-05-31 Moved the LED bar graphs' color labels to the silkscreen layer.
    [Filter.brd, Oscillator.brd, Oscillator.sch]
2015-05-31 Cleaned up board outline.
    [Oscillator.brd]
2015-05-31 Starting to design the envelope control boards
    [Envelope.brd, Envelope.sch]
2015-05-31 This is the filter board, with the controls spaced out to the right positions.
    [Filter Big.brd, Filter Big.sch]
2015-05-31 No longer ignore Filter Big.brd. It is now human-generated.
2015-05-31 1.0 versions of the Filter, Oscillator, and Duo boards sent to OSHPark and archived.
    [Duo 1.0.brd, Duo 1.0.sch, Filter Big 1.0.brd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]
2015-06-01 Designed the Envelope board. Fairly straightforward, except that it has three variants.
    [Envelope.brd, Envelope.sch]
2015-06-01 The Master Volume mini-board.
    [Master Volume.brd, Master Volume.sch]
2015-06-01 Envelope and Master Volume 1.0 archived and sent to fab.
    [Envelope 1.0.brd, Envelope 1.0.sch, Master Volume 1.0.brd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]
2015-06-01 LFO substrate: more clearance around SPI header, single top clip, strain relief in spine.
    [LFO substrate.scad]
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2015-06-14 Fixed lots of issues found in first fabricated boards. - highlighted the cutoff knob - made the filter envelope arrow swoopy - made all cut lines 0.001 pt. wide - outlined edges of all engraved areas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
2015-06-21 Variant LFO substrate is thicker to clear power jumpers.
    [LFO substrate thick.scad]
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2015-08-18 Wrote a configuration verifier. Found and fixed some mistakes.
    [main.c]
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2015-11-30 Fixed stupid bug in Fletcher-16 checksum.
    [spi-proto.c]
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2015-12-22 Designed substrates to hold up several slave boards.
    [Filter substrate thick.scad, Noise substrate thick.scad, Osc substrate thick.scad]
2015-12-22 Added strain relief slots to the filter substrate.
    [Filter substrate thick.scad]
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2015-12-22 Tweaked clearance for Teensy.
    [Filter substrate thick.scad, LFO substrate thick.scad, Noise substrate thick.scad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]
2016-01-17 Made all the substrates thinner to make the box lower profile (24 mm).
    [Filter substrate.scad, Noise substrate.scad, Osc substrate.scad]
2016-01-17 OpenSCAD animation of how to assemble the parts.
    [assembly.scad]
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2016-01-17 Fixed sequence error with multiple SPI buses active.
    [spi-proto.c]
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2016-01-27 Made a plastic plug to fit in the end of the case.
    [endplug.scad]
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2016-02-06 Added plate to screw on end cap.
    [LFO substrate.scad]
2016-02-06 Keep tweaking geometry until it fits.
    [endplug.scad]
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2016-02-11 Slave self-test no longer leaves extra choice LEDs on.
    [Slave.ino]
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2016-02-17 Conditioned analog inputs to avoid spurious movement.
    [Slave.ino, spi-responder.c]
2016-02-22 Now software controls screen brightness, fixed another pin conflict.
    [console.c, lcd-dma.c, lcd-pwm.c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]
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2016-11-09 Moved module PCBs to ECAD/modules/.
    [DRILEGEND.CFG, Duo.brd, Duo.sch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]
2016-11-10 Started I/O Daughter Board. Collected data sheets.
    [io_daughterboard.kicad_pcb, io_daughterboard.sch]
2016-11-10 Moved I/O Daughter Board KiCad files into pcb subdirectory.
    [io_daughterboard.kicad_pcb, io_daughterboard.sch]
2016-11-11 Major components are in the schematic.
    [io_daughterboard.sch]
2016-11-12 annotated the P1 connector.
    [io_daughterboard.sch]
2016-11-12 Re-did a handful of wires on P1.
    [io_daughterboard.sch]
2016-11-12 Tweaked P1 pins 1-16.
    [io_daughterboard.sch]
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2016-11-13 Added pushbuttons and MIDI 5V interface.
    [IGS-430182043816-rev1.igs, STEP-430182043816-rev1.stp, io_daughterboard.sch]
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2016-11-13 Schematic: hooked up LCD connector.
    [io_daughterboard.sch]
2016-11-14 Schematic for backlight power supply drawn.
    [io_daughterboard.sch]
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2016-11-14 added slave connectors to schematic; laid out page.
    [io_daughterboard.sch]
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2016-11-16 Fixed 10 errors on schematic. Still no power flags.
    [io_daughterboard.sch]
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2016-11-18 Flipped board to make LCD right side up. Regenerated netlist with footprints.
    [io_daughterboard.kicad_pcb, io_daughterboard.sch]
2016-11-18 Dimensioned board for P1 and P2 connectors. Experimenting with different slave connectors.
    [io_daughterboard.kicad_pcb, io_daughterboard.sch]
2016-11-18 Changed values of slave connectors to "Slave 1A" etc.
    [io_daughterboard.sch]
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2016-11-21 P1 and P2 connectors placed. Back to PicoBlade through-hole connectors.
    [io_daughterboard.kicad_pcb, io_daughterboard.sch]
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2016-11-22 Moved BARREL_JACK and PicoBlade 4x1 footprints into local library.
    [io_daughterboard.sch]
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2016-11-22 Fixed 3D models, made power traces heavier, pulled pour back from board edge
    [io_daughterboard.kicad_pcb, io_daughterboard.sch]
2016-11-23 Try moving the SPI buffers around. Manually route bypass caps.
    [io_daughterboard.kicad_pcb]
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2016-11-23 Board autorouted, DRC and missing connections fixed.
    [io_daughterboard.kicad_pcb]
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2016-11-27 Added ground plane; thickened ground wires on bottom layer.
    [io_daughterboard.kicad_pcb]
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2016-11-28 Removed solder paste from R12 as it is optional.
    [io_daughterboard.kicad_pcb]
2016-11-29 Widened ground traces failed DRC.
    [io_daughterboard.kicad_pcb]
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2016-11-29 Switched connectors P1 and P2. Made traces for filter caps.
    [io_daughterboard.kicad_pcb]
2016-11-29 Re-routed board with P1/P2 corrected, added explicit ground-to-bypass traces.
    [io_daughterboard.kicad_pcb]
2016-11-29 Added ground plane; widened ground traces to slave connectors.
    [io_daughterboard.kicad_pcb]
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2016-11-30 Added 3D models for barrel jack, buttons, and MIDI connector.
    [io_daughterboard.kicad_pcb]
2016-12-17 Added XF2L connector's mechanical pads to solder paste layer.
    [io_daughterboard.kicad_pcb]
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2016-12-17 Changed solder mask clearance to 0.05 mm. (Grrr!)
    [io_daughterboard.kicad_pcb]
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2016-12-18 Fixed arrowhead.
    [io_daughterboard.kicad_pcb]
2016-12-18 Routed board. Same as always - no ground pour, three trace sizes.
    [io_daughterboard.kicad_pcb]
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2016-12-19 PCB and schematic had gotten out of sync. Now in sync.
    [io_daughterboard.kicad_pcb, io_daughterboard.sch]
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2016-12-19 Removed all traces and copper pours; reconnected filter caps.
    [io_daughterboard.kicad_pcb]
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2016-12-20 Added copper pours front and back for ground.
    [io_daughterboard.kicad_pcb]
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

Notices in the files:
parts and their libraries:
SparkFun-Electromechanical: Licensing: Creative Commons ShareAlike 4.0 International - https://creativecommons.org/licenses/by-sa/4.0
